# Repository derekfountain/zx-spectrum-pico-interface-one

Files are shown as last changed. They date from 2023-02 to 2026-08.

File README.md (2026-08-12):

# ZX Spectrum Expansion System, Recreated

**Update August'26:
Following recent interest in this project I've been
making a few interfaces up so people can buy them. The [project page](https://www.derekfountain.org/zses.php)
on [my personal website](https://www.derekfountain.org/) has the details
on how to get hold of one.**

**<derek@scratters.com>**

## An Interface One / Microdrive Emulation for the ZX Spectrum

This device plugs into the back of a 48K ZX Spectrum and provides the
functionality of the original 1984 "ZX Spectrum Expansion System". It
emulates a ZX Interface One with 8 ZX Microdrives.

The device is completely compatible with all 1980s software. It uses no
ROM modifications or other hacks. To my knowledge there are no
limitations or caveats to its use.

The first version is complete and supports the ZX Microdrives as
designed; the RS232 and ZX Net features of the Interface One might follow.

The project is open source, open hardware design, distributed under the
GPL licence.

There's lots more information on the [project page](https://www.derekfountain.org/zses.php)
on [my website](https://www.derekfountain.org/).

Click through for a brief demonstration:

IMAGE ALT TEXT (http://www.youtube.com/watch?v=kph2aS7qcVc "ZX Spectrum Expansion System, Recreated")

https://www.youtube.com/watch?v=kph2aS7qcVc

## Status

As of September 2023, version 1.0 is complete:

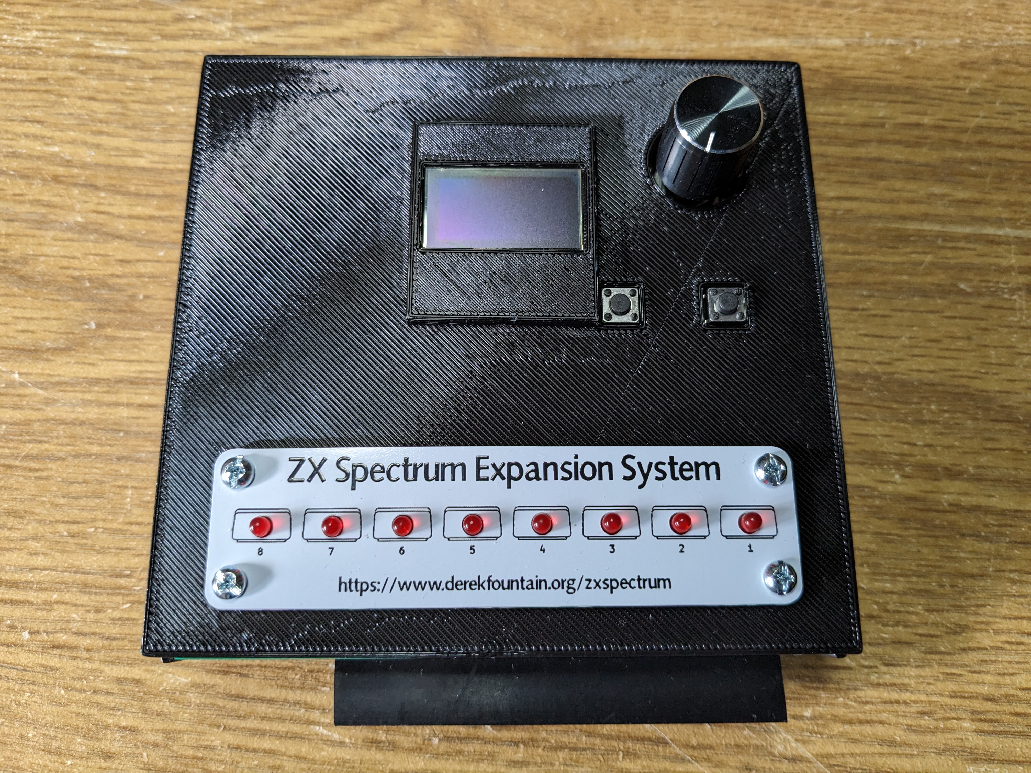
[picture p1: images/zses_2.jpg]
v1.0


It is functionally complete:

* Spectrum can read and write all 8 microdrives
* Uses "MDR" image format for "cartridges", fully compatible with emulators
* Full ZX Interface One ROM support, all native BASIC commands and extensions work as designed
* MDR files loaded from, and saved back to, SD card
* User interface uses file selector to choose and "insert" a cartridge
* Cartridge eject, allowing cartridges to be changed as required
* Configuration file allows auto-insertion of selected cartridges at start up

I'd be interested to receive feedback from anyone who tries to build one.

[Derek Fountain](https://www.derekfountain.org/), September 2023

# Operation

It should be fairly obvious. Select the Microdrive with the rotary encoder, click the right
button to bring up the file selector, use the rotary to select a cartridge file, then click the right button
again. The left button cancels.

The file selector only brings up files named *.mdr, and it doesn't do subdirectories. This
could be improved.

If you create a file in the root of your SD card called zxes_config.txt (that's not a
typo, I have an issue open to rename that file to match the rest of the project) and
enter up to 8 lines, each with a filename giving the name of an MDR file on your SD card,
those cartridge images will be loaded into the Microdrives on startup. (Startup meaning the
Pico startup, not the Spectrum start up.)

# Build Guidance

If you want to have a go at building one, please ensure you check out the open issues first.
There are a few, um, anomalies, which you might want to consider or work around. If I do
another spin of the boards I should be able to clear these up.

That said...

The KiCad files for the main board are in /srom/srom.kicad_pro. (The project started off as a port
of my [Spectrum Pico ROM](https://github.com/derekfountain/zx-spectrum-pico-rom), and the directory
name got ported over.)

The KiCad files for the top board (the daughter board with the screen and buttons) are in
/ui_daughterboard/ui_daughterboard.kicad_pro.

The silver faceplate is a (non functional) PCB. I had JLCPCB make it up in aluminium. The design
for that is in with the case design: /3d_print/top_panel/top_panel.kicad_pro.

All my surface mount component footprints are metric 3216 sized (1206i). Those are easy to hand solder.

The OLED screen needs a SSD1306 chipset if you want to use my code. Be careful, some SSH1106
based screens are labelled SSD1306. Those won't work without modifications to the code.

I've used long legged header sockets (female) to raise the top board well up above the Picos. If you
use the normal ones they probably won't be tall enough, unless you choose not to socket the Picos.

## Bill of Materials

You will need:

2x [74LVC245 Bus transceiver](https://www.mouser.co.uk/ProductDetail/595-SN74LVC245ANSR)
Bus transceiver, used as a level shifter
<br>
1x [3216 SMD Diode](https://www.mouser.co.uk/ProductDetail/581-SD1206S040S2R0)
Schottky Diode for Pico input protection
<br>
1x [4075 OR gate](https://www.mouser.co.uk/ProductDetail/595-SN74HCS4075DR)
3-way 3-input OR gate
<br>
4x [3216 SMD 0.1uF capacitor](https://www.mouser.co.uk/ProductDetail/581-12065C104KAT4A)
Decoupling capacitor
<br>
1x [PMBT2222A SMD Transistor](https://www.mouser.co.uk/ProductDetail/771-PMBT2222A-T-R)
NPN Transistor for /RESET
<br>
2x [3216 SMD 1K Resistor](https://www.mouser.co.uk/ProductDetail/603-RT1206FRE071KL)
1K Resistor for /RESET and /ROMCS2 pulldown
<br>
8x [3216 SMD 150R Resistor](https://www.mouser.co.uk/ProductDetail/603-RT1206FRE07150RL)
150R Resistor for data bus protection
<br>
1x [3216 SMD 330R Resistor](https://www.mouser.co.uk/ProductDetail/YAGEO/RT1206FRE07330RL)
330R Resistor for LED current limitation
<br>
1x [APS6404L-3SQR-PSRAM64Mbit Serial DRAM](https://www.mouser.co.uk/ProductDetail/878-APS6404L-3SQR-SN)
8MB SPI DRAM. A 1MB chip would probably be adequate.
<br>

Also, from your parts bin:

3x Raspberry Pi Pico with pins and sockets if you want them
<br>
1x 3-pin header and socket
<br>
1x 6-pin header and socket
<br>
1x 10-pin header and socket
<br>
1x KY-040 rotary encoder. Mine came with a 90degree header pin which I replaced with a straight header
<br>
1x 90degree ZX Spectrum Edge Connector socket. I went for [this one](https://www.ebay.co.uk/itm/394156247495).
<br>
2x SPST switch. Any single pole, single throw switch should do, they are the reset buttons.
<br>
1x Push-push type SD card reader. I used [this one](https://www.ebay.co.uk/itm/133222265884).
<br>
1x 0.96" OLED display (SSD1306 based)
<br>
8x 3.0mm red LEDs. The faceplate holes are drilled for 3.0mm LEDs.

# Acknowledgements

[Andrew Menadue](http://trochilidae.blogspot.com/)
for his Pico to Pico PIO [communications code](https://github.com/blackjetrock/picoputer),
and his patiently answering so many of my questions.

Geoff Wearmouth and others for their superb [IF1 ROM disassembly](https://www.derekfountain.org/misc/spectrum/if1_2.txt), which I suspect I now understand better than them.

Gergely Szasz, Philip Kendall and Stuart Brady from the
[FUSE Emulator Project](https://sourceforge.net/projects/fuse-emulator/).
[This](https://sourceforge.net/p/fuse-emulator/fuse/ci/master/tree/peripherals/if1.c)
one source file probably saved me weeks of work.

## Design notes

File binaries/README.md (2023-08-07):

# ZX Spectrum Expansion System, Recreated, Binaries

I had a couple of requests for pre-built UF2 files for the Picos.

This rather puzzled me since none of the code is any use without
the hardware, and I figured that anyone capable of building the
hardware would be capable of building the Pico's code.

No matter, I'm happy to provide them if people have a use for them.

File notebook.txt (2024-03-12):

ZX Spectrum Pico Interface One
==============================

Implement an Interface One using a Pico. Currently envisaged as a software only
microdrive emulator, providing a high volume storage facility the traditional
way. I wasn't planning doing an actual Microdrive emulation, or the network.

Pico-1 Emulates the IF1 ROM
===========================

Error Handling
--------------

The Service Manual says the Spectrum transfers to address 0x08 when it hits an
error. Putting a breakpoint on that address in Fuse shows it gets hit a various
points. Enter garbage and it gets hit when you'd expect to see the ? symbol come
up. It gets hit at the "D Break - CONT repeats" message. It seems to be the
standard error handler point.

0x08 is called via a RST 8 instruction. That's got CALL semantics, it PUSHes the
PC ready for a RET.

There's a disassembly of the IF1 ROM here: https://www.derekfountain.org/misc/spectrum/if1_2.txt

The IF1 hardware traps the address and Z80 lines when it goes to read an instruction from
address 0x08. Thus, when the ROM (or user program) calls that address the IF1 ROM is
already in place.

How does the ROM get paged?
---------------------------

Hardware looks for 0x0008.

AAAA AAAA AAAA AAAA
1111 1100 0000 0000
5432 1098 7654 3210

0000 0000 0000 1000
  *  *    ***   ***        Marked address lines are fed into IC3

That's bit A3 being one, all others being zero.

Also, hardware looks for 0x1708.

AAAA AAAA AAAA AAAA
1111 1100 0000 0000
5432 1098 7654 3210

0001 0111 0000 1000
  *  *    ***   ***        Marked address lines are fed into IC3

That's bit A3, A8, A9, A10 and A12 being one, all others being zero.

How does the ROM get unpaged?
-----------------------------

UNPAGE is at 0x0700 in the IF1 disassembly.

AAAA AAAA AAAA AAAA
1111 1100 0000 0000
5432 1098 7654 3210

0000 0111 0000 0000
  *  *    ***   ***        Marked address lines are fed into IC3

That's bits A8, A9 and A10 being one, all others being zero.

It contains a single RET instruction so the stack needs to have the required return
address ready. Assumption is that the IF1 ROM is unpaged when address 0x0700 has been
read. Not sure how.

From Kiwi at Spectrum Computing:

There are three addresses where the paging mechanism kicks in:

0x0008 - error RST - page in
0x1708 - channel handler - page in
0x0700 - page out

The LS260 NOR gates, diode AND gate and ULA decode these addresses
along with M1 and MREQ to determine when a paging event occurs. If you
decode all the other address bits then A3 indicates if the shadow ROM
should be paged in or out.

In hardware terms, the paging mechanism can be thought of as a two
stage process. The first stage flags if a paging event has occurred -
it decodes the address bits, MREQ and M1 and uses the signal as a
clock input to a LS74 flip flop, with A3 being the data input. The
second stage delays the actual paging of the ROM to the next
instruction. It does this with a second flip flop where the clock
input is the falling edge of M1 and data is the stage 1 page flag. The
combined mechanism recognises the page address and delays the ROM page
until the next M1 cycle (when it pages immediately).

This means that the CPU picks up the return instruction in the IF1 ROM
at 0x0700, executes the instruction (changing the PC), and the on CPU
setting up the address bus to get the instruction at the new PC
location, i.e. M1 active, the IF1 ROM pages out immediately meaning
the CPU picks up the value from the 48K ROM/RAM and normal execution
continues.

Pcio-1 Conclusion
-----------------

This is implemented in my ROM emulator. It requires the entire Pico,
all 26 GPIOs. The magic address ROM paging is done in software.

Proven working, final version needs the /M1 signal which I've got in
place on the schematic.

Pico-2 Emulates the IF1 Hardware
================================

Data Bus (8 GPIOs required)
---------------------------

8 lines required, all need level shifting and direction swapping. Input from ZX is needed
for the IF1 to receive the data to be written to the microdrive. Output to the ZX is
needed for the ROM emulation and to pass read data out to the ZX.

The ROM emulation only needs output data lines. The ROM emulator project ties the
direction of the level shifter to Pico->ZX. That needs changing because Pico-2 needs
to handle INs (Pico->ZX) and OUTs (ZX->Pico).

Z80 Control Bus (3 GPIOs required)
----------------------------------

The ROM part uses /MREQ; Pico-2 needs /IORQ.

/RD and /WR  are required so Pico-2 can tell when it needs to field an IN or an OUT.

Pico-1 only needs Pico->ZX, which is B->A, which is low on the pin. Pico-2 needs
both directions. But I can't have Pico-1 driving the data bus when Pico-2 wants
it, so I need to update the ROM emulation software to keep the data bus GPIOs as
inputs until they need to output their value.

The data bus level shifter should be permanently enabled. I'll tie /RD to the
shifter's direction pin then a read from ROM or a read of the IO space will set the
shifter to Pico->ZX, switching straight back when the read finishes. The ROM code
(Pico-1) needs to keep the data bus GPIOs as inputs while it's not supplying a data
byte. A write-to-ROM won't change the level shifter, so that scenario is harmless.
ROM_ACCESS_INV now appears redundant.

One issue: one of the Picos will have it's databus GPIOs set as outputs. When the
Z80's read finishes the /RD will go high and the level shifter will drive its
3V3 side as outputs. I don't want both Pico and level shifter driving each other,
but there's no easy alternative. So I'll put some resistors inline to prevent
too much current flowing from one device to the other. It'll only be brief, I
think it'll be OK.

Pico-3 Handles the user interface
=================================

Currently assuming an SD card reader and an LCD screen. Some buttons or a rotary?
Not sure. This comes later.

I think this is the one AM uses:

https://github.com/carlk3/no-OS-FatFS-SD-SPI-RPi-Pico/tree/sdio

How does Fuse code work?
========================

The Z80 opcode handler for IN uses a function called readport(). That's in periph.c, it loops
over a list of 'port' structures calling a function called read_peripheral(). That looks at
the list entry and the port being read by the Z80 and calls the handler function for either
a port read or a port write if the IN instruction the Z80 is running matches what's been
registered. The IF1's port input and output functions are if1_port_in() and if1_port_out():

static const periph_port_t if1_ports[] = {
  { 0x0018, 0x0010, if1_port_in, if1_port_out },
  { 0x0018, 0x0008, if1_port_in, if1_port_out },
  { 0x0018, 0x0000, if1_port_in, if1_port_out },
  { 0, 0, NULL, NULL }
};

Putting a breakpoint on one and doing a CAT 1 command gives:

(gdb) bt
#0  if1_port_in (port=24559, attached=0x7fffffffdc46 "") at peripherals/if1.c:787
#1  0x0000555555588aad in read_peripheral (data=<optimised out>, user_data=0x7fffffffdc44) at periph.c:304
#2  0x00007ffff7154b20 in g_slist_foreach () at /lib/x86_64-linux-gnu/libglib-2.0.so.0
#3  0x0000555555589057 in readport_internal (port=24559) at periph.c:344
#4  readport_internal (port=<optimised out>) at periph.c:312
#5  0x00005555555891a4 in readport (port=port@entry=24559) at periph.c:277
#6  0x00005555555ed965 in z80_do_opcodes () at ./z80/opcodes_base.c:944
#7  0x000055555558001d in main (argc=<optimised out>, argv=<optimised out>) at fuse.c:203

Decoding the port gives 1 of 3 responses:

static enum if1_port
decode_port( libspectrum_word port )
{
    switch( port & 0x0018 ) {
    case 0x0000: return PORT_MDR;
    case 0x0008: return PORT_CTR;
    case 0x0010: return PORT_NET;
        default: return PORT_UNKNOWN;
    }
}

0xF7 & 0x18 gives 0x10, so port 0xF7 is PORT_NET  (network)
0xEF & 0x18 gives 0x08, so port 0xEF is PORT_CTR  (control)
0xE7 & 0x18 gives 0x00, so port 0xE7 is PORT_MDR  (microdrive)

The one I want is the MDR one, so if1_port_in() for a read calls port_mdr_in(). Which 
is this:

static libspectrum_byte
port_mdr_in( void )
{
  libspectrum_byte ret = 0xff;
  int m;

  for( m = 0; m < 8; m++ ) {

    microdrive_t *mdr = &microdrive[ m ];

    if( mdr->motor_on && mdr->inserted ) {

      if( mdr->transfered < mdr->max_bytes ) {
	mdr->last = libspectrum_microdrive_data( mdr->cartridge,
						   mdr->head_pos );
	increment_head( m );
      }

      mdr->transfered++;
      ret &= mdr->last;  /* I assume negative logic, but how know? */
    }

  }

  return ret;
}

So for each microdrive, if it's on and inserted, read some data, increment the head
position. This seems to work with the idea that more than one microdrive can be
running, which is not possible in hardware as far as I know. Nevertheless, it merges
the bytes read from each device and that's what it returns. It also returns the next
byte in the data sequence (i.e on the tape) for each IN instruction.

I think what's happening is that each IN instruction is assumed to be reading the
next byte from the IF1 ULA. The IF1 does all the timing stuff, then says right,
/now/ is the time to read the next data byte from the stream. And that's what it
gets. In practise it doesn't matter what timing it puts in place, it'll get the next
byte in the stream regardless.

Logic to operate the level shifter
==================================

To switch the level shifter on the data bus to output mode (Pico->ZX) the ROM
read negative logic is

!(MREQ OR A14 OR A15 OR RD)

So if A14/5, or MREQ, or RD are high, keep it at input mode (ZX->Pico).
Otherwise pull it low (Pico->ZX).

So that's

(MREQ AND A14 AND A15 AND RD)

The IO Pico also needs to be able to switch that level shifter to output
mode (Pico->ZX)

(IORQ AND RD)

So if it's an IO, and it's a read, pull the level shifter direction low
(Pico->ZX).

So that's

!(IORQ OR RD)

/MREQ  A14  A15  DIR           /IORQ  /RD      DIR
  0     0    0    0               0    0        0         IO read (IN instruction)
  0     0    1    1               0    1        1         IO write (OUT instruction)
  0     1    0    1               1    0        1         Mem read
  0     1    1    1               1    1        1         Mem write
  1     0    0    1               
  1     0    1    1               
  1     1    0    1               
  1     1    1    1               

DIR = ( (MREQ OR A14 OR A15) AND (IORQ OR RD) )

gpios_state when broken on OUT 223,0     0x1C507A00
0b11100010100000111101000000000

  0 0000 1111 0000 0111 1111 0000 0000 = 0x00F07F00 is the mask
0b1 1100 1101 0000 0111 1010 0000 0000
         AAAA xxxx xAAA AWRI xxxx xxxx
         7654       321 0RDO
                           R

One clock cycle on 3.5MHz Z80 is 285ns. IORQ is down for 2.5 clocks, which is
about 715ns. That lines up perfectly with the scope trace.

Cartridge Loading
=================

Pico2
-----

typedef struct _md_flash_slot
{
  uint8_t                cartridge_present;
  libspectrum_microdrive cartridge;
}
MD_FLASH_SLOT;

On start up force empty slots. A new installation will set the 8 flash
slots with cartridge_present=0 and zeroes in the cartridge structure.
Pico3 can hold persistent MDR data and re-insert the last cartridges
used if necessary.

Like Fuse, start with everything empty, the UI Pico will need to load
MDR images, either through the GUI or via an auto-restore thing.

For test purposes, keep an MDR image in Pico2 flash. Load that into
slot 1 on startup. Need to check the "MD not present" thing works if
this is skipped, so might need a dummy image for loading into RAM.

On motor_on, load from slot 1 into RAM. For test, only use the first
slot (MD 1).

New cartridge takes a slot, 1 to 8, do whatever Fuse "Insert new" does.
I could save a new (unformatted) image in Fuse for this. Probably easier
to build what it wants in memory.

On motor_on, memcpy() from flash slot into RAM slot.
On motor_off, memcpy() from RAM back to flash slot.
 Fuse.

I don't think I can do automatic Pico2 flash back to Pico3 SD card.
It'd need doing on every sector write. So that leaves the Fuse model:
the user will have to choose Save for each cartridge image. Maybe
add a single button to save all cartridges back to SD.

* Insert new
* Insert
* Eject
* Save to SD card
* Save As to SD card
* Write protect enable/disable

The FORMAT Issue
================

Disassembly:

https://www.tablix.org/~avian/spectrum/rom/if1_2.htm#L1B5D

Start the motor, check for write protect.

https://www.tablix.org/~avian/spectrum/rom/if1_2.htm#L1B75

Enable writing - don't know what this does. Apparently nothing.

Creates an unuable record: header, record, EOF, checksum

It then works down from sector number 255 to 0

  Writes out a header
  Small gap
  Writes out record https://www.tablix.org/~avian/spectrum/rom/if1_2.htm#L16AF writes the 0xFC
  Small gap
  Loop back to do all 255

All sectors from 255 down to 1 have been written
THIS APPEARS TO WORK

https://www.tablix.org/~avian/spectrum/rom/if1_2.htm#L1BDF

Turn on appropriate drive motor

Counter to 50
  Read next header from heads
  Check whether sector read is free in the map
  If sector is free, or bad read, or bad checksum
    Move to next sector
  Else
    Mark sector as usable in sector map

https://www.tablix.org/~avian/spectrum/rom/if1_2.htm#L1C35

;   Now prepare to overwrite the unusable sectors (which are mapped as usable)
;   with record descriptors which are usable.

Updates the in-memory sector image with a useable one

https://www.tablix.org/~avian/spectrum/rom/if1_2.htm#L1C40

https://www.tablix.org/~avian/spectrum/rom/if1_2.htm#L15B3

Write usable block to next free sector
Mark map showing sector is now used

OTIR is here:
https://www.tablix.org/~avian/spectrum/rom/if1_2.htm#L15D0

New version based on smaller RP2040 board
=========================================

I tried to find a way to reliably solder the RP2040 package using the tools
I have (iron and hot air). I failed. Next version will therefore have to 
be based on a 3rd party mini RP2040 board. Options:

Pimoroni Tiny 2040, Seeed XIAO and Waveshare RP2040 Tiny all have limited GPIOs.
Those are therefore no use, I need all GPIOs.

Adafruit Feather and Waveshare RP2040 Plus are both Pico sized boards.

Solder Party Stamp looks ideal, but it's £10, plus £10 shipping from Sweden.
It's open source, but I couldn't work out how to get JLCPCB to quote for
manufacturing it based on KiCAD sources.

Waveshare RP2040 Zero looks good, only some of the GPIOs are on solder pads
on the underside of the board. Bit of a pain, but I could manage with that,
I think. £10 on Amazon, cheaper elsewhere, and £3 or less for non-Waveshare
knockoffs on AliExpress.

PGA2040 looks good, all GPIOs are broken out. It has the crystal and flash
in place. £7.50 from Pimoroni, plus about £.50 shipping, so still not
outrageous. This looks like the one to use.
https://shop.pimoroni.com/products/pga2040?variant=39359629656147
Discussion:
https://forums.raspberrypi.com/viewtopic.php?t=334099

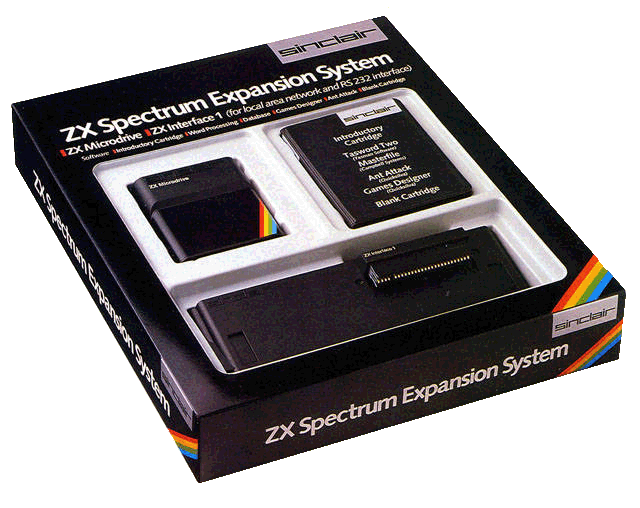
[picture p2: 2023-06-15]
docs/zx-spectrum-expansion-boxed.gif

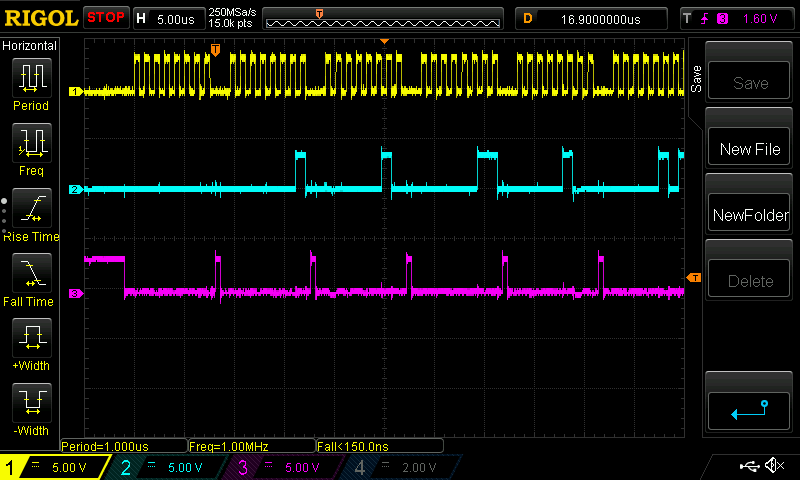
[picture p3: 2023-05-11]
images/ui_to_io_spi.png

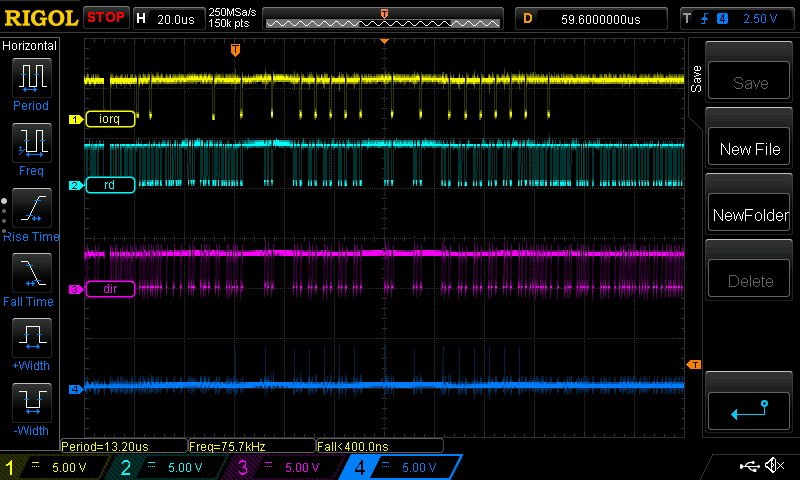
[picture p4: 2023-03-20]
images/cat1_1633_1_15INIRs.png

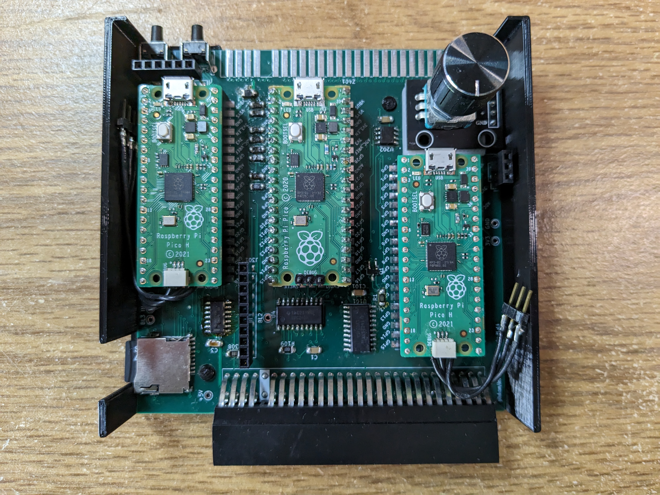
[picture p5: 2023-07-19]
images/picos.jpg

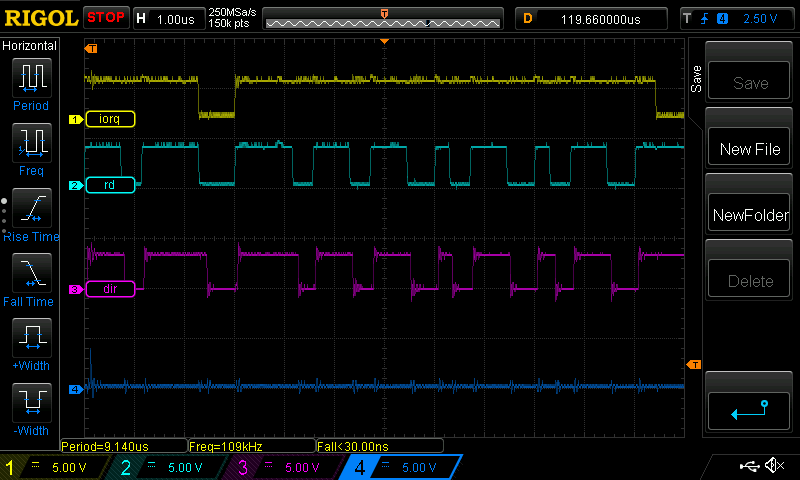
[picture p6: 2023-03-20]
images/cat1_1633_5_gapToFinalOUT.png

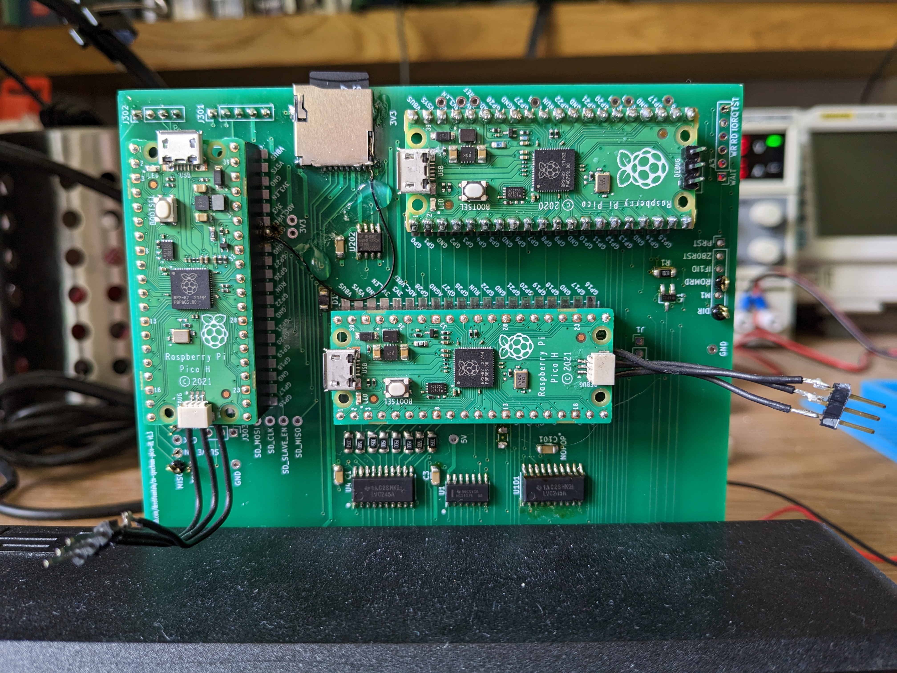
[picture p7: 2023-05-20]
images/prototype2.jpg

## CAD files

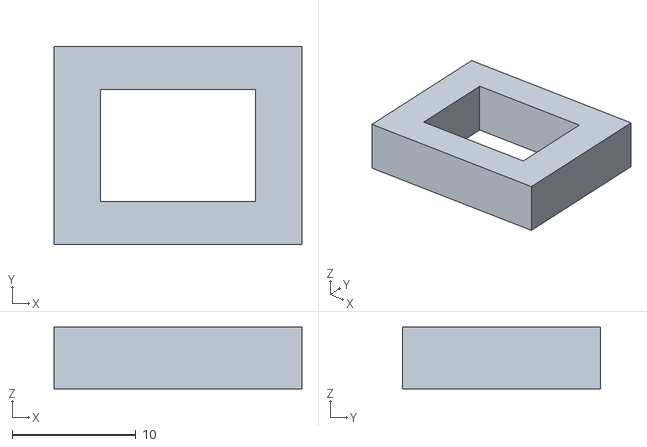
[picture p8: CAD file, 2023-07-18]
3d_print/case/spectrum_riser.stl
20.0 x 16.0 x 5.00

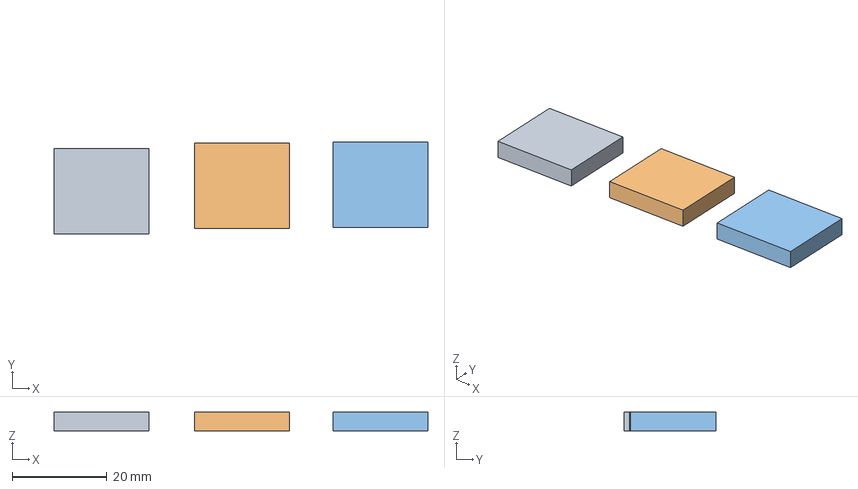
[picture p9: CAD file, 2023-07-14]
3d_print/pcb_sandwich_spacer/pcb_spacer.3mf
78.8 x 19.4 x 4.00 mm

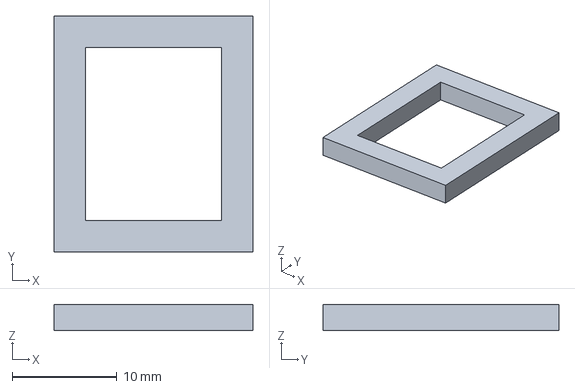
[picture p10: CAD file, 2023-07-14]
3d_print/rotary_spacer/rotary_spacer.3mf
19.0 x 22.5 x 2.50 mm

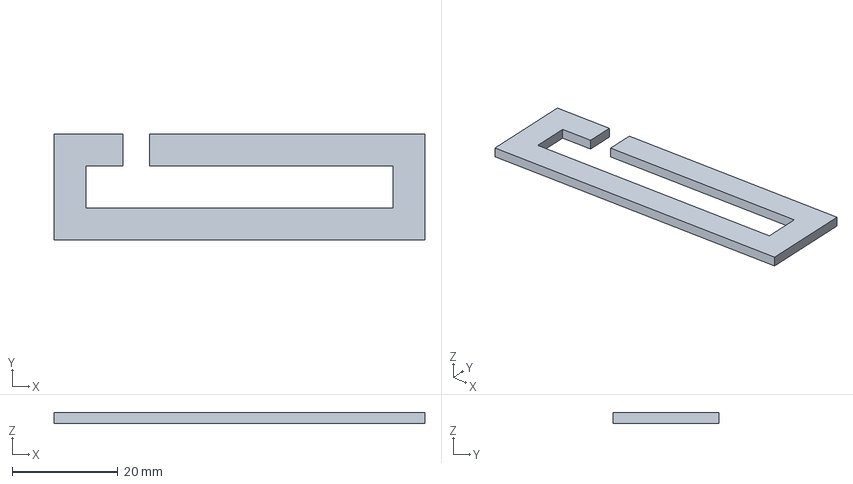
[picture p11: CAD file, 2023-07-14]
3d_print/top_panel_spacer/spacer.3mf
70.0 x 20.0 x 2.00 mm

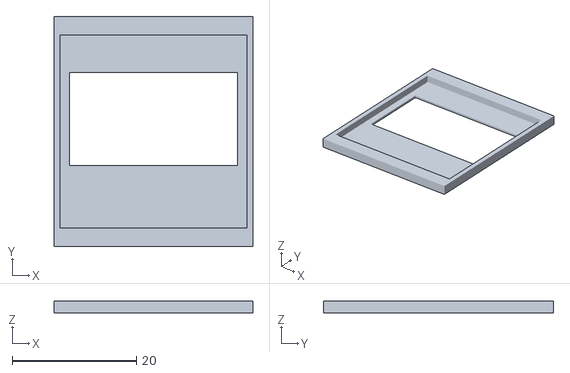
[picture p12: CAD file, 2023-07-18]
3d_print/case/frame.stl
32.0 x 37.0 x 2.00

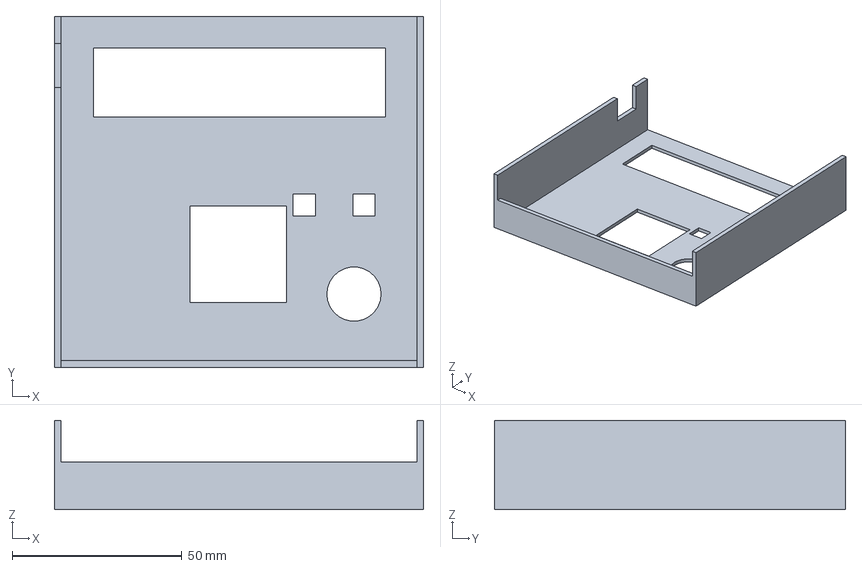
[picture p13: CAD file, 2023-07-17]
3d_print/case/upper_case.3mf
108.9 x 103.5 x 26.2 mm

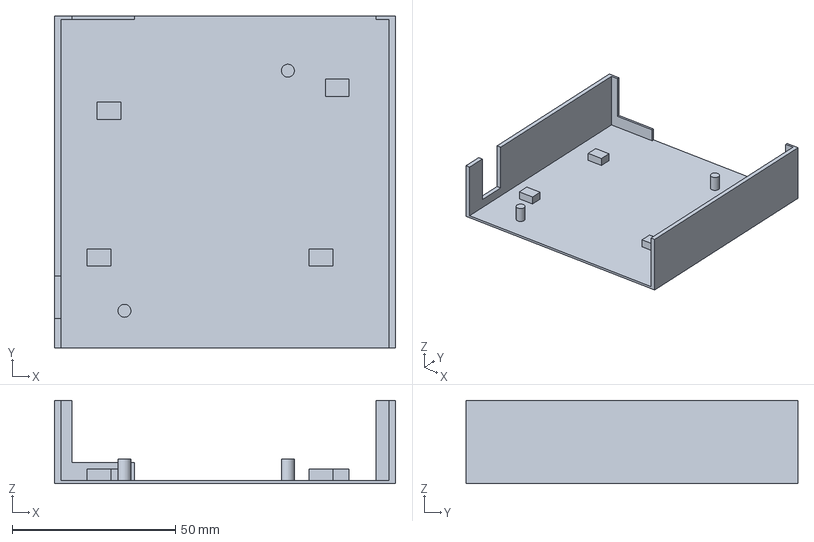
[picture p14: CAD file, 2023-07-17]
3d_print/case/lower_case.3mf
104.5 x 101.6 x 25.5 mm

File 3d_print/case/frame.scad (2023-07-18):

case_aperture_width=30.0;
case_aperture_length=31.0;

side_border_width=1.0;
top_border_width=3.0;
bottom_border_width=3.0;

frame_width=side_border_width + case_aperture_width + side_border_width;
frame_length=top_border_width + case_aperture_length + bottom_border_width;

screen_width=27.0;
screen_length=15.0;

screen_hole_xpos=(frame_width-screen_width)/2;
screen_hole_ypos=bottom_border_width + 10.0;

frame_height=0.5;

difference()
{
  cube([frame_width, frame_length, frame_height]);

  // Knock out the screen hole
  //
  translate([screen_hole_xpos, screen_hole_ypos, 0])
  {
    cube([screen_width, screen_length, frame_height]);
  }
}

translate([0, 0, frame_height])
{
  frame_raise=1.5;
  difference()
  {
    cube([frame_width, frame_length, frame_raise]);
    
    translate([side_border_width, bottom_border_width, 0])
    {
      cube([frame_width-(side_border_width*2),
            frame_length-bottom_border_width-top_border_width,
            frame_raise]);
    }
  }
}

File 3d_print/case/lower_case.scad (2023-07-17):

pcb_width=99.85;                // Across the back of the ZX, as per KiCAD PCB layout
pcb_length=99.96;               // ZX edge connector to rear of PCB, as per KiCAD PCB layout
side_wall_thickness=2.0;        // Left and right side walls
far_wall_thickness=1.0;         // Wall at rear of device, might obstruct plugging in
closest_wall_thickness=0.0;     // Wall closest to ZX, might obstruct plugging in

// Base mustn't be too high, PCB will lift as it is. 0.5mm printed as 0.7mm,
// but it's too flimsy, it needs to be thicker than that. There are no front
// or rear walls anymore
//
base_thickness=1.0;

// The walls need to be high enough such that the lid sits on the tops of
// the walls, not on the components or connector tips of the top board.
//
walls_height=27.5;

// These are from the rear edge, which is slightly wider than the front
//
right_side_edge_offset=3.7;     // Edge connector slot, from right side
left_side_edge_offset=22.2;     // Edge connector slot, from left side

spacing=0.33;                   // Bit of slack to ensure things fit together

base_width=side_wall_thickness + spacing + pcb_width + spacing + side_wall_thickness;
base_length=closest_wall_thickness + spacing + pcb_length + spacing + far_wall_thickness;

pcb_aperture_width = spacing + pcb_width + spacing;
pcb_aperture_length = spacing + pcb_length + spacing;

// The device PCB lies flush with the bottom plastic of the Spectrum's case. 
// Given there are the soldered tips of the through hole devices poking through
// the PCB, and that the PCB must be raised up about 4mm at the rear to give
// clearance for another interface to be plugged in rear, the PCB needs to stand
// clear of the base of its case by about 4mm.
// This means the rear of the Spectrum will need to be raised up and supported
// from underneath, like the IF1 but on a smaller scale. I'll create a new
// support for that.
// Original case was 5mm, but it can sit a bit lower than that.
//
standoff_height=3.5;

locating_post_height=standoff_height + 4;
locating_post_hole_diameter=4.3;
locating_post1_xpos_centre=19.11;
locating_post1_ypos_centre=11.01;
locating_post2_xpos_centre=69.2;
locating_post2_ypos_centre=84.6;

sd_card_offset=8.0;             // From front edge of board to SD card reader
sd_card_width=13.0;             // Width of the SD card reader I'm using, inc solder tabs

switches_offset=3.0;            // From left side to left edge of first switch

// This needs to be about 16mm, but that leaves a thin little post between the
// switches aperture and the rear edge connector aperture. That will be hard to
// print with any strength. So I made the switches aperture a bit wider to open
// it out.
//
switches_width=20.0;            // Width of aperture to allow both switch buttons through

$fn=64;

// Build the shell
//
difference()
{
  // Basic cube
  //
  cube([base_width,base_length,walls_height], false);
  
  // Cut out the middle, PCB drops into here
  //
  translate([side_wall_thickness, closest_wall_thickness, base_thickness])
  {
    cube([pcb_aperture_width,pcb_aperture_length,walls_height], false);
  }
  
  // Cut out front wall for the edge connector
  //
  edge_xpos = side_wall_thickness + spacing + left_side_edge_offset;
  edge_width=pcb_width - left_side_edge_offset - right_side_edge_offset;
  edge_wall=3.0;
  translate([edge_xpos, 0, base_thickness+edge_wall])
  {
    cube([edge_width,closest_wall_thickness,walls_height], false);
  }

  // Cut out rear wall for the passthrough connector
  //
  far_wall_ypos=closest_wall_thickness + spacing + pcb_length + spacing;
  translate([edge_xpos, far_wall_ypos, base_thickness])
  {
    cube([edge_width,far_wall_thickness,walls_height], false);
  }
  
  // Cut out side wall where the SD card reader pokes through
  //
  sd_cutout_wall_height=4;
  translate([0, sd_card_offset, base_thickness+sd_cutout_wall_height])
  {
    cube([side_wall_thickness,sd_card_width,walls_height], false);
  }
  
  // Cut out rear wall where the reset switches poke through. Leave a 
  // small amount of the wall to help locating rear interfaces
  //
  switches_aperture_edge=side_wall_thickness+spacing+switches_offset;
  switches_wall_height=standoff_height+2;
  translate([switches_aperture_edge, far_wall_ypos, base_thickness+switches_wall_height])
  {
    #cube([switches_width,far_wall_thickness,walls_height], false);
  }
  
}

// Make posts slightly smaller than the hole so device fits over it
//
locating_post_diameter=locating_post_hole_diameter-spacing;

translate([side_wall_thickness+spacing+locating_post1_xpos_centre,
           closest_wall_thickness+spacing+locating_post1_ypos_centre,
           0])
{
  cylinder(locating_post_height, locating_post_diameter/2, locating_post_diameter/2, false);
}

translate([side_wall_thickness+spacing+locating_post2_xpos_centre,
           closest_wall_thickness+spacing+locating_post2_ypos_centre,
           0])
{
  cylinder(locating_post_height, locating_post_diameter/2, locating_post_diameter/2, false);
}

// Add some blocks to raise the PCB up a bit. Location of these isn't really
// important, one in each corner will do. But getting one under the rotary
// will a bit of strength there. 
//
block_width=side_wall_thickness + spacing + 5;
block_length=closest_wall_thickness + spacing + 5;
block_height=standoff_height;

// Front left
//
block1_xpos=10;
block1_ypos=25;
translate([block1_xpos, block1_ypos, base_thickness])
{
  cube([block_width, block_length, block_height], false);
}

// Rear left
//
block2_xpos=13;
block2_ypos=70;
translate([block2_xpos, block2_ypos, base_thickness])
{
  cube([block_width, block_length, block_height], false);
}

// Front right
//
block3_xpos=78;
block3_ypos=25;
translate([block3_xpos, block3_ypos, base_thickness])
{
  cube([block_width, block_length, block_height], false);
}

// Rear right
//
block4_xpos=83;
block4_ypos=77;
translate([block4_xpos, block4_ypos, base_thickness])
{
  cube([block_width, block_length, block_height], false);
}

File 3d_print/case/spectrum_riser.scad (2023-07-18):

difference()
{
  cube([20.0, 16.0, 5]);
  
  translate([7.5/2, 7.0/2, 0 ])
  {
    cube([12.5, 9.0, 5]);
  }
}

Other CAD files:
3d_print/case/upper_case.scad
3d_print/case/lower_case.stl
3d_print/case/upper_case.stl
3d_print/pcb_sandwich_spacer/pcb_spacer.scad
3d_print/pcb_sandwich_spacer/pcb_spacer.stl
3d_print/rotary_spacer/rotary_spacer.scad
3d_print/rotary_spacer/rotary_spacer.stl
3d_print/top_panel_spacer/spacer.scad
3d_print/top_panel_spacer/spacer.stl

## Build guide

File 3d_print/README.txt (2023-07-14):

I made the PCB board 100mm x 100mm, since JLC are much cheaper
if you remain inside that size.

The board has 3 female header sockets, a long one for the 8 LED
signals, one at the back for the screen, and one on the right side
which isn't connected to anything. (The rotary is mounted on the
main board.)

LEDs, buttons and screen mount on the daughterboard which fits on
top of the main board.

There's a nice aluminium panel for the top surface, with drilled
LED holes and screen print. These are cheap on JLC, just remember
to turn off the testing. Round the corners, needs 4 screw holes
in the corners.

Any components needed on the daughterboard board can go on the
underside. That will allow the aluninimum panel to lay on top.

ADDITIONAL: I've done the aluminium plate, but I'm not sure how the
red LEDs will look against the silver. Might as well make a black
one as well so I can choose.

Height, assuming Picos in header sockets, would be about 20mm
from tip of pin on underside to top surface of Pico. The Spectrum
is just over 30mm, so I'll make the case flush with the top of
the Spectrum.

From TomD:

"My side walls are 2mm thick and I find this strong enough for most
use cases. The case does have a little flex but that is preferred to
something totally rigid. Also need to be careful on the part closest
to the Spectrum as too thick will mean the connector cannot go in far
enough. I made the top and bottom 1mm thick to give as much room as
possible. Overall the case isn't IF2 sturdy, which is probably 3mm
thickness, but easily good enough."

Good point about the edge connector fouling.

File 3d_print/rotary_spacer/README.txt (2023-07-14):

The rotary encoder is a standard KY-040, but those come with
a connector with a 90deg bend in it. The knob sits horizontally.
I want the knob to sit vertically, so I desolder the connector
and solder on a normal 5-pin header. That then solders onto the
main PCB.

The problem then is that the encoder sits a few mm above the PCB,
separated from it by the plastic bit of the header pins. What it
needs to make it sturdy is a small spacer to fit underneath the
encoder's small PCB. Which is what this is.

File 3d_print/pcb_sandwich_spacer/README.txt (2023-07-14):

A simple spacer to separate the two PCBs at the right distance
apart when soldering the long legged, female sockets.

Solder the header pins protruding from the bottom of the top
layer (the daughterboard). Plug the female sockets onto them.
Line up the boards and thread the legs of the female sockets
into their holes on the main PCB.

Now insert these spacers between the boards at convenient
locations, preferably near the headers/sockets. The gap between
the boards should be 18mm (as of this writing). Clamp the two
boards into position and solder the legs of the female sockets
from the underside of the main PCB. Remove the spacers, the
soldered pins should be strong enough to hold the two boards
in position.

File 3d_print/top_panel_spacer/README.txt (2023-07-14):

The top panel is a metal plate which sits over the top of the
larger connector which joins the main PCB to the daughterboard.
If the metal plate touches down on the top tips of that connector
it'll short them out.

I made this spacer to fit underneath the metal plate to raise it
up 2mm, which is high enough to lift it clear of the connector.

Put it in place, put the LEDs in their holes, put the metal plate
on top with the LEDs poking though. Fiddly, use tweezers to line
the LEDs up. Then nut and bolt each corner of the plate, check 
the spacer is in position, then screw down and threadlock the
nuts.

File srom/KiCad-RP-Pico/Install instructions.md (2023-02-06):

# Install instructions

## 1. Copy the files locally

Copy the `RP-Pico Libraries` folder wherever you like on your computer.

## 2. Install the Raspberry Pi Pico board schema symbol

Use the `KiCad | Preferences | Manage Symbol Libraries...` command to manage the symbol library:

symbol library manager

then select the global tab and click on the folder button:

symbol library manager

navigate to the `RP-Pico Libraries` folder, select the `MCU_RaspberryPi_and_Boards.kicad_sym` file and open it:

symbol library manager

et voilà, the first step is completed:

symbol library manager

You can now close the symbol libraries manager window.

## 3. Install the Raspberry Pi Pico board footprint

You can use a similar approach to add the footprint to the footprint libraries manager, but I've found some issues that I've solved using the footprint editor, so here are the steps I suggest you to follow:

Open the footprint editor

symbol library manager

wait for the footprints to load... then use the `File | Add Library` command:

symbol library manager

confirm the `Global` choice:

symbol library manager

and select the `MCU_RaspberriPi_and_Boards.pretty` folder (yes, the folder represent a footprint library on KiCad):

symbol library manager

Now the library is installed on KiCad with the Raspberry Pi Pico footprint (double click on it to see it on the editor pane):

symbol library manager

Don't close the windows as the next step start from here.

## 4. Install the Raspberry Pi Pico board footprint 3D visual

If not already open, open the the footprint editor

symbol library manager

double click on the `RPi_Pico_SMD_TH` footprint from the `MCU_RaspberriPi_and_Boards` library and then click on the `Footprint properties` icon:

symbol library manager

In the footprint properties window, first select the `3D Settings` tab. Please note that the preview shows only the PCB board with the footprint added on step 3, without any 3D representation of the Raspberry Pi Pico board. Now click on the folder icon to add the 3D model:

symbol library manager

Navigate to the `RP-Pico Libraries` folder, select the `Pico.wrl` file and wait until the model is shown in the right panel, then confirm with OK:

symbol library manager

The model is already scaled and translated to match the footprint:

symbol library manager

now close the `Footprint Properties` window, and the `Footprint Editor`, obviously saving the changes.

## Conclusion

Now that you've installed the schema and footprint and added the 3D model to the footprint, you can use the Raspberry Pi Pico board on your KiCad projects.

I've also added a test KiCad Project on the `Test` folder, that you can use to see an example of it.

Have fun!

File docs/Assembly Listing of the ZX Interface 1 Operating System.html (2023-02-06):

; Disassembly of the file "C:\lab\if1-2.rom"
;
; CPU Type: Z80
;
; Created with dZ80 1.50
;
; on Sunday, 28 of April 2002 at 12:35 PM
;

; ------------------------
; last updated 14-JAN-2004
; ------------------------

#define DEFB .BYTE
#define DEFW .WORD
#define DEFM .TEXT
#define EQU  .EQU
#define ORG  .ORG

        ORG     $0000

; ---------------------------------------
; FLAGS3 System Variable - IY+$7C ($5CB6)
; ---------------------------------------
; Bit 0 - set when executing an extended command.
; Bit 1 - set during CRT-VARS and CLEAR #, CLOSE etc.
; Bit 2 - settable by User to force the ERR_SP routine to handle errors.
; Bit 3 - set when networking.
; Bit 4 - set during LOAD and MOVE
; Bit 5 - set during SAVE
; Bit 6 - set during MERGE
; Bit 7 - set during VERIFY
;
; Note. before initialization of FLAGS_3, this is considered to be the first
; byte of channels and so PEEK 23734 gives 244 decimal (%11110100) the high
; order byte of the Main ROM address PRINT-OUT - $09F4.
;
; -------------------------------------------

; --------------------------------
; THE 'RETURN TO MAIN ROM' ROUTINE
; --------------------------------
;   The system is initialized by the Main ROM so this address is accessed 
;   solely by a RST 00H instruction.  It is used from five locations to return 
;   to the Main ROM.

;; MAIN-ROM
L0000:  POP     HL              ; discard the return address in this ROM.
        LD      (IY+$7C),$00    ; reset all the bits of FLAGS_3.
        JP      L0700           ; jump forward to UNPAGE address.

; -------------------
; THE 'START' ROUTINE
; -------------------
;   An instruction fetch on address $0008 pages in this ROM.
;   The three-byte instruction at this location must exist on both sides of
;   the looking-glass.  The value fetched is immediately discarded.
;   It follows that this restart should never be invoked from this ROM.

;; ST-SHADOW
L0008:  LD      HL,($5C5D)      ; fetch character address from CH_ADD.
        POP     HL              ; pop return address to HL register.
        PUSH    HL              ; and save again on machine stack.

        JP      L009A           ; jump forward to continue at START-2.

; -----------------------------
; THE 'CALL A MAIN ROM' ROUTINE
; -----------------------------
;   Call an address in the main ROM. The address follows the restart so this
;   is as convenient and as brief as a CALL instruction.
;   The SBRT routine within the system variables area reads
;
;   L5CB9         LD      HL,value
;   L5C5C         CALL    addr
;   L5C5F         LD      (L5CB9+1),HL
;   L5CC2         RET
;
;   By immediately placing the current value of HL in the subroutine, then
;   all registers before the call are as they were before the RST
;   instruction.  The value of HL after the call is stored immediately in
;   this now redundant location so that, after this ROM is paged back in,
;   the registers, after the RST instruction has executed, are as they were
;   immediately after the CALL.
;   see START-2.

;; CALBAS
L0010:  LD      ($5CBA),HL      ; insert the current value of HL in the
                                ; Z80 code to be picked up later.

        POP     HL              ; drop the return address - the location
                                ; of address to be called.
        PUSH    DE              ; preserve the DE register contents.

        JR      L0081           ; forward to continue at CALBAS-2.

        DEFB    $FF             ; unused.

; ---------------------------------------------
; THE 'TEST IF SYNTAX IS BEING CHECKED' ROUTINE
; ---------------------------------------------
;   On the ZX80, testing the syntax flag was done with the 4-byte
;   instruction that tests the System Variable FLAGS.  On the ZX81 and
;   ZX Spectrum, a call to SYNTAX-Z reduced the invocation to a three-byte
;   CALL.   Here it is reduced to a one-byte restart.

;; CHKSYNTAX
L0018:  BIT     7,(IY+$01)      ; test most significant bit of FLAGS
        RET                     ; return the result.
                                ; (Z = Syntax, NZ = Run-time)

        DEFB    $FF             ; unused.
        DEFB    $FF             ; unused.
        DEFB    $FF             ; unused.

; --------------------------
; THE 'SHADOW-ERROR' ROUTINE
; --------------------------
;   This is similar to the Main ROM error handler and the following byte 
;   indicates the type of error and in runtime the message that should be
;   printed.  If checking syntax then the error pointer is set before a
;   return is made to the Main ROM.

;; SH-ERR
L0020:  RST     18H             ; checking syntax ?
        JR      Z,L0068         ; forward, if so, to ST-ERROR

        JR      L003A           ; forward, in run-time, to TEST-SP,
                                ; and then REP-MSG

        DEFB    $FF             ; unused.
        DEFB    $FF             ; unused.
        DEFB    $FF             ; unused.

; ------------------------------------
; THE 'MAIN ROM ERROR RESTART' ROUTINE
; ------------------------------------
;   This restart invokes the error handler of the Main 16K ROM.  The required 
;   error number is usually first placed in the System Variable ERR_NR.  In 
;   some cases the error code is already present and this restart is used when 
;   the error situations handled by this ROM have been eliminated.
;   Since the exit from this point is by manipulating the stack, the return 
;   address is of no importance as that route is never taken.  There are also
;   three conditional jumps back to this point.

;; ROMERR
L0028:  RES     3,(IY+$02)      ; update TV_FLAG - signal no change in mode.
        JR      L0040           ; forward to RMERR-2.

        DEFB    $FF             ; unused.
        DEFB    $FF             ; unused.

; -------------------------------------------------
; THE 'CREATE NEW SYSTEM VARIABLES RESTART' ROUTINE
; -------------------------------------------------
;    This restart is used the first time that that the ROM is paged in to
;    create the System Variables.  This will be either by an instruction
;    fetch on $0008 or $1708.

;; NEWVARS
L0030:  JP      L01F7           ; jump to CRT-VARS

        DEFB    $FF             ; unused.
        DEFB    $FF             ; unused.
        DEFB    $FF             ; unused.
        DEFB    $FF             ; unused.
        DEFB    $FF             ; unused.

; --------------------------------
; THE 'MASKABLE INTERRUPT' ROUTINE
; --------------------------------
;   There is no service routine but should the routine be called either
;   directly or by straying into a RST $38 instruction, then interrupts are
;   enabled.

;; INT-SERV
L0038:  EI                      ; Enable Interrupts
        RET                     ; return.

; ------------------------
; THE 'TEST SYSTEM' BRANCH
; ------------------------
;   This branch allows the user to trap errors before this ROM is used to print
;   the error report. 

;; TEST-SP
L003A:  CALL    L0077           ; routine CHECK-SP
                                ; usually returns.
        JP      L0260           ; jump to REP-MSG

; ----------------------------
; THE 'MAIN ROM ERROR' ROUTINE
; ----------------------------
;   a continuation of RST 28H.
;   This ROM has inserted a Main ROM error code into ERR_NR and the routine in 
;   the Main ROM is now invoked.
;   First a check is made to see if the user wishes to trap errors using a 
;   custom routine in ERR_SP.  This will be used in the syntax path anyway.
; 

;; RMERR-2
L0040:  RST     18H             ; checking syntax ?
        JR      Z,L0068         ; forward, if so, to ST-ERROR.

        CALL    L0077           ; routine CHECK-SP allows the user to trap 
                                ; run-time errors at this point but normally 
                                ; returns here.

        CALL    L17B7           ; routine RCL-T-CH reclaims any temporary
                                ; channels and stops all microdrive motors.

        BIT     1,(IY+$7C)      ; test FLAGS_3.
        JR      Z,L0068         ; forward, if executing CLOSE, to ST-ERROR.

        BIT     4,(IY+$7C)      ; test FLAGS_3 - loading filename 'run' ?
        JR      Z,L0068         ; forward, if not, to ST-ERROR.

;   As a security measure, the file 'run' can not be hacked.

        LD      A,(IY+$00)      ; fetch error number from the System Variable
                                ; ERR_NR.
        CP      $14             ; is it "CODE error" ?
        JR      NZ,L0068        ; forward, if not, to ST-ERROR.

;   The user has pressed BREAK while trying to load the program 'run'.

        LD      HL,$0000        ; cause a system reset.
        PUSH    HL              ; place address zero on machine stack.
        RST     00H             ; switch to MAIN-ROM.

;

        DEFB    $FF             ; unused
        DEFB    $FF             ; unused
        DEFB    $FF             ; unused
        DEFB    $FF             ; unused
        DEFB    $FF             ; unused

; ------------------------------------
; THE 'NON-MASKABLE INTERRUPT' ROUTINE
; ------------------------------------
;   There is no NMI functionality.

;; NMINT-SRV
L0066:  RETN                    ; return to previous interrupt state.

; --------------------------
; THE 'SYNTAX ERROR' ROUTINE
; --------------------------
;   An error has occurred during syntax checking so the position must be 
;   highlighted when a return is made to the Editor in the Main ROM.

;; ST-ERROR
L0068:  LD      HL,($5C5D)      ; fetch character address from CH_ADD.
        LD      ($5C5F),HL      ; set X_PTR to same to position error cursor.

        LD      SP,($5C3D)      ; set the Stack Pointer from ERR_SP.

        LD      HL,$16C5        ; prepare address of main SET-STK.
        PUSH    HL              ; push on the machine stack.

        RST     00H             ; switch to MAIN-ROM where SET-STK will clean up 
                                ; the work areas before returning to the Error 
                                ; Routine obtained from ERR_SP.

; ---------------------------------------
; THE 'CHECK ERROR STACK POINTER' ROUTINE
; ---------------------------------------
;   This allows the user's software to trap any errors at this point by setting 
;   the otherwise unused bit 2 of FLAGS_3 after inserting a custom error 
;   handler in the System Variable ERR_SP.
;   Both Shadow ROM situations and Main ROM situations can be trapped and the 
;   routine is called from BOTH RST 20H and RST 28H.

;; CHECK-SP
L0077:  BIT     2,(IY+$7C)      ; test FLAGS_3 has the user set up a custom
                                ; error handler in Main RAM ?
        RET     Z               ; return if not.

;   Otherwise the user, or the third party software, has set up a custom routine
;   in the system variable ERR_SP and set bit 2 of FLAGS_3 so that it is invoked
;   at this point.

        LD      SP,($5C3D)      ; set stack pointer from ERR_SP.
        RST     00H             ; switch to MAIN-ROM.

; ----------------------
; THE 'CALBAS-2' ROUTINE
; ----------------------
;   A continuation of the code at $0010.
;   Continue by picking up the address to be called, located after the RST
;   instruction and placing after the CALL instruction in the SBRT sequence.

;; CALBAS-2
L0081:  LD      E,(HL)          ; fetch low byte of called address
        INC     HL              ; advance pointer.
        LD      D,(HL)          ; fetch high byte.

        LD      ($5CBD),DE      ; place in the Z80 code SBRT
        INC     HL              ; increment pointer.

        EX      (SP),HL         ; transfer continuation address to machine
                                ; stack - and the stack value (was DE) to HL.

        EX      DE,HL           ; original DE value now restored.

        LD      HL,$0000        ; signal CALBAS routine in use.
        PUSH    HL              ; place on stack.

        LD      HL,$0008        ; address of main ERROR restart
        PUSH    HL              ; place on stack

        LD      HL,$5CB9        ; address of calling SBRT subroutine.
        PUSH    HL              ; place on stack.

        JP      L0700           ; jump to UNPAGE

; ---------------------
; THE 'CONTROL' ROUTINE
; ---------------------
;   A continuation of code at L0008. The return address has been dropped off
;   the machine stack into HL.
;
;   First see if this ROM was paged in as a result of the $0008 address
;   stacked during the CALBAS routine. (see above)

;; START-2
L009A:  PUSH    AF              ; preserve accumulator and status flags.

        LD      A,H             ; test HL for zero - the CALBAS
        OR      L               ; indicator value.
        JR      NZ,L00A5        ; forward, if not, to START-3.

        POP     AF              ; restore accumulator and flags.

        POP     HL              ; discard address stacked by RST 08.
        LD      HL,($5CBA)      ; pick up post-CALL HL value from SBRT.
        RET                     ; return.

;------------------------------------------------------------------------------
;   Now consider that the address $0008 may have been an input or output
;   routine that precedes the letter of one of the new channels.  These
;   paging addresses ensure that this ROM is paged in so that the real
;   input/output addresses can be read from the locations after the
;   channel's letter. In this case, the return address is towards the end
;   of the CALL-SUB routine in the Main ROM, i.e.
;   L15FB         CALL    $162C   ; routine CALL-JUMP (a JP (HL) instr.)
;   L15FE         POP     HL      ; return address
;------------------------------------------------------------------------------

;; START-3
L00A5:  PUSH    DE              ; preserve DE.
        LD      DE,$15FE        ; test against possible return address 0x15FE
        SBC     HL,DE           ; subtract (carry is clear)
        POP     DE              ; restore DE.
        JR      NZ,L00BC        ; forward with no match to START-4.

;   This ROM has been paged by an attempt to use a stream.

        POP     AF              ; restore accumulator.

        LD      HL,L0700        ; stack the address UNPAGE to switch to 
        PUSH    HL              ; the Main ROM afterwards.

        LD      HL,$0004        ; the shadow routine is 4 bytes forward
        ADD     HL,DE           ; adjust input/output address pointer.
        LD      E,(HL)          ; pick up low-order byte of I/O routine.
        INC     HL              ; bump pointer.
        LD      D,(HL)          ; pick up high-order byte of routine.
        EX      DE,HL           ; transfer I/O address to HL.

        JP      (HL)            ; jump to routine and then to UNPAGE

; ---

;   By elimination, the address $0008 has been reached as a result of a
;   RST 08 instruction in the Main ROM.  This may be the very first time
;   that this ROM has been paged in after startup or NEW.

;; START-4
L00BC:  RST     30H             ; create new system variables if first time.

        LD      A,$01           ; %00000001
        OUT     ($F7),A         ;

        LD      A,$EE           ; %11101110
        OUT     ($EF),A         ;

        POP     AF              ; temporarily drop the accumulator.
        POP     HL              ; fetch address of error code/hook code to HL.
        PUSH    AF              ; save accumulator again.

;   Note. the address of the code could be anywhere in the 64K address space
;   but it is not in this ROM.  Luckily in the Main ROM at $007B is the
;   sequence ld a,(hl) ; ret which will fetch the unknown error code from
;   the known address.

        RST     10H             ; CALBAS
        DEFW    $007B           ; main TEMP-PTR3

        LD      ($5C3A),A       ; place the error code in sysvar ERR_NR

;   The error code at this stage is one less than actual code.

        CP      $FF             ; is it 'OK'
        JR      NZ,L00E9        ; forward, if not, to TEST-CODE

        BIT     1,(IY+$7C)      ; test FLAGS_3  - first time ?
        JR      Z,L00E7         ; forward, if not, to NREPORT-2
                                ; 'Program finished'

        BIT     7,(IY+$0C)      ; test PPC_hi - a direct command ?
        JR      Z,L00E7         ; forward, if not, to NREPORT-2

        LD      HL,($5C59)      ; use E_LINE to address the first character of 
                                ; the edit buffer.
        LD      A,(HL)          ; searching for RUN without whitespace.

        CP      $F7             ; is character the token 'RUN' ?
        JP      Z,L0A99         ; jump forward, if so, to LOAD-RUN

;; NREPORT-2
L00E7:  RST     20H             ; Shadow Error Restart
        DEFB    $FF             ; 'Program finished'

; ---

;   Continue to consider the error code.  This may have occurred after the
;   Error RESTART in the Main ROM - range $00 (NEXT without FOR) to
;   $1A (Tape Loading Error) or a RESTART in RAM which could also include
;   the Hook Codes.

;; TEST-CODE
L00E9:  SUB     $1B             ; subtract lowest Hook Code (PAUSE)
        JP      NC,L1E71        ; jump, if same or higher, to HOOK-CODE

        CP      $F0             ; was it $0B 'Nonsense in basic'
        JR      Z,L00FB         ; forward to COPYCHADD

        CP      $F3             ; was it $0D 'Invalid file name'
        JR      Z,L00FB         ; forward to COPYCHADD

        CP      $FC             ; was it $17 'Invalid stream'
        JP      NZ,L0028        ; jump, if not, to ROMERR

;   If one of the above three reports, then this is possibly an extended
;   command and further investigation is required. A number of situations
;   may apply. The error could have occurred -
;
;   1) In INPUT - just pass control back to Main ROM. This is just a normal
;      Nonsense in BASIC and will not be due to anything new.
;   2) While already investigating an error. Too much - just use Main ROM.
;   3) While entering a new or modified line and syntax failed.
;   4) While running the program and an error was encountered.
;
;   The character address CH_ADD is not much use as that is the place
;   after the command where the standard ROM encountered an error.
;   It will be required by the Main ROM if control is passed back so, in
;   order that the Main ROM parsing routines can be used, make a copy of the
;   error character position. We will have to work forward from the
;   beginning of the line if checking syntax or from the start of the
;   program in run-time so that the errant command can be found. It may also
;   be necessary to remove hidden characters from the BASIC line.

;; COPYCHADD
L00FB:  LD      HL,($5C5D)      ; fetch character address from CH_ADD and
        LD      ($5CCB),HL      ; store in shadow system variable CHADD_

        POP     AF              ; restore accumulator.

        BIT     5,(IY+$37)      ; test FLAGX - in INPUT mode ?

        JP      NZ,L0028        ; jump back, if so, to ROMERR

;   Continue if in Editing or Run-time Mode.

        BIT     0,(IY+$7C)      ; test FLAGS_3 - already extended command ?
        JP      NZ,L0028        ; jump, if so, to ROMERR

;   else signal - handling an extended command - so that such a double error
;   can be trapped.

        SET     0,(IY+$7C)      ; update FLAGS_3 - signal executing an
                                ; extended command.

        RST     18H             ; checking syntax ?

        JR      NZ,L011B        ; skip forward, if not, to RUNTIME

        LD      (IY+$0C),$FF    ; set bit 7 of PPC_hi to indicate a line
                                ; entry situation.

;    In both cases, load B with the statement number where the error was
;    encountered.  Previous validated statements are not to be disturbed.

;; RUNTIME
L011B:  LD      B,(IY+$0D)      ; load B with statement number from SUBPPC
        LD      C,$00           ; and set C to zero for a quotes flag.

        BIT     7,(IY+$0C)      ; test PPC_hi - line entry ?
        JR      Z,L0130         ; forward, if not, to PROG-LINE

;   An edit line may have a line number at start and whitespace. We need to
;   set CH_ADD at the first command.

        PUSH    BC              ; save BC

        RST     10H             ; CALBAS
        DEFW    $19FB           ; main E-LINE-NO fetches any line number to
                                ; BC, setting CH_ADD at the command token.

        POP     BC              ; restore BC - discarding line number.

        RST     10H             ; CALBAS
        DEFW    $0018           ; main GET-CHAR gets first command of the
                                ; first statement of the errant line.

        JR      L016F           ; forward to statement loop - S-STAT to find
                                ; the errant statement.

; ---

;; PROG-LINE
L0130:  LD      HL,($5C53)      ; set pointer to start of program from PROG.

;; SC-L-LOOP
L0133:  LD      A,($5C46)       ; fetch high byte of errant line from PPC_hi
        CP      (HL)            ; compare with tested high byte.
        JR      NC,L013B        ; forward, if errant line higher or same,
                                ; to TEST-LOW

; else, unusually, the current line is not there so let Main ROM handle.

;; NREPORT-1
L0139:  RST     20H             ; Shadow Error Restart
        DEFB    $00             ; Nonsense in BASIC

; ---

;; TEST-LOW
L013B:  INC     HL              ; increment program pointer to address low byte.
        JR      NZ,L0144        ; forward, if high bytes not same, to LINE-LEN

        LD      A,($5C45)       ; fetch low byte of current line from PPC_lo
        CP      (HL)            ; compare to addressed byte.
        JR      C,L0139         ; back, if not in program area, to NREPORT-1

;; LINE-LEN
L0144:  INC     HL              ; increment program
        LD      E,(HL)          ; pointer and
        INC     HL              ; pick up the
        LD      D,(HL)          ; length of the BASIC line
        INC     HL              ; resting at the first character.

        JR      Z,L016F         ; forward, if line numbers matched, to S-STAT
                                ; the mid-entry point of the statement loop.

        ADD     HL,DE           ; else add length to current address.
        JR      L0133           ; loop back to SC-L-LOOP

; --------------------
; THE 'STATEMENT LOOP'
; --------------------
;    Entered at mid-point S-STAT with statement counter in B and a quotes
;    counter, C, set at an even zero.

;; SKIP-NUM
L014E:  LD      DE,$0006        ; a hidden floating point number has six bytes.
        ADD     HL,DE           ; add to skip to next character.

; -> The Looping Point.

;; EACH-ST
L0152:  LD      A,(HL)          ; fetch addressed BASIC character.
        CP      $0E             ; is it the hidden number indicator ?
        JR      Z,L014E         ; back to SKIP-NUM to ignore.

        INC     HL              ; else increase pointer.

        CP      $22             ; is it quotes character '"' ?
        JR      NZ,L015D        ; skip forward, if not, to CHKEND

        DEC     C               ; decrement quotes counter.

;; CHKEND
L015D:  CP      $3A             ; is character ':' ?
        JR      Z,L0165         ; skip forward to CHKEVEN

        CP      $CB             ; is character 'THEN' ?
        JR      NZ,L0169        ; skip forward to CHKEND-L

;; CHKEVEN
L0165:  BIT     0,C             ; are quotes balanced ?
        JR      Z,L016F         ; forward, if so, to S-STAT
                                ; for next statement.

;   A carriage return must not appear within quotes.

;; CHKEND-L
L0169:  CP      $0D             ; carriage return ?
        JR      NZ,L0152        ; back, if not, to EACH-ST

        JR      L0139           ; back to NREPORT-1
                                ; 'Nonsense in BASIC'

;    The Statement Loop Entry Point -->

;; S-STAT
L016F:  DJNZ    L0152           ; decrement statement counter and loop back
                                ; to EACH-ST.

;    The errant statement has been located and CH_ADD is set to start.

        DEC     HL              ; point to start or ':'

        LD      ($5C5D),HL      ; set the Main ROM system variable CH_ADD

        RST     18H             ; checking syntax ?

        JR      NZ,L01AA        ; forward, if not, to CL-WORK

        BIT     7,(IY+$0C)      ; test PPC_hi - is it an Edit Line ?
        JP      Z,L01F0         ; jump forward, if not, to ERR-6.

        DEC     HL              ; prepare to enter loop below.

        LD      C,$00           ; ??

;   It is well to reflect on what has been achieved up to this point.  At
;   each statement, the first attempt at validation is made by the Main ROM.
;   Then if that should encounter something not to its liking, this ROM has
;   a bash.  There could be ten or more statements before this one and each
;   will have been validated by the Main ROM or by this routine.  As part of
;   that validation process, when a number is parsed, then the integer or
;   floating point form of the number is inserted after the digits, rendered
;   invisible by a CHR$(14).
;
;   Once a statement has passed validation by either ROM, then it is not
;   undone.  If, say, the Main ROM has failed on the third statement of
;
;   10 PRINT "Hi :" : LET vat = 15 : OPEN# 7, "T" : LET tax = cost * (vat/100)
;
;   then it will have already inserted six bytes after the '7' before raising
;   the error 'Invalid stream'.  This ROM has located the separator before
;   the command but needs to remove the hidden numbers before parsing the
;   statement as the latter process will put them back in and we can't
;   double up.  The easiest way to do this is to search for hidden numbers
;   right to the end of the line.  There won't be any after this statement
;   but stopping at a CHR$(13) is easier than considering end of statement
;   markers in quotes.  It seems that this neat solution was not arrived at
;   immediately and the instruction, above, sets C to the quotes flag again
;   and it is needlessly preserved on the stack.
;
;   The end-user is oblivious to this elegant toing and froing between ROMS
;   and the unseen error code generation and cancellation. All that is
;   apparent is that when the RETURN key is pressed, the line simply enters
;   the program.

;; RCLM-NUM
L0182:  INC     HL              ; increment character pointer
        LD      A,(HL)          ; fetch the character.

        CP      $0E             ; is it the number marker ?
        JR      NZ,L01A5        ; forward, if not, to NEXTNUM

        PUSH    BC              ; preserve BC (zero)

        LD      BC,$0006        ; six bytes to reclaim.

        RST     10H             ; CALBAS
        DEFW    $19E8           ; main RECLAIM-2

        PUSH    HL              ; preserve character pointer.

        LD      DE,($5CCB)      ; fetch error pointer from CHADD_
        AND     A               ; prepare for true subtraction.
        SBC     HL,DE           ; test if character position less than error.
        JR      NC,L01A3        ; forward, if not, to NXT-1

        EX      DE,HL           ; transfer CHADD_ value to HL.
        LD      BC,$0006        ; 
        AND     A               ;
        SBC     HL,BC           ; reduce by six.
        LD      ($5CCB),HL      ; store back in system variable CHADD_

;; NXT-1
L01A3:  POP     HL              ; restore character pointer.
        POP     BC              ; and restore BC (zero)

;; NEXTNUM
L01A5:  LD      A,(HL)          ; fetch character.
        CP      $0D             ; carriage return ?
        JR      NZ,L0182        ; loop back, if not, to RCLM-NUM

;  The run-time path rejoins here

;; CL-WORK
L01AA:  RST     10H             ; CALBAS
        DEFW    $16BF           ; main SET-WORK

        CALL    L0255           ; routine RES-VARS sets new system variables
                                ; from that following CHADD_ to that preceding
                                ; COPIES to the value $FF.

        RST     10H             ; CALBAS
        DEFW    $0020           ; main NEXT-CHAR advances CH_ADD and fetches
                                ; the command character.

        SUB     $CE             ; reduce tokens - why?

        CP      $01             ; 'CAT' ?
        JP      Z,L0486         ; jump to CAT-SYN

        CP      $02             ; 'FORMAT' ?
        JP      Z,L04B4         ; jump to FRMT-SYN

        CP      $03             ; 'MOVE' ?
        JP      Z,L053D         ; jump to MOVE-SYN

        CP      $04             ; 'ERASE' ?
        JP      Z,L0531         ; jump to ERASE-SYN

        CP      $05             ; 'OPEN #' ?
        JP      Z,L04ED         ; jump to OPEN-SYN

        CP      $2A             ; 'SAVE' ?
        JP      Z,L082F         ; jump to SAVE-SYN

        CP      $21             ; 'LOAD' ?
        JP      Z,L0898         ; jump to LOAD-SYN

        CP      $08             ; 'VERIFY' ?
        JP      Z,L08A2         ; jump to VERIF-SYN

        CP      $07             ; 'MERGE' ?
        JP      Z,L08AC         ; jump to MRG-SYN

        CP      $2D             ; 'CLS' ?
        JP      Z,L0559         ; jump to CLS#-SYN

        CP      $2F             ; 'CLEAR' ?
        JP      Z,L057F         ; jump to CLR#-SYN

;   If none of the new extended commands then load HL from the VECTOR
;   system variable which normally points to the error routine below.
;   However the user, or a third party software publisher, may have
;   altered the vector to point to their own extended BASIC routines.

;; ERR-V
L01EC:  LD      HL,($5CB7)      ; fetch address from system variable VECTOR
        JP      (HL)            ; jump to address.

; ---

;; ERR-6
L01F0:  LD      HL,($5CCB)      ; fetch original character address from
                                ; CHADD_
        LD      ($5C5D),HL      ; and place in standard CH_ADD
        RST     28H             ; Error Main ROM.

; -----------------------------------------
; THE 'CREATE NEW SYSTEM VARIABLES' ROUTINE
; -----------------------------------------
;   A continuation of the restart code at $0030. A check is made to see if
;   the 58 variables already exist and the stack is set up to create the
;   room using the main ROM routine. If there isn't 58 free bytes available
;   then an 'Out of memory' report is generated by the Main ROM.

;; CRT-VARS
L01F7:  LD      HL,($5C4F)      ; system variable CHANS normally   $5CB6.
        LD      DE,$A349        ; add test value                   $A349.
                                ;                                   ----
        ADD     HL,DE           ; add - if uninitialized will give $FFFF.
        JR      C,L023D         ; forward, if higher, to VAR-EXIST

        LD      HL,L0224        ; prepare address of DEFAULT routine
        PUSH    HL              ; push on machine stack

        LD      HL,($5C63)      ; use system variable STKBOT
        LD      ($5C65),HL      ; to set system variable STKEND

        LD      HL,$5C92        ; use system variable MEMBOT
        LD      ($5C68),HL      ; to set system variable MEM

        LD      HL,$5CB5        ; the last standard system variable.
                                ; P-RAMT_hi - the location before new area.
        LD      BC,L003A        ; 58 bytes to allocate.

;   Now call MAKE-ROOM in the Main ROM by placing a sequence of addresses
;   on the machine stack as it is not possible to use the CALBAS routine yet.

        LD      DE,$0000        ; indicator - signals Main ROM has been used.
        PUSH    DE              ; stack word.

        LD      E,$08           ; form address $0008 in Main ROM.
        PUSH    DE              ; stack word.

        LD      DE,$1655        ; the Main ROM address MAKE-ROOM.
        PUSH    DE              ; stack word.

;   The machine stack now has the hierarchy DEFAULT; $0000; ERROR-1;
;   MAKE-ROOM which will be handled in reverse order.

        JP      L0700           ; jump to UNPAGE.

;   After creating room and paging this ROM back in, 'return' to the next
;   address which was the first in the sequence pushed on machine stack
;   earlier.

;; DEFAULT
L0224:  LD      HL,L0242        ; default system variable values.
        LD      BC,$0013        ; nineteen bytes to move.
        LD      DE,$5CB6        ; old CHANS area, new sysvar FLAGS_3.
        LDIR                    ; copy the bytes.

;   Note. So far the value in the accumulator, which may be the number of a
;   stream to close, has not been altered.  This next instruction is worded 
;   wrongly and 
;
;   OPEN #7,"s" : CLOSE #7 
;
;   may not work.
;   The fix would be to use 'ld hl $5cef ; ld (hl), $01' (5 bytes)
;   or even 'dec h ; ld ($5cee),hl' (4 bytes)
;   The next pair of instructions would have been better if executed using
;   the HL register pair also.

        LD      A,$01           ; set accumulator to 1.
        LD      ($5CEF),A       ; set system variable COPIES.

        LD      (IY+$77),$50    ; set NMI_ADD_hi to eighty.
        LD      (IY+$76),$00    ; set NMI_ADD_lo to zero.

        RET                     ; return.

; ---

;   The extended System Variables already exist.

;; VAR-EXIST
L023D:  RES     1,(IY+$7C)      ; reset indicator in FLAGS_3.
        RET                     ; return.

; -------------------------------------------
; THE 'SYSTEM VARIABLES DEFAULT VALUES' TABLE
; -------------------------------------------
;   These are the initial values of the first section of the extended System
;   Variables that are copied, once only, to a newly opened area following
;   the standard 48K Spectrum System Variables.  The memory area that was at
;   this location (CHANS) is moved upwards to make room.
;   The first new location (which was the first byte of CHANS) is now
;   FLAGS_3, accessible by the IY register, and normally zero when the Main
;   ROM becomes active again.  Bit 1 is set when a CLEAR# is active and also
;   by the copy itself.

;; SV-DEFS
L0242:  DEFB    $02             ; FLAGS3 (with bit 1 already set).
        DEFW    $01F0           ; VECTOR

        LD      HL,$0000        ; SBRT located at $5CB9
        CALL    $0000           ;
        LD      ($5CBA),HL      ;
        RET                     ;

        DEFW    $000C           ; BAUD
        DEFB    $01             ; NTSTAT
        DEFB    $00             ; IOBORD - black.
        DEFW    $0000           ; SER_FL

; ----------------------------------------
; THE 'RESET NEW SYSTEM VARIABLES' ROUTINE
; ----------------------------------------
;   The central area is filled with $FF bytes.
;   This occurs whenever a new extended command is invoked.

;; RES-VARS
L0255:  LD      HL,$5CCD        ; set pointer to NTRESP - start of area.
        LD      B,$22           ; thirty four bytes to fill.

;; EACH-VAR
L025A:  LD      (HL),$FF        ; insert a default $FF value.
        INC     HL              ; bump the pointer.
        DJNZ    L025A           ; loop back to EACH-VAR.

        RET                     ; return.

; ------------------------------------
; THE 'SHADOW REPORT PRINTING' ROUTINE
; ------------------------------------
;   This routine prints the error reports of the Shadow ROM.
;   These relate to the code that follows a RST 20H restart.  The error code
;   is not printed as it would conflict with Main ROM reports.  The text of
;   the message is printed and then the Main ROM routine is used to print a
;   comma and then the line number and statement.  For example,
;   Program finished, 0:1
;   The code is similar to that at MAIN-4 in the Main ROM.  Some improvements
;   have been made but at least one slight error has been replicated.

;; REP-MSG
L0260:  LD      (IY+$7C),$00    ; clear FLAGS_3 in preparation for leaving 
                                ; this ROM.

        EI                      ; Enable Interrupts.

        HALT                    ; wait for the first interrupt.

        CALL    L17B7           ; routine RCL-T-CH reclaims any temporary
                                ; channels and stops any running drive motor.

        RES     5,(IY+$01)      ; update FLAGS - 'Ready for new key'.
        BIT     1,(IY+$30)      ; test FLAGS2 - is printer buffer empty ?
        JR      Z,L0276         ; forward, if so, to FETCH-ERR

        RST     10H             ; CALBAS - call a Base ROM routine.
        DEFW    $0ECD           ; main routine - COPY-BUFF
                                ; Note. the programmer has neglected to
                                ; set bit 1 of FLAGS first.

;; FETCH-ERR
L0276:  POP     HL              ; drop the return address - after RST.
        LD      A,(HL)          ; fetch the error code.
        LD      (IY+$00),A      ; place in system variable ERR_NR.
        INC     A               ; increment setting zero if was $FF.
        PUSH    AF              ; save actual code and status flags.

        LD      HL,$0000        ; prepare to blank some system variables.
        LD      (IY+$37),H      ; clear all the bits of FLAGX.
        LD      (IY+$26),H      ; blank X_PTR_hi to suppress error marker.
        LD      ($5C0B),HL      ; blank DEFADD to signal that no defined
                                ; function is being evaluated.

        INC     L               ; select offset of 1 (explicit in main ROM ).
        LD      ($5C16),HL      ; update STRMS_00 - inputs from keyboard.

        RST     10H             ; CALBAS
        DEFW    $16B0           ; main SET-MIN clears workspace etc.

        RES     5,(IY+$37)      ; update FLAGX - signal in EDIT mode
                                ; not INPUT mode.
                                ; Note. all the bits were reset earlier.

        RST     10H             ; CALBAS
        DEFW    $0D6E           ; main CLS-LOWER

        SET     5,(IY+$02)      ; update TV_FLAG - signal lower screen
                                ; requires clearing.
        RES     3,(IY+$02)      ; update TV_FLAG - no change in mode.

        POP     AF              ; restore the incremented error code.
        LD      HL,L02BF        ; start search at REP-MSGS table below.
        LD      B,$04           ; roughly ensure that BC does not limit
                                ; search area as code must be found.
        CPIR                    ; search for code $00 - $17 skipping
                                ; all ASCII text.

;   At this point HL addresses first character of message.

;; PR-REP-LP
L02A7:  LD      A,(HL)          ; fetch each character in turn.
        CP      $20             ; compare to space.
        JR      C,L02B4         ; forward if less to END-PR-MS

        PUSH    HL              ; save the character pointer
        RST     10H             ; CALBAS
        DEFW    $0010           ; main PRINT-A

        POP     HL              ; restore pointer
        INC     HL              ; and increment.
        JR      L02A7           ; loop back to PR-REP-LP

; ---

;; END-PR-MS
L02B4:  LD      SP,($5C3D)      ; set machine stack pointer from ERR_SP
        INC     SP              ; prepare to overwrite the MAIN-4
        INC     SP              ; address $1303.
        LD      HL,$1349        ; substitute with the part that prints
                                ; the comma and line statement.
        PUSH    HL              ; push address to base of stack.
        RST     00H             ; return to MAIN-ROM.

;   Note. at this stage we have, say, "Program finished" on the screen and
;   the Main ROM routine at $1349 will complete the ", 0:1" part looping
;   back to MAIN-2 to put $1303 on the stack again.

; ------------------------------------
; THE 'SHADOW REPORT MESSAGES' ROUTINE
; ------------------------------------
;   These are the Shadow Error Reports.  Note. that the never used
;   "Header mismatch error" has been largely reclaimed.  Each error code,
;   which must be less than a space, serves to delimit the preceding text.
;   The final delimiter might just as well be $18.

;; REP-MSGS
L02BF   DEFB    $00
        DEFM    "Program finished"
        DEFB    $01
        DEFM    "Nonsense in BASIC"     ; Duplicate of a Main ROM error
        DEFB    $02
        DEFM    "Invalid stream number"
        DEFB    $03
        DEFM    "Invalid device expression"
        DEFB    $04
        DEFM    "Invalid name"
        DEFB    $05
        DEFM    "Invalid drive number"
        DEFB    $06
        DEFM    "Invalid station number"
        DEFB    $07
        DEFM    "Missing name"
        DEFB    $08
        DEFM    "Missing station number"
        DEFB    $09
        DEFM    "Missing drive number"
        DEFB    $0A
        DEFM    "Missing baud rate"
        DEFB    $0B
        DEFM    "er mismatch e"         ; Note. remnants of unused text.
        DEFB    $0C
        DEFM    "Stream already open"
        DEFB    $0D
        DEFM    "Writing to a 'read' file"
        DEFB    $0E
        DEFM    "Reading a 'write' file"
        DEFB    $0F
        DEFM    "Drive 'write' protected"
        DEFB    $10
        DEFM    "Microdrive full"
        DEFB    $11
        DEFM    "Microdrive not present"
        DEFB    $12
        DEFM    "File not found"
        DEFB    $13
        DEFM    "Hook code error"       ; not listed in manual.
        DEFB    $14
        DEFM    "CODE error"
        DEFB    $15
        DEFM    "MERGE error"
        DEFB    $16
        DEFM    "Verification has failed"
        DEFB    $17
        DEFM    "Wrong file type"
        DEFB    $18                     ; end-marker

; *********************************************
; **  T H E   S Y N T A X   R O U T I N E S  **
; *********************************************

; --------------------------------
; THE 'CAT COMMAND SYNTAX' ROUTINE
; --------------------------------
;   e.g. CAT 3
;   Without the syntax tables of the Main ROM, checking syntax is quite
;   laborious.  Although the Main ROM allowed CAT without a parameter, a
;   single expression in the range 1 - 8 is now required.  By default, CAT
;   outputs to the upper screen but output may be directed to any stream in
;   the range 0 to 15 decimal.  The subroutines used to evaluate the numeric
;   expressions use the SCANNING routine, in Main ROM, which inserts the
;   hidden five-byte numbers after any numeric arguments.

;; CAT-SYN
L0486:  LD      HL,$5CD8        ; address system variable S_STR1.
        LD      (HL),$02        ; default to stream 2 the screen.

        RST     10H             ; CALBAS
        DEFW    $0020           ; main NEXT-CHAR

        CP      $0D             ; carriage return ?
        JR      Z,L0494         ; forward, if so, to MISSING-D

        CP      $3A             ; is character ':' ?

;; MISSING-D
L0494:  JP      Z,L0683         ; jump if no parameter to NREPORT-9

        CP      $23             ; is character '#' ?
        JR      NZ,L04A6        ; forward to CAT-SCRN

;   Output is directed at a specific stream.

        CALL    L064E           ; routine EXPT-STRM checks for number in range.
        CALL    L05B1           ; routine SEPARATOR checks for ',' or ';'.
        JR      NZ,L04B2        ; forward, if not present, to OREPORT-1
                                ; 'Nonsense in BASIC'

        RST     10H             ; CALBAS
        DEFW    $0020           ; main NEXT-CHAR

;; CAT-SCRN
L04A6:  CALL    L061E           ; routine EXPT-NUM
        CALL    L05B7           ; routine ST-END
        CALL    L066D           ; routine CHECK-M-2 checks that drive is in 
                                ; range 1 - 8.

        JP      L1AB5           ; jump forward to CAT-RUN

; ---

;; OREPORT-1
L04B2:  RST     20H             ; Shadow Error Restart
        DEFB    $00             ; Nonsense in BASIC

; -----------------------------------
; THE 'FORMAT COMMAND SYNTAX' ROUTINE
; -----------------------------------
;   e.g.

;; FRMT-SYN
L04B4:  CALL    L05F2           ; routine EXPT-SPEC
        CALL    L05B1           ; routine SEPARATOR
        JR      NZ,L04BF        ; forward to NO-FOR-M

        CALL    L062F           ; routine EXPT-NAME

;; NO-FOR-M
L04BF:  CALL    L05B7           ; routine ST-END
        LD      A,($5CD9)       ; sv L_STR1 device letter.
        CP      $54             ; is character  "T" ?
        JR      Z,L04CD         ; forward to FOR-B-T

        CP      $42             ; is character  "B" ?
        JR      NZ,L04D3        ; forward to NOT-FOR-B

;; FOR-B-T
L04CD:  CALL    L06B0           ; routine TEST-BAUD
        JP      L0ACD           ; jump to SET-BAUD

;; NOT-FOR-B
L04D3:  CP      $4E             ; is character "N" ?
        JR      NZ,L04E7        ; forward to FOR-M

        CALL    L068F           ; routine TEST-STAT
        LD      A,($5CD6)       ; sv D_STR1 drive number
        AND     A
        JP      Z,L069F         ; jump to NREPORT-6
        LD      ($5CC5),A       ; sv NTSTAT
        JP      L05C1           ; jump to END1

;; FOR-M
L04E7:  CALL    L0685           ; routine TEST-MNAM
        JP      L1ABA           ; jump to FOR-RUN

; ---------------------------------
; THE 'OPEN COMMAND SYNTAX' ROUTINE
; ---------------------------------
;

;; OPEN-SYN
L04ED:  CALL    L064E           ; routine EXPT-STRM
        CALL    L05B1           ; routine SEPARATOR
        JR      NZ,L04B2        ; back to OREPORT-1
                                ; 'Nonsense in BASIC'

        CALL    L05F2           ; routine EXPT-SPEC
        CALL    L05B1           ; routine SEPARATOR
        JR      NZ,L0500        ; forward to NOT-OP-M

        CALL    L062F           ; routine EXPT-NAME

;; NOT-OP-M
L0500:  CALL    L05B7           ; routine ST-END
        LD      A,($5CD8)       ; sv D_STR1

        RST     10H             ; CALBAS
        DEFW    $1727           ; main STR-DATA1

        LD      HL,$0011        ;
        AND     A               ;
        SBC     HL,BC           ;
        JR      C,L052F         ; forward to NREPORT-C

        LD      A,($5CD9)       ; sv L_STR1 device letter.
        CP      $54             ; "T" ?
        JR      Z,L051C         ; forward to OPEN-RS

        CP      $42             ; "B" ?
        JR      NZ,L051F        ; forward to NOT-OP-B

;; OPEN-RS
L051C:  JP      L0B4E           ; jump to OP-RSCHAN

; ---

;; NOT-OP-B
L051F:  CP      $4E             ; is character "N" ?
        JR      NZ,L0529        ; forward to OP-M-C

        CALL    L068F           ; routine TEST-STAT
        JP      L0F40           ; jump to OPEN-N-ST

; ---

;; OP-M-C
L0529:  CALL    L0685           ; routine TEST-MNAM
        JP      L1ABF           ; jump to OP-RUN

; ---

;; NREPORT-C
L052F:  RST     20H             ; Shadow Error Restart
        DEFB    $0B             ; Stream already open

; ----------------------------------
; THE 'ERASE COMMAND SYNTAX' ROUTINE
; ----------------------------------
;

;; ERASE-SYN
L0531:  CALL    L06A3           ; routine EXPT-EXPR
        CALL    L05B7           ; routine ST-END
        CALL    L0685           ; routine TEST-MNAM
        JP      L1AAB           ; jump to ERASE-RUN

; ---------------------------------
; THE 'MOVE COMMAND SYNTAX' ROUTINE
; ---------------------------------
;

;; MOVE-SYN
L053D:  CALL    L06B9           ; routine EXPT-EXP1
        CALL    L059F           ; routine EX-D-STR
        RST     10H             ; CALBAS
        DEFW    $0018           ; main GET-CHAR

        CP      $CC             ; 'TO' ?
        JR      NZ,L0584        ; forward to NONSENSE

        CALL    L06B9           ; routine EXPT-EXP1
        CALL    L059F           ; routine EX-D-STR
        RST     10H             ; CALBAS
        DEFW    $0018           ; main GET-CHAR

        CALL    L05B7           ; routine ST-END
        JP      L1AB0           ; jump to MOVE-RUN

; --------------------------
; THE 'CLS# COMMAND' ROUTINE
; --------------------------
;

;; CLS#-SYN
L0559:  RST     10H             ; CALBAS
        DEFW    $0020           ; main NEXT-CHAR

        CP      $23             ; is the character '#' ?
        JR      NZ,L0584        ; forward, if not, to NONSENSE

        RST     10H             ; CALBAS
        DEFW    $0020           ; main NEXT-CHAR

        CALL    L05B7           ; routine ST-END

        LD      HL,L0038        ; prepare a zero and black ink on white paper.
        LD      ($5C8D),HL      ; set system variables ATTR_P and MASK_P.
        LD      ($5C8F),HL      ; set system variables ATTR_T and MASK_T.
                                ; Note. not really necessary as done by CLS.
        LD      (IY+$0E),L      ; set system variable BORDCR to colour scheme.
        LD      (IY+$57),H      ; set system variable P_FLAG to zero.

        LD      A,$07           ; load A with white.
        OUT     ($FE),A         ; directly change border colour.

        RST     10H             ; CALBAS
        DEFW    $0D6B           ; main CLS clears screen and sets colours.

        JP      L05C1           ; jump forward to END1.

; ----------------------------
; THE 'CLEAR# COMMAND' ROUTINE
; ----------------------------
;

;; CLR#-SYN
L057F:  RST     10H             ; CALBAS
        DEFW    $0020           ; main NEXT-CHAR

        CP      $23             ; '#' ?

;; NONSENSE
L0584:  JP      NZ,L04B2        ; jump to OREPORT-1
                                ; 'Nonsense in BASIC'

        RST     10H             ; CALBAS
        DEFW    $0020           ; main NEXT-CHAR

        CALL    L05B7           ; routine ST-END

        XOR     A               ;

;; ALL-STRMS
L058E:  PUSH    AF              ;
        SET     1,(IY+$7C)      ; sv FLAGS_3
        CALL    L1718           ; routine CLOSE
        POP     AF              ;
        INC     A               ;
        CP      $10             ;
        JR      C,L058E         ; back to ALL-STRMS

        JP      L05C1           ; jump to END1

; -----------------------------------------------------
; THE 'EXCHANGE FILE SPECIFIERS DSTRI AND STR2' ROUTINE
; -----------------------------------------------------
;   This routine is used by the MOVE routines to bring one of the two 8-byte
;   file specifiers into context.  There were two similar routines in the
;   first Interface 1 ROM and this, the most efficient, has survived.

;; EX-D-STR
L059F:  LD      HL,$5CD6        ; sv D_STR1. drive number
        LD      DE,$5CDE        ; sv D_STR2.
        LD      B,$08           ; eight bytes to swap.

;; ALL-BYTES
L05A7:  LD      A,(DE)          ; fetch byte 1.
        LD      C,(HL)          ; fetch byte 2.
        LD      (HL),A          ; place byte 1.
        LD      A,C             ; byte 2 to accumulator.
        LD      (DE),A          ; place byte 2.

        INC     HL              ; increment the
        INC     DE              ; two pointers.
        DJNZ    L05A7           ; loop back, for all eight, to ALL-BYTES.

        RET                     ; return.

; -----------------------
; THE 'SEPARATOR' ROUTINE
; -----------------------
;   This routine returns with zero flag set if the current character is
;   either a comma or semi-colon.

;; SEPARATOR
L05B1:  CP      $2C             ; is character ',' ?
        RET     Z               ; return with zero set if so.

        CP      $3B             ; is character ';' ?
        RET                     ; return.

; ------------------------------
; THE 'END OF STATEMENT' ROUTINE
; ------------------------------
;

;; ST-END
L05B7:  CP      $0D             ; is character carriage return ?
        JR      Z,L05BF         ; forward, if so, to TEST-RET

        CP      $3A             ; is character a ':' ?
        JR      NZ,L0584        ; back, if not, to NONSENSE

;; TEST-RET
L05BF:  RST     18H             ; checking syntax ?
        RET     NZ              ; return if not.

; --------------------------------------------
; THE 'RETURN TO THE MAIN INTERPRETER' ROUTINE
; --------------------------------------------
;

;; END1
L05C1:  LD      SP,($5C3D)      ; sv ERR_SP
        LD      (IY+$00),$FF    ; sv ERR_NR

        LD      HL,$1BF4        ; Main ROM address STMT-NEXT

        RST     18H             ; checking syntax ?
        JR      Z,L05E0         ; forward, if so, to RETAD-SYN

        LD      A,$7F           ;
        IN      A,($FE)         ;
        RRA                     ;
        JR      C,L05DD         ; forward to RETAD-RUN

        LD      A,$FE           ;
        IN      A,($FE)         ;
        RRA                     ;
        JR      NC,L05E2        ; forward to BREAK-PGM

;; RETAD-RUN
L05DD:  LD      HL,$1B7D        ; Main ROM address STMT-R-1

;; RETAD-SYN
L05E0:  PUSH    HL              ;
        RST     00H             ; to MAIN-ROM

; ---

;; BREAK-PGM
L05E2:  LD      (IY+$00),$14    ; insert error code in system variable ERR_NR.
        RST     28H             ; Error Main ROM 
                                ; 'BREAK into program'

; ----------------------------------------
; THE 'EVALUATE STRING EXPRESSION' ROUTINE
; ----------------------------------------
;

;; EXPT-STR
L05E7:  RST     10H             ; CALBAS
        DEFW    $1C8C           ; main EXPT-EXP
        RST     18H             ; checking syntax ?
        RET     Z

        PUSH    AF
        RST     10H             ; CALBAS
        DEFW    $2BF1           ; main STK-FETCH
        POP     AF
        RET

; -----------------------------------------
; THE 'EVALUATE CHANNEL EXPRESSION' ROUTINE
; -----------------------------------------
;

;; EXPT-SPEC
L05F2:  RST     10H             ; CALBAS
        DEFW    $0020           ; main NEXT-CHAR

;; EXP-SPEC2
L05F5   CALL    L05E7           ; routine EXPT-STR evaluates a string e.g. "m"
                                ; start in DE, length in BC.

; one of the main tenets of Sinclair BASIC is that a value can be replaced 
; by an expression of the same type at any time, so this routine must allow
; something like "tomato"(3) as well as the more conventional "m" specifier.
; Only in runtime when the expression is evaluated can a single character be
; insisted upon.

        JR      Z,L060C         ; forward, if checking syntax, to TEST-NEXT.

        PUSH    AF              ; save following character.

        LD      A,C             ; in runtime check 
        DEC     A               ; immediately for 
        OR      B               ; a single character.

        JR      NZ,L062D        ; forward, if not, to NREPORT-3
                                ; 'Invalid device expression'

        LD      A,(DE)          ; fetch the addressed character.

        RST     10H             ; CALBAS
        DEFW    $2C8D           ; main ALPHA

        JR      NC,L062D        ; forward, if not alphabetic, to NREPORT-3

        AND     $DF             ; convert to uppercase with 'AND %11011111'

        LD      ($5CD9),A       ; place in system variable L_STR1 device letter.

        POP     AF              ; restore the following character.

;; TEST-NEXT
L060C:  CP      $0D             ; test for carriage return.
        RET     Z               ; return if so.

        CP      $3A             ; is character ':' ?
        RET     Z               ; return if so.

        CP      $A5             ; RND
        RET     NC              ; return with a token??

        CALL    L05B1           ; routine SEPARATOR tests for both ';' and ','.

        JP      NZ,L04B2        ; jump back, if not, to OREPORT-1
                                ; 'Nonsense in BASIC'

        RST     10H             ; CALBAS
        DEFW    $0020           ; main NEXT-CHAR

; -----------------------------------------------
; THE 'EVALUATE NUMERIC DRIVE EXPRESSION' ROUTINE
; -----------------------------------------------
;   This routine is called once only to evaluate the numeric expression
;   following a 'CAT' command token or is used from above to check a numeric 
;   expression following for example "M"; .

;; EXPT-NUM
L061E:  RST     10H             ; CALBAS
        DEFW    $1C82           ; main EXPT-1NUM
        RST     18H             ; checking syntax ?
        RET     Z               ; return if checking syntax.

        PUSH    AF              ; save NZ not syntax flag

        RST     10H             ; CALBAS
        DEFW    $1E99           ; main FIND-INT2

        LD      ($5CD6),BC      ; set system variable D_STR1 drive number

        POP     AF              ; restore NZ not syntax flag

        RET                     ; return.

; ---

;; NREPORT-3
L062D:  RST     20H             ; Shadow Error Restart
        DEFB    $02             ; 'Invalid device expression'

; -------------------------------
; THE 'EVALUATE FILENAME' ROUTINE
; -------------------------------
;

;; EXPT-NAME
L062F:  RST     10H             ; CALBAS
        DEFW    $0020           ; main NEXT-CHAR

        CALL    L05E7           ; routine EXPT-STR
        RET     Z

        PUSH    AF
        LD      A,C
        OR      B
        JR      Z,L064C         ; forward to NREPORT-4

        LD      HL,$000A
        SBC     HL,BC
        JR      C,L064C         ; forward to NREPORT-4

        LD      ($5CDA),BC      ; sv N_STR1
        LD      ($5CDC),DE      ; sv D_STR1
        POP     AF
        RET

; ---

;; NREPORT-4
L064C:  RST     20H             ; Shadow Error Restart
        DEFB    $03             ; Invalid name

; ------------------------------------
; THE 'EVALUATE STREAM NUMBER' ROUTINE
; ------------------------------------
;

;; EXPT-STRM
L064E:  RST     10H             ; CALBAS
        DEFW    $0020           ; main NEXT-CHAR

        RST     10H             ; CALBAS
        DEFW    $1C82           ; main EXPT-1NUM
        RST     18H             ; checking syntax ?
        RET     Z               ;

        PUSH    AF              ;
        RST     10H             ; CALBAS
        DEFW    $1E94           ; main FIND-INT1
        CP      $10             ;
        JR      NC,L0663        ; forward to NREPORT-2

        LD      ($5CD8),A       ; sv D_STR1
        POP     AF              ;
        RET                     ;

; ---

;; NREPORT-2
L0663:  RST     20H             ; Shadow Error Restart
        DEFB    $01             ; Invalid stream number

; ----------------------------------
; THE 'CHECK "M" PARAMETERS' ROUTINE
; ----------------------------------
; called once from TEST-MNAM

;; CHECK-M
L0665:  LD      A,($5CD9)       ; fetch system variable L_STR1 device letter.
        CP      $4D             ; is character "M" ?
        JP      NZ,L062D        ; jump back, if not, to NREPORT-3
                                ; Error: 'Invalid device expression'.

;; CHECK-M-2
L066D:  LD      DE,($5CD6)      ; fetch system variable D_STR1 drive number.
        LD      A,E             ; test for
        OR      D               ; zero.
        JR      Z,L0681         ; forward, if so, to NREPORT-5
                                ; 'Invalid drive number'

        INC     DE              ; also test that
        LD      A,E             ; location does not hold
        OR      D               ; the default $FFFF value.
        JR      Z,L0683         ; forward, if so, to NREPORT-9
                                ; 'Missing drive number'.

        DEC     DE              ; restore to initial value.
        LD      HL,L0008        ; and test that
        SBC     HL,DE           ; drive is in range 1 - 8.
        RET     NC              ; return if so.

;; NREPORT-5
L0681:  RST     20H             ; Shadow Error Restart
        DEFB    $04             ; Invalid drive number
; ---

;; NREPORT-9
L0683:  RST     20H             ; Shadow Error Restart
        DEFB    $08             ; Missing drive number

; -----------------------------------------------
; THE 'CHECK "M" PARAMETERS AND FILENAME' ROUTINE
; -----------------------------------------------
; This routine checks that the device expression is "M", that the drive is in
; the range 1 - 8 and that the filename is not null.

;; TEST-MNAM
L0685:  CALL    L0665           ; routine CHECK-M checks for "M" and valid 
                                ; drive number.

        LD      A,($5CDB)       ; load A with D_STR1 the high byte of length
                                ; of filename.
        AND     A               ; test for zero.
        RET     Z               ; return if so.

; else system default $FF.

        RST     20H             ; Shadow Error Restart
        DEFB    $06             ; Missing name

; ----------------------------------
; THE 'CHECK STATION NUMBER' ROUTINE
; ----------------------------------
;

;; TEST-STAT
L068F:  LD      DE,($5CD6)      ; sv D_STR1 drive number
        INC     DE
        LD      A,E
        OR      D
        JR      Z,L06A1         ; forward to NREPORT-8

        DEC     DE
        LD      HL,L0040
        SBC     HL,DE
        RET     NC

;; NREPORT-6
L069F:  RST     20H             ; Shadow Error Restart
        DEFB    $05             ; Invalid station number

;; NREPORT-8
L06A1:  RST     20H             ; Shadow Error Restart
        DEFB    $07             ; Missing station number

; -----------------------------------
; THE 'EVALUATE "X";N;"NAME"' ROUTINE
; -----------------------------------
;

;; EXPT-EXPR
L06A3:  CALL    L05F2           ; routine EXPT-SPEC
        CALL    L05B1           ; routine SEPARATOR
        JP      NZ,L04B2        ; jump to OREPORT-1
                                ; 'Nonsense in BASIC'

        CALL    L062F           ; routine EXPT-NAME
        RET                     ; return...

; -----------------------------
; THE 'CHECK BAUD RATE' ROUTINE
; -----------------------------
;

;; TEST-BAUD
L06B0:  LD      HL,($5CD6)      ; sv D_STR1 drive number
        INC     HL
        LD      A,L
        OR      H
        RET     NZ

        RST     20H             ; Shadow Error Restart
        DEFB    $09             ; Missing baud rate

; -------------------------------------------
; THE 'EVALUATE STREAM OR EXPRESSION' ROUTINE
; -------------------------------------------
;

;; EXPT-EXP1
L06B9:  RST     10H             ; CALBAS
        DEFW    $0020           ; main NEXT-CHAR

        CP      $23             ; is character '#' ?
        JP      Z,L064E         ; jump to EXPT-STRM

        CALL    L05F5           ; routine EXP-SPEC2
        CALL    L05B1           ; routine SEPARATOR
        JR      NZ,L06CC        ; forward to ENDHERE

        CALL    L062F           ; routine EXPT-NAME

;; ENDHERE
L06CC:  RST     18H             ; checking syntax ?
        RET     Z

        LD      A,($5CD9)       ; sv L_STR1 device letter.
        CP      $54             ; is character "T" ?
        RET     Z               ;

        CP      $42             ; is character "B" ?
        RET     Z               ;

        CP      $4E             ; is character "N" ?
        JP      Z,L068F         ; jump, if so, to TEST-STAT

        JP      L0685           ; jump to TEST-MNAM

; ---

        DEFB    $FF
        DEFB    $FF
        DEFB    $FF
        DEFB    $FF
        DEFB    $FF
        DEFB    $FF
        DEFB    $FF
        DEFB    $FF
        DEFB    $FF
        DEFB    $FF
        DEFB    $FF
        DEFB    $FF
        DEFB    $FF
        DEFB    $FF
        DEFB    $FF
        DEFB    $FF
        DEFB    $FF
        DEFB    $FF
        DEFB    $FF
        DEFB    $FF
        DEFB    $FF
        DEFB    $FF
        DEFB    $FF
        DEFB    $FF
        DEFB    $FF
        DEFB    $FF
        DEFB    $FF
        DEFB    $FF
        DEFB    $FF
        DEFB    $FF
        DEFB    $FF
        DEFB    $FF
        DEFB    $FF

; --------------------
; THE 'UNPAGE' ROUTINE
; --------------------
;

;; UNPAGE
L0700:  RET

; ---------------------------------
; THE 'EVALUATE PARAMETERS' ROUTINE
; ---------------------------------
;

;; EXPT-PRMS
L0701:  RST     10H             ; CALBAS
        DEFW    $0020           ; main NEXT-CHAR

        CP      $2A             ; is character '*'
        JR      NZ,L073C        ; forward, if not, to OREP-1-2

        RST     10H             ; CALBAS
        DEFW    $0020           ; main NEXT-CHAR

        CALL    L05F5           ; routine EXP-SPEC2
        CALL    L05B1           ; routine SEPARATOR
        JR      NZ,L0716        ; forward to NO-NAME

        CALL    L062F           ; routine EXPT-NAME

;; NO-NAME
L0716:  PUSH    AF
        LD      A,($5CD9)       ; sv L_STR1 device letter.

        CP      $4E             ; is character "N" ?
        JR      NZ,L0722        ; forward, if not, to NOT-NET

        SET     3,(IY+$7C)      ; update FLAGS_3 signal networking.

;; NOT-NET
L0722:  POP     AF
        CP      $0D             ; is character carriage return ?
        JR      Z,L0750         ; forward to END-EXPT

        CP      $3A             ; is character ':' ?
        JR      Z,L0750         ; forward to END-EXPT

        CP      $AA             ; is character the token 'SCREEN$' ?
        JR      Z,L0771         ; forward to SCREEN$

        CP      $AF             ; is character the token 'CODE' ?
        JR      Z,L0789         ; forward to CODE

        CP      $CA             ; is character the token 'LINE' ?
        JR      Z,L073E         ; forward to LINE

        CP      $E4             ; is character the token 'DATA' ?
        JP      Z,L07D2         ; jump to DATA

;; OREP-1-2
L073C:  RST     20H             ; Shadow Error Restart
        DEFB    $00             ; Nonsense in BASIC

; ---

;; LINE
L073E:  RST     10H             ; CALBAS
        DEFW    $0020           ; main NEXT-CHAR

        RST     10H             ; CALBAS
        DEFW    $1C82           ; main EXPT-1NUM

        CALL    L05B7           ; routine ST-END

        RST     10H             ; CALBAS
        DEFW    $1E99           ; main FIND-INT2

        LD      ($5CED),BC      ; sv HD_11
        JR      L0753           ; forward to PROG

; ---

;; END-EXPT
L0750:  CALL    L05B7           ; routine ST-END

; the 'PROGRAM' SUBROUTINE is used when loading 'run'.

;; PROG
L0753:  XOR     A               ;
        LD      ($5CE6),A       ; sv HD_00
        LD      HL,($5C59)      ; sv E_LINE
        LD      DE,($5C53)      ; sv PROG
        LD      ($5CE9),DE      ; sv HD_0D
        SCF                     ;
        SBC     HL,DE           ;
        LD      ($5CE7),HL      ; sv HD_0B
        LD      HL,($5C4B)      ; sv VARS
        SBC     HL,DE           ;
        LD      ($5CEB),HL      ; sv HD_0F
        RET

; ---

;; SCREEN$
L0771:  RST     10H             ; CALBAS
        DEFW    $0020           ; main NEXT-CHAR

        CALL    L05B7           ; routine ST-END
        LD      HL,$1B00
        LD      ($5CE7),HL      ; sv HD_0B
        LD      HL,$4000
        LD      ($5CE9),HL      ; sv HD_0D
        LD      A,$03
        LD      ($5CE6),A       ; sv HD_00
        RET

; ---

;; CODE
L0789:  RST     10H             ; CALBAS
        DEFW    $0020           ; main NEXT-CHAR

        CP      $0D             ; is character a carriage return ?
        JR      Z,L079A         ; forward to DEFLT-0

        CP      $3A             ; is character a ':' ?
        JR      NZ,L079F        ; forward to PAR-1

        BIT     5,(IY+$7C)      ; sv FLAGS_3
        JR      NZ,L073C        ; back to OREP-1-2

;; DEFLT-0
L079A:  RST     10H             ; CALBAS
        DEFW    $1CE6           ; main USE-ZERO
        JR      L07A7           ; forward to TEST-SAVE

; ---

;; PAR-1
L079F:  RST     10H             ; CALBAS
        DEFW    $1C82           ; main EXPT-1NUM
        CALL    L05B1           ; routine SEPARATOR
        JR      Z,L07B2         ; forward to PAR-2

;; TEST-SAVE
L07A7:  BIT     5,(IY+$7C)      ; sv FLAGS_3
        JR      NZ,L073C        ; back to OREP-1-2

        RST     10H             ; CALBAS
        DEFW    $1CE6           ; main USE-ZERO
        JR      L07B8           ; forward to END-CODE

; ---

;; PAR-2
L07B2:  RST     10H             ; CALBAS
        DEFW    $0020           ; main NEXT-CHAR

        RST     10H             ; CALBAS
        DEFW    $1C82           ; main EXPT-1NUM

;; END-CODE
L07B8:  RST     10H             ; CALBAS
        DEFW    $0018           ; main GET-CHAR

        CALL    L05B7           ; routine ST-END

        RST     10H             ; CALBAS
        DEFW    $1E99           ; main FIND-INT2
        LD      ($5CE7),BC      ; sv HD_0B

        RST     10H             ; CALBAS
        DEFW    $1E99           ; main FIND-INT2
        LD      ($5CE9),BC      ; sv HD_0D

        LD      A,$03
        LD      ($5CE6),A       ; sv HD_00
        RET                     ; return.

; ---
;
; ---

;; DATA
L07D2:  BIT     6,(IY+$7C)      ; sv FLAGS_3
        JR      Z,L07DA         ; forward to NO-M-ARR

        RST     20H             ; Shadow Error Restart
        DEFB    $14             ; MERGE error

;; NO-M-ARR
L07DA:  RST     10H             ; CALBAS
        DEFW    $0020           ; main NEXT-CHAR

        RST     10H             ; CALBAS
        DEFW    $28B2           ; main LOOK-VARS

        SET     7,C
        JR      NC,L07F2        ; forward to EXISTING

        LD      HL,$0000
        BIT     4,(IY+$7C)      ; sv FLAGS_3
        JR      NZ,L080E        ; forward to LD-DATA

        LD      (IY+$00),$01    ; sv ERR_NR to '2 Variable not found'
        RST     28H             ; Error Main ROM

; ---

;; EXISTING
L07F2:  JR      Z,L07F6         ; forward to G-TYPE

;; NONS-BSC
L07F4:  RST     20H             ; Shadow Error Restart
        DEFB    $00             ; Nonsense in BASIC

; ---

;; G-TYPE
L07F6:  RST     18H             ; checking syntax ?
        JR      Z,L081C         ; forward to END-DATA

        BIT     5,(IY+$7C)      ; sv FLAGS_3
        JR      Z,L0803         ; forward to VR-DATA

        BIT     7,(HL)
        JR      Z,L07F4         ; back to NONS-BSC

;; VR-DATA
L0803:  INC     HL
        LD      A,(HL)
        LD      ($5CE7),A       ; sv HD_0B
        INC     HL
        LD      A,(HL)
        LD      ($5CE8),A       ; sv HD_0B_hi
        INC     HL

;; LD-DATA
L080E:  LD      A,C
        LD      ($5CEB),A       ; sv HD_0F
        LD      A,$01
        BIT     6,C
        JR      Z,L0819         ; forward to NUM-ARR

        INC     A

;; NUM-ARR
L0819:  LD      ($5CE6),A       ; sv HD_00

;; END-DATA
L081C:  EX      DE,HL
        RST     10H             ; CALBAS
        DEFW    $0020           ; main NEXT-CHAR

        CP      $29             ; is character ')' ?
        JR      NZ,L07F4        ; back to NONS-BSC

        RST     10H             ; CALBAS
        DEFW    $0020           ; main NEXT-CHAR

        CALL    L05B7           ; routine ST-END
        LD      ($5CE9),DE      ; sv HD_0D
        RET                     ; return.

; ---------------------------------
; THE 'SAVE COMMAND SYNTAX' ROUTINE
; ---------------------------------
;

;; SAVE-SYN
L082F:  SET     5,(IY+$7C)      ; sv FLAGS_3
        CALL    L0701           ; routine EXPT-PRMS

        LD      A,($5CD9)       ; sv L_STR1 device letter.

        CP      $42             ; is character 'B' ?
        JR      Z,L084F         ; forward to SA-HEADER

        CP      $4E             ; is character 'N' ?
        JR      NZ,L0849        ; forward to SAVE-M

        CALL    L068F           ; routine TEST-STAT
        CALL    L0F46           ; routine OP-TEMP-N
        JR      L084F           ; forward to SA-HEADER

; ---

;; SAVE-M
L0849:  CALL    L0685           ; routine TEST-MNAM
        JP      L1AC4           ; jump to SAVE-RUN

; ---

;; SA-HEADER
L084F:  LD      B,$09
        LD      HL,$5CE6        ; sv HD_00

;; HD-LOOP
L0854:  CALL    L0884           ; routine SA-BYTE
        INC     HL
        DJNZ    L0854           ; back to HD-LOOP

        LD      HL,($5CE9)      ; sv HD_0D
        BIT     3,(IY+$7C)      ; sv FLAGS_3
        JR      Z,L086E         ; forward to SA-BLOCK

        LD      A,($5CE6)       ; sv HD_00
        CP      $03             ; compare with three - type CODE
        JR      NC,L086E        ; forward to SA-BLOCK

        LD      DE,$0114        ;
        ADD     HL,DE           ;

;; SA-BLOCK
L086E:  LD      BC,($5CE7)      ; sv HD_0B

;; SA-BLK-LP
L0872:  LD      A,C             ;
        OR      B               ;
        JR      Z,L0881         ; forward to S-BLK-END

        PUSH    IX              ;;;

        CALL    L0884           ; routine SA-BYTE

        POP     IX              ;;;

        DEC     BC              ;
        INC     HL              ;
        JR      L0872           ; back to SA-BLK-LP

; ---

;; S-BLK-END
L0881:  JP      L098C           ; jump to TST-MR-M

; --------------------------------------------------
; THE 'SAVE A BYTE TO NETWORK OR RS232 LINK' ROUTINE
; --------------------------------------------------
;

;; SA-BYTE
L0884:  PUSH    HL              ;
        PUSH    BC              ;
        BIT     3,(IY+$7C)      ; sv FLAGS_3
        LD      A,(HL)          ;
        JR      NZ,L0892        ; forward to SA-NET

        CALL    L0D07           ; routine BCHAN-OUT
        JR      L0895           ; forward to SA-B-END

; ---

;; SA-NET
L0892:  CALL    L0E09           ; routine NCHAN-OUT

;; SA-B-END
L0895:  POP     BC              ;
        POP     HL              ;
        RET                     ;

; ---------------------------------
; THE 'LOAD COMMAND SYNTAX' ROUTINE
; ---------------------------------
;

;; LOAD-SYN
L0898:  SET     4,(IY+$7C)      ; sv FLAGS_3
        CALL    L0701           ; routine EXPT-PRMS
        JP      L08B3           ; jump to LD-VF-MR

; -----------------------------------
; THE 'VERIFY COMMAND SYNTAX' ROUTINE
; -----------------------------------
;

;; VERIF-SYN
L08A2:  SET     7,(IY+$7C)      ; sv FLAGS_3
        CALL    L0701           ; routine EXPT-PRMS
        JP      L08B3           ; jump to LD-VF-MR

; ----------------------------------
; THE 'MERGE COMMAND SYNTAX' ROUTINE
; ----------------------------------
;

;; MRG-SYN
L08AC:  SET     6,(IY+$7C)      ; sv FLAGS_3
        CALL    L0701           ; routine EXPT-PRMS

; ----------------------------------------
; THE 'LOAD-VERIFY-MERGE COMMANDS' ROUTINE
; ----------------------------------------
;

;; LD-VF-MR
L08B3:  LD      HL,$5CE6        ; set source to HD_00
        LD      DE,$5CDE        ; set destination to D_STR2
        LD      BC,$0007        ; seven bytes to copy.
        LDIR                    ; copy type, start, length, length of program.

        LD      A,($5CD9)       ; sv L_STR1 device letter.

        CP      $4E             ; "N" ?

        JR      Z,L08D1         ; forward to TS-L-NET

        CP      $42             ; "B" ?

        JR      Z,L08D7         ; forward to TS-L-RS

; proceed with Microdrive device.

        CALL    L0685           ; routine TEST-MNAM return without error if
                                ; device is "M" and drive and filename are OK.

        CALL    L1971           ; routine F-M-HEAD loads the header type
                                ; record for the above filename and populates
                                ; the locations HD_00 to HD_11.

        JR      L08F6           ; forward to TEST-TYPE which tests that file
                                ; types agree and then loads rest of records.

; ---

;; TS-L-NET
L08D1:  CALL    L068F           ; routine TEST-STAT
        CALL    L0F46           ; routine OP-TEMP-N

;; TS-L-RS
L08D7:  LD      HL,$5CE6        ; sv HD_00
        LD      B,$09           ;

;; LD-HEADER
L08DC:  PUSH    HL
        PUSH    BC
        BIT     3,(IY+$7C)      ; sv FLAGS_3
        JR      Z,L08EB         ; forward to LD-HD-RS

;; LD-HD-NET
L08E4:  CALL    L0DAF           ; routine NCHAN-IN
        JR      NC,L08E4        ; back to LD-HD-NET

        JR      L08F0           ; forward to LD-HDR-2

; ---

;; LD-HD-RS
L08EB:  CALL    L0B88           ; routine BCHAN-IN
        JR      NC,L08EB        ; back to LD-HD-RS

;; LD-HDR-2
L08F0:  POP     BC
        POP     HL
        LD      (HL),A
        INC     HL
        DJNZ    L08DC           ; back to LD-HEADER

; -->

;; TEST-TYPE
L08F6:  LD      A,($5CDE)       ; sv D_STR2
        LD      B,A
        LD      A,($5CE6)       ; sv HD_00
        CP      B
        JR      NZ,L0906        ; forward to NREPORT-N

        CP      $03             ; compare with three - type CODE
        JR      Z,L0915         ; forward to T-M-CODE

        JR      C,L0908         ; forward to TST-MERGE

;; NREPORT-N
L0906:  RST     20H             ; Shadow Error Restart
        DEFB    $16             ; Wrong file type

; ---

;; TST-MERGE
L0908:  BIT     6,(IY+$7C)      ; sv FLAGS_3
        JR      NZ,L096B        ; forward to MERGE-BLK

        BIT     7,(IY+$7C)      ; sv FLAGS_3
        JP      Z,L09A7         ; jump to LD-PR-AR

;; T-M-CODE
L0915:  BIT     6,(IY+$7C)      ; sv FLAGS_3
        JR      Z,L091D         ; forward to LD-BLOCK

        RST     20H             ; Shadow Error Restart
        DEFB    $14             ; MERGE error

; ---

;; LD-BLOCK
L091D:  LD      HL,($5CDF)      ; sv D_STR2 (+1) length of data
        LD      DE,($5CE7)      ; sv HD_0B
        LD      A,H             ;
        OR      L               ;
        JR      Z,L0936         ; forward to LD-BLK-2

        SBC     HL,DE           ;
        JR      NC,L0936        ; forward to LD-BLK-2

        BIT     4,(IY+$7C)      ; sv FLAGS_3
        JR      Z,L0934         ; forward to NREPORT-L

        RST     20H             ; Shadow Error Restart
        DEFB    $13             ; Code Error

; ---

;; NREPORT-L
L0934:  RST     20H             ; Shadow Error Restart
        DEFB    $15             ; Verification has failed

; ---

;; LD-BLK-2
L0936:  LD      HL,($5CE1)      ; sv L_STR2
        LD      A,(IX+$04)      ; channel letter
        CP      $CD             ; 'M' +$80 ?
        JR      NZ,L0945        ; forward to LD-BLK-3

        LD      HL,($5CE4)      ; sv D_STR2             ********
        JR      L0956           ; forward to LD-BLK-4

; ---

;; LD-BLK-3
L0945:  BIT     3,(IY+$7C)      ; sv FLAGS_3
        JR      Z,L0956         ; forward to LD-BLK-4

        LD      A,($5CE6)       ; sv HD_00
        CP      $03             ; compare with three - type CODE
        JR      Z,L0956         ; forward to LD-BLK-4

        LD      BC,$0114        ;
        ADD     HL,BC           ;

;; LD-BLK-4
L0956:  LD      A,H             ;
        OR      L               ;
        JR      NZ,L095D        ; forward to LD-BLK-5

        LD      HL,($5CE9)      ; sv HD_0D

;; LD-BLK-5
L095D:  LD      A,($5CE6)       ; sv HD_00
        AND     A               ;
        JR      NZ,L0966        ; forward to LD-NO-PGM

        LD      HL,($5C53)      ; sv PROG

;; LD-NO-PGM
L0966:  CALL    L0A60           ; routine LV-ANY
        JR      L098C           ; forward to TST-MR-M

; ---

;; MERGE-BLK
L096B:  LD      A,($5CEE)       ; sv HD_11_hi
        AND     $C0             ;
        JR      NZ,L0977        ; forward to NO-AUTOST

        CALL    L17B7           ; routine RCL-T-CH

        RST     20H             ; Shadow Error Restart
        DEFB    $14             ; MERGE error

; ---

;; NO-AUTOST
L0977:  LD      BC,($5CE7)      ; sv HD_0B
        PUSH    BC              ;
        INC     BC              ;

        RST     10H             ; CALBAS
        DEFW    $0030           ; main BC-SPACES

        LD      (HL),$80        ;
        EX      DE,HL           ;
        POP     DE              ;
        PUSH    HL              ;
        CALL    L0A60           ; routine LV-ANY
        POP     HL              ;

        RST     10H             ; CALBAS
        DEFW    $08CE           ; main ME-CTRLX

; ---

;; TST-MR-M
L098C:  LD      A,(IX+$04)      ; channel letter
        CP      $CD             ; 'M' + $80 ?
        JR      NZ,L0998        ; forward to TST-MR-N

        CALL    L138E           ; routine CLOSE-M2
        JR      L09A4           ; forward to MERGE-END

; ---

;; TST-MR-N
L0998:  BIT     3,(IY+$7C)      ; sv FLAGS_3
        JR      Z,L09A4         ; forward to MERGE-END

        CALL    L0FAE           ; routine SEND-NEOF
        CALL    L17B7           ; routine RCL-T-CH

;; MERGE-END
L09A4:  JP      L05C1           ; jump to END1

; ---

;; LD-PR-AR
L09A7:  LD      DE,($5CE7)      ; sv HD_0B
        LD      HL,($5CE1)      ; sv L_STR2
        PUSH    HL              ;
        LD      A,H             ;
        OR      L               ;
        JR      NZ,L09B9        ; forward to LD-PROG

        INC     DE              ;
        INC     DE              ;
        INC     DE              ;
        EX      DE,HL           ;
        JR      L09C2           ; forward to TST-SPACE

; ---

;; LD-PROG
L09B9:  LD      HL,($5CDF)      ; sv D_STR2 (+1) length of data
        EX      DE,HL           ;
        SCF                     ;
        SBC     HL,DE           ;
        JR      C,L09CB         ; forward to TST-TYPE

;; TST-SPACE
L09C2:  LD      DE,$0005        ;
        ADD     HL,DE           ;
        LD      B,H             ;
        LD      C,L             ;

        RST     10H             ; CALBAS
        DEFW    $1F05           ; main TEST-ROOM

;   Note. that before the above call, interrupts are disabled and the motor
;   of the microdrive is running.  If there should be insufficient room,
;   then the processor stops at the HALT instruction at address $1303
;   (MAIN-4), in the main ROM, while trying to output the "Out of Memory"
;   report.  This could be corrected by replacing the above 3 bytes to a
;   call to a 6-byte subroutine which carries out the same instructions
;   between an EI/DI pair.  In the production of the "Out of Memory" report
;   this ROM will be paged again by the instruction fetch at 0008. The
;   motors are stopped at START-4 and then Control will then pass to the
;   other ROM to execute the "LD A,(HL)", then back to this ROM to eliminate
;   the "OK" message before a final switch to the Main ROM for the actual
;   message text.

;; TST-TYPE
L09CB:  POP     HL
        LD      A,($5CE6)       ; sv HD_00
        AND     A
        JR      Z,L0A19         ; forward to SET-PROG

        LD      A,H
        OR      L
        JR      Z,L09F7         ; forward to CRT-NEW

        LD      A,(IX+$04)      ; channel letter
        CP      $CD             ; is character an inverted "M" ?
        JR      NZ,L09E2        ; forward to T-LD-NET

        LD      HL,($5CE4)      ; sv D_STR2
        JR      L09EC           ; forward to RCLM-OLD

; ---

;; T-LD-NET
L09E2:  BIT     3,(IY+$7C)      ; sv FLAGS_3
        JR      Z,L09EC         ; forward to RCLM-OLD

        LD      DE,$0114
        ADD     HL,DE

;; RCLM-OLD
L09EC:  DEC     HL
        LD      B,(HL)
        DEC     HL
        LD      C,(HL)
        DEC     HL
        INC     BC
        INC     BC
        INC     BC
        RST     10H             ; CALBAS
        DEFW    $19E8           ; main RECLAIM-2

;; CRT-NEW
L09F7:  LD      HL,($5C59)      ; sv E_LINE
        DEC     HL
        LD      BC,($5CE7)      ; sv HD_0B
        PUSH    BC
        INC     BC
        INC     BC
        INC     BC
        LD      A,($5CE3)       ; sv D_STR2
        PUSH    AF
        RST     10H             ; CALBAS
        DEFW    $1655           ; main MAKE-ROOM
        INC     HL
        POP     AF
        LD      (HL),A
        POP     DE
        INC     HL
        LD      (HL),E
        INC     HL
        LD      (HL),D
        INC     HL

;; END-LD-PR
L0A13:  CALL    L0A60           ; routine LV-ANY

        JP      L098C           ; jump to TST-MR-M

; ---

;; SET-PROG
L0A19:  RES     1,(IY+$7C)      ; sv FLAGS_3
        LD      DE,($5C53)      ; sv PROG
        LD      HL,($5C59)      ; sv E_LINE
        DEC     HL
        RST     10H             ; CALBAS
        DEFW    $19E5           ; main RECLAIM-1
        LD      BC,($5CE7)      ; sv HD_0B
        LD      HL,($5C53)      ; sv PROG
        RST     10H             ; CALBAS
        DEFW    $1655           ; main MAKE-ROOM
        INC     HL
        LD      BC,($5CEB)      ; sv HD_0F
        ADD     HL,BC
        LD      ($5C4B),HL      ; sv VARS
        LD      A,($5CEE)       ; sv HD_11_hi
        LD      H,A
        AND     $C0
        JR      NZ,L0A52        ; forward to NO-AUTO

        SET     1,(IY+$7C)      ; sv FLAGS_3
        LD      A,($5CED)       ; sv HD_11
        LD      L,A
        LD      ($5C42),HL      ; sv NEWPPC
        LD      (IY+$0A),$00    ; sv NSPPC

;; NO-AUTO
L0A52:  LD      HL,($5C53)      ; sv PROG
        LD      DE,($5CE7)      ; sv HD_0B
        DEC     HL
        LD      ($5C57),HL      ; sv DATADD
        INC     HL
        JR      L0A13           ; back to END-LD-PR

; ----------------------------
; THE 'LOAD OR VERIFY' ROUTINE
; ----------------------------
;   This routine is able to either LOAD or VERIFY a block of bytes, from any 
;   of the three possible binary sources, A Microdrive cartridge, the Binary
;   "B" RS232 channel or the Network "N" channel.
;   The block could be a program, code bytes or an array and the first 
;   receiving location is in HL and the length in DE.

;; LV-ANY
L0A60:  LD      A,D             ; test the length
        OR      E               ; for zero.
        RET     Z               ; return if so.

        LD      A,(IX+$04)      ; fetch channel letter
        CP      $CD             ; is letter "M" + $80 ?

        JR      NZ,L0A6E        ; forward, if not, to LV-BN to load from 
                                ; the B channel or network.

; else is a temporary "M" channel so load or verify and then return.

        CALL    L199A           ; routine LV-MCH loads or verifies a block
                                ; of code from microdrive.

        RET                     ; return after called routine.

; ---

; Load or Verify from B channel or Network.

;; LV-BN
L0A6E:  PUSH    HL              ; save address.
        PUSH    DE              ; save byte count.
        BIT     3,(IY+$7C)      ; test FLAGS_3 - using network ?
        JR      Z,L0A7D         ; forward, if not, to LV-B

; Load or Verify from "N" channel.

;; LV-N
L0A76:  CALL    L0DAF           ; routine NCHAN-IN
        JR      NC,L0A76        ; back to LV-N

        JR      L0A82           ; forward to LV-BN-E

; ---

; Load or Verify from "B" channel.

;; LV-B
L0A7D:  CALL    L0B88           ; routine BCHAN-IN
        JR      NC,L0A7D        ; back to LV-B

; Load or Verify "B","N" end test.

;; LV-BN-E
L0A82:  POP     DE              ; restore code length.
        DEC     DE              ; and decrement.
        POP     HL              ; restore load address.

        BIT     7,(IY+$7C)      ; test FLAGS_3 - verify operation.
        JR      NZ,L0A8E        ; forward, if so missing load, to VR-BN

        LD      (HL),A          ; load the byte into memory.
        JR      L0A93           ; forward to LVBN-END

; ---

; Verify "B" or "N" bytes.

;; VR-BN
L0A8E:  CP      (HL)            ; compare the received byte with the byte in
                                ; memory.
        JR      Z,L0A93         ; forward, with match, to LVBN-END.

        RST     20H             ; Shadow Error Restart
        DEFB    $15             ; 'Verification has failed'

; ---

; Load or Verify "B","N" end.

;; LVBN-END
L0A93:  INC     HL              ; increment the address.
        LD      A,E             ; test the byte 
        OR      D               ; counter for zero.
        JR      NZ,L0A6E        ; back, if not, to LV-BN

        RET                     ; return.

; --------------------------------
; THE 'LOAD "RUN" PROGRAM' ROUTINE
; --------------------------------
;

;; LOAD-RUN
L0A99:  LD      BC,$0001        ; set drive to one.
        LD      ($5CD6),BC      ; update D_STR1 drive number.

        LD      BC,$0003        ; length of "run" is three.
        LD      ($5CDA),BC      ; update N_STR1 length of filename.

        LD      BC,L0ACA        ; addr: NAME-RUN (below)
        LD      ($5CDC),BC      ; update A_STR1 - address of filename.

        SET     4,(IY+$7C)      ; update FLAGS_3 signal a LOAD operation.

        CALL    L0753           ; routine PROG sets up the first seven header 
                                ; bytes for a program.

        LD      HL,$5CE6        ; set start to HD_00
        LD      DE,$5CDE        ; set destination to D_STR2
        LD      BC,$0009        ; nine bytes are copied.
                                ; Note. should be seven but is mostly harmless.

        LDIR                    ; block copy.

        SET     7,(IY+$0A)      ; update Main NSPPC - signal no jump to be made.

        CALL    L1971           ; routine F-M-HEAD loads the header type 
                                ; record for the 'run' file and populates
                                ; the nine locations HD_00 to HD_11.

        JP      L08F6           ; jump back to TEST-TYPE to test that type is
                                ; 'program' and load the rest.

; ---

;; NAME-RUN
L0ACA:  DEFM    "run"           ; the filename "run"

; *******************************************
; **  T H E   R S 2 3 2   R O U T I N E S  **
; *******************************************

; ----------------------------------------
; THE 'SET "BAUD" SYSTEM VARIABLE' ROUTINE
; ----------------------------------------
;

;; SET-BAUD
L0ACD:  LD      BC,($5CD6)      ; sv D_STR1 drive number
        LD      HL,L0AF3        ; RS-CONSTS

;; NXT-ENTRY
L0AD4:  LD      E,(HL)
        INC     HL
        LD      D,(HL)
        INC     HL
        EX      DE,HL
        LD      A,H
        CP      $4B             ;
        JR      NC,L0AE8        ; forward to END-SET

        AND     A
        SBC     HL,BC
        JR      NC,L0AE8        ; forward to END-SET

        EX      DE,HL
        INC     HL
        INC     HL
        JR      L0AD4           ; loop back to NXT-ENTRY

; ---

;; END-SET
L0AE8:  EX      DE,HL
        LD      E,(HL)
        INC     HL
        LD      D,(HL)
        LD      ($5CC3),DE      ; sv BAUD
        JP      L05C1           ; jump to END1

; ------------------------------------
; THE 'RS232 TIMING CONSTANTS' ROUTINE
; ------------------------------------
;

;; RS-CONSTS
L0AF3:  DEFW    $0032           ;
        DEFW    $0A82           ;
        DEFW    $006E           ;
        DEFW    $04C5           ;
        DEFW    $012C           ;
        DEFW    $01BE           ;
        DEFW    $0258           ;
        DEFW    $00DE           ;
        DEFW    $04B0           ;
        DEFW    $006E           ;
        DEFW    $0960           ;
        DEFW    $0036           ;
        DEFW    $12C0           ;
        DEFW    $001A           ;
        DEFW    $2580           ;
        DEFW    $000C           ;
        DEFW    $4B00           ;
        DEFW    $0005           ;

; ----------------------------------------------
; THE 'OPEN RS232 CHANNEL IN CHANS AREA' ROUTINE
; ----------------------------------------------
;

;; OP-RS-CH
L0B17:  LD      HL,($5C53)      ; use system variable PROG to address the
                                ; location following the Channels area.
        DEC     HL              ; step back to the end-marker.
        LD      BC,$000B        ; eleven bytes of room required.
        PUSH    BC              ; save bytes

        RST     10H             ; CALBAS
        DEFW    $1655           ; main routine MAKE-ROOM opens up the space.
                                ; register HL points to location before room.

        POP     BC              ; bring back the eleven bytes.

        PUSH    DE              ; save DE briefly
        CALL    L1A82           ; routine REST-N-AD adjusts the dynamic memory
                                ; pointers to filenames in D_STR1 and D_STR2.
        POP     DE              ; restore DE.

        LD      HL,L0B76 - 1    ; last byte of T-Channel info.
        LD      BC,$000B        ; eleven bytes to copy.
        LDDR                    ; block copy downwards.

        INC     DE              ;
        LD      A,($5CD9)       ; sv L_STR1 device letter.
        CP      $42             ; is it "B" ?
        RET     NZ              ; return as must be "T".

; but if this is to be a binary channel then overwrite the letter and the output
; and input routines.

        PUSH    DE              ;

        LD      HL,$0004        ;
        ADD     HL,DE           ;

        LD      (HL),$42        ; 'B'
        INC     HL              ;

        LD      DE,L0D07        ; address B-CHAN-OUT
        LD      (HL),E          ;
        INC     HL              ;
        LD      (HL),D          ;
        INC     HL              ;

        LD      DE,L0B7C        ; address B-INPUT
        LD      (HL),E          ;
        INC     HL              ;
        LD      (HL),D          ;

        POP     DE              ;
        RET                     ; return.

; ----------------------------------------
; THE 'ATTACH CHANNEL TO A STREAM' ROUTINE
; ----------------------------------------
;

;; OP-RSCHAN
L0B4E:  CALL    L0B17           ; routine OP-RS-CH

;; OP-STREAM
L0B51:  LD      HL,($5C4F)      ; sv CHANS
        DEC     HL
        EX      DE,HL
        AND     A
        SBC     HL,DE
        EX      DE,HL
        LD      HL,$5C16        ; sv STRMS_00
        LD      A,($5CD8)       ; sv D_STR1
        RLCA
        LD      C,A
        LD      B,$00
        ADD     HL,BC
        LD      (HL),E
        INC     HL
        LD      (HL),D
        JP      L05C1           ; jump to END1

; ----------------------
; THE '"T" CHANNEL DATA'
; ----------------------
; the eleven-byte "T" CHANNEL descriptor.

;; TCHAN-DAT
L0B6B:  DEFW    $0008           ; main ERROR-1
        DEFW    $0008           ; main ERROR-1
        DEFB    $54             ; character "T"
        DEFW    L0C3A           ; TCHAN-OUT
        DEFW    L0B76           ; T-INPUT
        DEFW    $000B           ; channel length - 11 bytes.

; -------------------------------
; THE '"T" CHANNEL INPUT' ROUTINE
; -------------------------------
;

;; T-INPUT
L0B76:  LD      HL,L0B82        ; address of routine TCHAN-IN
        JP      L0D5A           ; jump to CALL-INP

; -------------------------------
; THE '"B" CHANNEL INPUT' ROUTINE
; -------------------------------
;

;; B-INPUT
L0B7C:  LD      HL,L0B88        ; address of routine BCHAN-IN
        JP      L0D5A           ; jump to CALL-INP

; ---------------------------------------
; THE '"T" CHANNEL INPUT SERVICE' ROUTINE
; ---------------------------------------
;

;; TCHAN-IN
L0B82:  CALL    L0B88           ; routine BCHAN-IN
        RES     7,A
        RET

; ---------------------------------------
; THE '"B" CHANNEL INPUT SERVICE' ROUTINE
; ---------------------------------------
; (Hook Code: $1D)

;; BCHAN-IN
L0B88:  LD      HL,$5CC7        ; sv SER_FL
        LD      A,(HL)          ;
        AND     A               ;
        JR      Z,L0B95         ; forward to REC-BYTE

        LD      (HL),$00        ;
        INC     HL              ;
        LD      A,(HL)          ;
        SCF                     ;

        RET                     ; Return.

; ---

;; REC-BYTE
L0B95:  CALL    L163E           ; routine TEST-BRK

        DI                      ; Disable Interrupts

        LD      A,($5CC6)       ; sv IOBORD
        OUT     ($FE),A

        LD      DE,($5CC3)      ; sv BAUD
        LD      HL,$0320        ; 800d.
        LD      B,D             ;
        LD      C,E             ;
        SRL     B               ;
        RR      C               ;
        LD      A,$FE           ;
        OUT     ($EF),A         ;

;; READ-RS
L0BAF:  IN      A,($F7)         ; bit 7 is input serial data (txdata)
        RLCA                    ;
        JR      NC,L0BC3        ; forward to TST-AGAIN

        IN      A,($F7)         ;
        RLCA                    ;
        JR      NC,L0BC3        ; forward to TST-AGAIN

        IN      A,($F7)         ;
        RLCA                    ;
        JR      NC,L0BC3        ; forward to TST-AGAIN

        IN      A,($F7)         ;
        RLCA                    ;
        JR      C,L0BCF         ; forward to START-BIT

;; TST-AGAIN
L0BC3:  DEC     HL              ;
        LD      A,H             ;
        OR      L               ;
        JR      NZ,L0BAF        ; back to READ-RS

        PUSH    AF              ;
        LD      A,$EE           ;
        OUT     ($EF),A         ;
        JR      L0BEE           ; forward to WAIT-1

; ---

;; START-BIT
L0BCF:  LD      H,B             ; Load HL with halved BAUD value.
        LD      L,C             ;

        LD      B,$80           ; Load B with the start bit.

        DEC     HL              ; Reduce the counter by the time for the four
        DEC     HL              ; tests.
        DEC     HL              ;

;; SERIAL-IN
L0BD6:  ADD     HL,DE           ; Add the BAUD value.
        NOP                     ; (4) a timing value.

;; BD-DELAY
L0BD8:  DEC     HL              ; (6) Delay for 26 * BAUD
        LD      A,H             ; (4)
        OR      L               ; (4)
        JR      NZ,L0BD8        ; (12) back to BD-DELAY

        ADD     A,$00           ; (7) wait
        IN      A,($F7)         ; Read a bit.
        RLCA                    ; Rotate bit 7 to carry.
        RR      B               ; pick up carry in B
        JR      NC,L0BD6        ; back , if no start bit, to SERIAL-IN

        LD      A,$EE           ; Send CTS line low  (comms data 0 also)
        OUT     ($EF),A         ; send to serial port

        LD      A,B             ; Transfer the received byte to A.
        CPL                     ; Complement.
        SCF                     ; Set Carry to signal success.
        PUSH    AF              ; (*) push the success flag.

;   The success and failure (time out) paths converge here with the HL register
;   holding zero.

;; WAIT-1
L0BEE:  ADD     HL,DE           ; (11) transfer DE (BAUD) to HL.

;; WAIT-2
L0BEF:  DEC     HL              ; ( 6) delay for stop bit.
        LD      A,L             ; ( 4)
        OR      H               ; ( 4)
        JR      NZ,L0BEF        ; (12/7) back to WAIT-2

;   Register HL is now zero again.

        ADD     HL,DE           ; HL = 0 + BAUD
        ADD     HL,DE           ; HL = 2 * BAUD
        ADD     HL,DE           ; HL = 3 * BAUD

;   The device at the other end of the cable (not a Spectrum) may send a 
;   second byte even though CTS (Clear To Send) is low.

;; T-FURTHER
L0BF7:  DEC     HL              ; Decrement counter.
        LD      A,L             ; Test for
        OR      H               ; zero.
        JR      Z,L0C34         ; forward, if no second byte, to END-RS-IN

        IN      A,($F7)         ; Read TXdata.
        RLCA                    ; test the bit read.
        JR      NC,L0BF7        ; back, if none,  to T-FURTHER

;   As with first byte, TXdata must be high four four tests.

        IN      A,($F7)         ;
        RLCA                    ;
        JR      NC,L0BF7        ; back to T-FURTHER

        IN      A,($F7)         ;
        RLCA                    ;
        JR      NC,L0BF7        ; back to T-FURTHER

        IN      A,($F7)         ;
        RLCA                    ;
        JR      NC,L0BF7        ; back to T-FURTHER

;   A second byte is on its way and is received exactly as before.

        LD      H,D             ;
        LD      L,E             ;
        SRL     H               ;
        RR      L               ;
        LD      B,$80           ;
        DEC     HL              ;
        DEC     HL              ;
        DEC     HL              ;

;; SER-IN-2
L0C1B:  ADD     HL,DE           ;
        NOP                     ; timing.

;; BD-DELAY2
L0C1D:  DEC     HL              ;
        LD      A,H             ;
        OR      L               ;
        JR      NZ,L0C1D        ; back to BD-DELAY2

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

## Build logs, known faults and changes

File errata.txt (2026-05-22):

v1.0
====

Transistor Q1 is rotated. Needs turning 90deg anticlockwise.
- Done on board #2

"ROM Acc 3V3" is on the silkscreen, test point was removed.
Same for "GND" just above U4.
- Done on board #2

The direction for the data bus level shifter needs to be
ROM_READ_INV, not /RD.
 - Cut ZXRD track on back of board #2
 - Picked up ROM_READ_INV from OR output (pin 9) and
   connected to DIR (pin 1) on level shifter U4
- Done on board #2
 
Move the GND via from pin 19 on U4, it's under the chip and
I can't get to it. This is /OE.
- Done on board #2

Remove level shifter U2
 - Bridged across gap on board #2
 - Removed on board #2

Remove level shifter U3
 - Bridged across gap on board #2
 - Removed on board #2

All the above were fixed (by hand) in v1.1

v1.1
====

Disconnect the 3V3s for all the Picos. I've got the outputs
of 3 regulators tied together. Separate into 3 supplies.
- Done on v1.2 of the board
- Cut 3V3 track to Pico2 on current board
: Need to cut 3v3 track to pico3 on current board

Change the dbus level shifter direction control from hardware to
software. Wire GPIO27 of Pico2 as an input for the ROM_READ_INV
signal, and GPIO28 as an output to the data bus level shifter's DIR
pin. This will allow the data bus to reverse direction on
memory reads, and also on IO request reads.
- Done on board #2,
- Done on v1.2 of the board

Remove the level shifter U202 which does IORQ, RD and WR.
These signals are permanently ZX->Pico so don't need shifting.
- Bridged on board #1
- Done on v1.2 of the board

I need to connect the /WAIT signal on the edge connector to GPIO18
on the IO Pico.
- Done on board #2
- Done on v1.2 of the board

v1.2
====

Make sure the GPIOs which share the ADC are not used for 5V. IO Pico
has ROM_READ_INV going into GPIO27. I need another level shifter.
I'm out of GPIOs.
- Level shifter has been added on v1.2 schematic
: I won't do it on board #1, adding the level shifter will be too
   difficult.
Make IO PIco GPIO27 an output (it's an ADC GPIO)
- Moved ROM_READ_INV to GPIO15 and ZXWAIT to GPIO27. That makes
  the signal on GPIO27 an output
- Done on board #1 and schematic
Set up the PSRAM connection on SPI0. That's GPIOs 16 to 19.
- Done on board #1 and schematic

Untangle the bus pins on all the Picos. Make databus D0 to D7
in sequence, then address lines. I thought simplifying the layout
process would make things easier, but actually, keeping the
software simple and fast has more benefit.
- Done on schematic, both Pico1 and Pico2
: Won't be doing this on board #1, too distruptive

Have Pico1 tell Pico2 that one of its ports (0xE7 or 0xEF) is on the
address bus. Then Pico2 can do away with 7 address lines.
- Done on board #1
- Signal from Pico1 GPIO27 to Pico2 GPIO13 done on board #1
- Keep A3 in place on Pico2

I need a signal from Pico2 to Pico1. Pico1 can't release the Z80
until Pico2 is ready to go. Pico2 changes the level shifter
direction, so Pico1 can't be the ROM until Pico2 is ready to go.
: Not required. If Pico1 boots slower than Pico2, then
   Pico2 will be running by the time Pico1 releases the Z80.
   I can just put a delay in the Pico1 code. Bit yuk, but I don't
   have the GPIO spare on Pico1.
:: Skip this for now

Add another couple of LEDs to the IO pico so I can see at a glance
if it's responding to IOs. Low priority, but if I have a couple
of GPIOs left this will be handy. Make sure the tracks are easy
to cut so i can reuse the GPIOs if I need to.
: Needs doing
:: No GPIO available, but I could connect an LED to the SPI
   slave enable signal? Check with AM whether that would 
   cause a problem

No pop the level shifter, I can probably just put a series resistor
on that signal line.

Test points required, bring them out to plated holes:
Test pin on Pico1, use pin 27, needed to trigger scope on particular
                   instruction, like INIR
Test pin on Pico2, use pin 27 here too, although there are more options
Test pin on Pico3, might as well use pin27 here too
ROM_READ_INV so I can see when Pico1 is telling Pico2 to change DIR
IORQ, RD and WR, make sure they're still available, they're useful
DIR_CHANGE from Pico2. I need to be able to see when Pico2 is changing the dbus direction.
: All need doing

v1.3 Final is for fabrication as board #2

v1.3 This version was made into board#2
====

Stagger the rows of data bus resistors. Offset each from the ones either side of
it so I can get the larger tweezers in. Or space them out a bit more.
: Done

First attempt NOPOPed the extra level shifter and added a series 100R resistor
into the ROM_READ signal. Need to confirm this worked. Its function is to protect
the Pico's ADC GPIO which I'm putting 5V into. I can't really tell if it works
unless and until the Pico fails, but I can at least confirm 100R is correct for
timing.
: It didn't work, the signal from the 3V3 side of the resistor was OK, but the
  level was wrong. It went from 2.5V to about 1.5V. I didn't investigate, I
  just took the R100 off and added the level shifter.
:: Remove the resistor footprint and NOPOP silkscreen
: Footprints removed

PSRAM footprint is missing the pin-1 dot on the silkscreen.
: Done on all components

ROMCS needs to support devices like Multiface which might be behind the device.
ROMCS into the ZX is permanently at 5V so as to disable the Spectrum's internal
ROM. Leave that alone. Link the rear edge connector ROMCS to the data bus level
shifter's /CE line via a weak pull down resistor. If a MF device pulls the line
up because it wants to supply the ROM, this will disable my level shifter and
the data bus will go HIZ.
: Done on schematic
: Tested on board, best I can

OLED CLK and SDA signals are transposed. I've labelled Pico3 GPIO4 as CLK and
GPIO5 and SDA. Check the A4 pin out diagram: GPIO4 is SDA and GPIO5 is CLK.
This is a hardware I2C bus so I can't switch them in software.
: Fixed on schematic and board

OLED screen is currently mounted upside and out the back. Work out where the
screen is going to be mounted and set the header correctly.
: Checked, mounting is correct

Rotary encoder connection is reversed on the board, it needs to stick out the
back for the pins to be connected up correctly. I think it needs flipping over
to have the encoder out the front.
: Checked, it's now correct

Rotary encoder pins are in sequence SW, DT, CLK, the example code I had ready
is CLK, DT, SW.
: Fixed in code

SPI is not suitable for the Pico to Pico comms. Switched to TP link, pins
GPIO0 and GPI1 on the UI Pico, crossed over to pins GPIO12 and GPIO13
on the IO Pico.
: Fixed on board (soldered wires)
: Fixed in code
: Fixed on schematic
: Fixed on new board

SD Card reader card detect pin needs connecting up.
: Done on board, I used GPIO28 as input
: Fixed on schematic
: Fixed on new board

LED output. I'm going to do it the easy way: 8 red LEDs connected to
8 GPIOs on the UI Pico. 330R with the 3mm reds I have looks perfect.
: Schematic updated, 2 LEDs tested on prototype
: New board has 8 signals and their return on a header

3-way RUN switch. I'm now having to power cycle the whole machine in order to
reset the UI Pico. A push to make switch which grounds all the RUN pins is
required.
: Tested, working on hardware
: Added to schematic
: Fixed on new board

ZX Reset switch, since mine is currently a dangling microswitch.
: Added to schematic
: Fixed on new board

Input switches. The GUI is too messy with just the rotary encoder. I need a couple
of switches as extra inputs, "Action" and "Cancel".
: Schematic updated
: Tested and working on breadboard. I used UI GPIOs 26 and 22.
: Fixed on new board

Test blipper points were on header connectors. Those header connectors have
been removed as they're no longer needed. The test blipper points are, so
ensure they're exposed to a footprint.
: Done

Case. 3D printed case required. I'm thinking of a tray to sit the lie-flat PCB in,
edge connectors front and back. Add a couple of holes for posts or screws.
: Holes in PCB added

Daughterboard, fits on top like a shield. The screen, 2 input switches and 8 LED
signals need to be on a separate daughterboard. This will be mounted over the top
of the PCB, above the Picos. Connected via 3 rows of header pins, sockets on PCB
which should be spaced out so they provide mechanical support for the top board.
The aluminium faceplate sits over the top of this. I need

3V3
GND
OLED CLK
OLED DAT
Action switch signal
Cancel switch signal
LEDs 0 to 7 inclusive
Common LEDs return

which is 15 signals, all carried via header pins.

This board should be 2.0mm if possible so it can handle the pressing of the buttons.
I've got the header right under the button so it should be OK at 1.6mm.
: Headers added to the PCB
: Daughterboard design needs doing

v1.4 This was the first lie-flat prototype
====

The rear edge connector footprint doesn't have the slot cut out.
I need to add that to the library footprint.

The LEDs on the daughterboard aren't connected properly. M0_LED
goes to the right most LED, which is correct. M1_LED goes to the
left most LED, it should go to the second rightmost. Not sure
how I managed that.
: Fixed in software

The rotary encoder's direction has somehow got reversed. I turn the
knob one way and the microdrive selector icon moves the other way.
...
On reflection, maybe it's right after all? I'm not sure which way
things should move in the MD selector or the files list.
: I tweaked the state machine, I think I'm happy with it now.

Sometimes a LED before the one which should light, lights. I think
this is due to the shift register approach of the LED motor-on design.
a CAT 8 sends the motor-on logic 1 to all 7 preceding microdrives. If
the status is picked up during that shift, whichever one has the current
shifted 1 will report as motor-on and the LED lights.
: Need to investigate and fix in software

The 3-way connector near the rotary encoder which is used to separate
the two boards is a bit flimsy. It bends over. Make it a 6 way.
: Needs doing

Any expansion which is plugged into the back will foul on the reset
switches if it's wider than the connector (many, probably most, are).
Move the switches. There's room for one near the SD card slot. The
other can stay in that corner but be turned out sideways, facing left.

The front of the case can't have a wall, it obstructs the connection
to the Spectrum. Knock out 2mm strips in the corners of the PCBs so
the case can go around at least a bit.
: Needs doing on main PCB
: Needs doing on daughterboard PCB

The Cancel and Action buttons are too far to the left. Spacing is correct,
but they need moving to the right so they centre on the rotary knob. The
distance moved will need to be reflected in the case holes.

Update time, May'26
===================

All the v1.4 stuff above, plus:

The 90deg edge connector is causing a problem. The main PCB lies too low
such that when it's plugged into the ZX the interface sits too low and the
ZX needs jacking up with foot stands.
: The solution is to use the regular straight through edge connector.
  Soldering will be tricker, but the PCB will sit quite a bit higher.
  The case base will need to be strengthed to support where it gets pressed.
  Even with this adjustment, there's no room underneath to put the Picos
  on the underside so the double layer design needs to stay.

The Picos can be soldered directly onto the board, but that means no access
to their USB ports. Programming will be via SWD only. With non-H Picos I'll
need to add a 3 pin header to each SWD port unless I can bring out the SWD
header somewhere on the board.
: When relaying out the board, create 3 3-pin headers for the Picos' SWD
  ports. If that's not possible, solder pins to the Picos directly.

With the Picos flat on the board the high headers aren't required. I can use
standard ones instead.
: Check standard header sockets are taller than a Pico.

I think all the above leaves the rotary switch module as the highest
component on the board. It can be soldered directly. Its securing nut
might be usable for anchoring down the top PCB or the case.
: Investigate the options

Ideally the two boards will be joined electronically via a ribbon cable, and
separated via spacers. The header pins and sockets are a pain.
: Investigate the options

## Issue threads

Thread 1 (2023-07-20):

No slot in the rear edge connector

derekfountain, 2023-07-20:
The KiCAD footprint I used for the rear edge connector is sub-millimetre perfect, except for the bizarre omission of the locating slot. The gap is there for it, but it's not in the drill file.

I need to change either footprint for that connector, or the edge cuts for the lower board. In the meantime a Dremel is required.

derekfountain, 2023-08-27:
A little more detail for anyone trying to work around this.

There's nothing hidden in the inner layers:

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

Just the ground and power planes. So I think it's safe to make the cut with a Dremel as long as you double check there's no bridge between formed between GND and +5V before you plug it it.

On the top side of the board there's that diagonal link for ZXD0 (the ZX (+5V) side of the 0th data bus line) to pad A6. If the Dremel cuts that, it'll need to be repaired. A wire across the board from the Spectrum-side edge connector pin to the tip of the pad would be easiest.

On the underside of the board:

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

there's the via linking pad B6 to the ground plane. If that gets damaged, pads B6 and B7 will need to be reconnected to ground from some other GND source. It might not be necessary, depending on the device(s) being plugged in.

derekfountain, 2023-08-27:
Just to confirm (for someone not familiar with KiCad), this is the ground plane layer:

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

And these are the lines in the second internal layer:

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

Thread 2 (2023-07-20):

Reset switches foul the rear of the case

derekfountain, 2023-07-20:
The two reset switches protrude out of the back of the case, which turns out to be a bad decision because they foul the pass through edge connector. It's now not possible to plug an expansion interface into the back of the device if the expansion interface is wider than the edge connector itself.

I can move one of the switches "round the corner" so it protrudes out to the side. There's not enough room for both, so the second will need to find a new location.

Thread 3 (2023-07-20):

Lie flat design is a mistake

derekfountain, 2023-07-20:
I think on reflection the lie-flat design is a mistake. The tips of the 90deg edge connector, and all the TTH components, poke out the base of the device by a couple of mm, then the 3D printed case adds another 1mm. The lower PCB itself lies flush with the base of the ZX Spectrum, so this extra thickness below the lower PCB prevents the Spectrum and the interface sitting on the desk at the same level. See this image:

https://github.com/derekfountain/zx-spectrum-pico-interface-one/blob/main/images/case_offset.jpg

My bodge fix was to add 5mm spacers around the Spectrums rubber feet.

The ideal fix would be to create a design like the original Interface One, which sits partially under the rear of the Spectrum, tilting it at an angle. That's quite hard, the fittings and angles would need to be spot on to make it work.

I think the best fix is to work to reduce the size of the device and return to the upright design.

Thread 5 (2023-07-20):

Case needs a redesign

derekfountain, 2023-07-20:
The case is not ideal. It adds unnecessary bulk. The friction-fit idea of one piece sliding over the top of the other seems to work well with cardboard boxes, but with PLA it doesn't seem to work.

I'm honestly not sure what the correct design would be. Two pieces with screw fittings or magnets to hold them together, maybe?

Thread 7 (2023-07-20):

SD card hot swap isn't supported

derekfountain, 2023-07-20:
I attempted to support SD card hot swap, but it's rather difficult. Every which way I turned, I found another corner case where data might get lost if the Spectrum writes to the MDR image after the SD card has been removed.

For now, hot swap of SD card is not supported.

derekfountain, 2023-07-20:
I won't attempt to fix this. After all, pulling cartridges out of the microdrives while the Spectrum is using them was asking for trouble in 1985.

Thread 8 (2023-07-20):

Spurious LED lighting up

derekfountain, 2023-07-20:
Just occasionally, when an LED should light up, one of the other LEDs also lights up. Just a quick flicker.

I'm pretty sure this is being caused by the Interface One's shift-register implementation of the motor control. It puts a 1 or 0 into the motor control for Microdrive 1, then shifts all those control values along the line 8 times.

I think the UI Pico is reading the status of the system as the shift is happening. On real microdrives the shift of a 1 along the line happens so quickly the LEDs don't get chance to light up before they're turned off again. On this system the status can be read just as the logic one is shifting along. An LED lights up and won't be turned off again until the next status read happens 100ms later, so the LED is turned on for 100ms before being turned off again.

I'm not quite sure what the solution is. Don't update status when motor control is happening is the obvious one. There's probably other ways to fix it.

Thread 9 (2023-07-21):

Increase size of edge connector footprint holes

derekfountain, 2023-07-21:
The main reason the board doesn't lie lower than it does is the way the 90degree edge connector connects to it. The pins of the connector go through the holes, but only by a couple of mm because the holes are quite small and the pins are tapered.

If I replace the holes on that connector footprint with some slightly larger ones the connector pins will press through further and the board will sit higher.

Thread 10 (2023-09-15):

Bottom Board.

chuckcaley, 2023-09-15:
There's no files for the bottom board?
Are you going to release them or are you still working on them?
TIA

derekfountain, 2023-09-15:
Everything is complete and released. What "files" are you referring to?

chuckcaley, 2023-09-15:
The UI daugther board is there but the board with the pico's on. We also have the parts listed on the main page but there is no info on the main board with the pico's and sd card etc. eg. board/schematic files or gerbers

chuckcaley, 2023-09-15:
My bad. I have found them Wasn't expexting the files to be in the srom folder. Sorry for the trouble.

derekfountain, 2023-09-16:
No problem, I'm keen to hear from people who are interested.

I've updated the README with a bit of guidance for anyone else who is lost. :)

Closed 2023-09-16.

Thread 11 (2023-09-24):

Incompatible with devices which provide a non-standard ROM

derekfountain, 2023-09-24:
If the user adds a device onto the rear of the ZSES which provides its own ROM in place of the Spectrum's original 16K ROM, that device won't work. The ZSES ties the /ROMCS line to +5V meaning that the Spectrum's internal ROM is disabled. This is normally fine because the ROM Pico provides a copy of the original 16K ROM image and returns data from it for non-IF1 ROM reads. But if another device wants to provide a different ROM image, it won't work. The ZSES controls the ROM memory space.

The original IF1 doesn't carry an original 16K ROM image. It only asserts /ROMCS when it wants to page in the IF1 ROM, leaving the normal ROM either alone, or to any other device which wants to control it. This makes for an incompatibility, one which someone who owns such a device has reported to me.

The solution is not obvious. Switching the /ROMCS line only when the IF1 ROM is paged in is simple enough, but there isn't a spare GPIO on the ROM Pico to do it with. Looking at the circuit, there's no easy way to free one up.

My intention is to address this, since it makes my device incompatible with the original IF1, albeit it in a very tight corner case. But as of this writing I don't know how to fix it.

derekfountain, 2023-10-03:
Someone pointed out here that using a Pico-alike board with more of the RP2040's GPIOs exposed might be helpful. Unfortunately I deleted the post by accident thinking it was something else! (Gibhub doesn't seem to have an undo for that.) But it's a good point, I only need one more GPIO, so that might help.

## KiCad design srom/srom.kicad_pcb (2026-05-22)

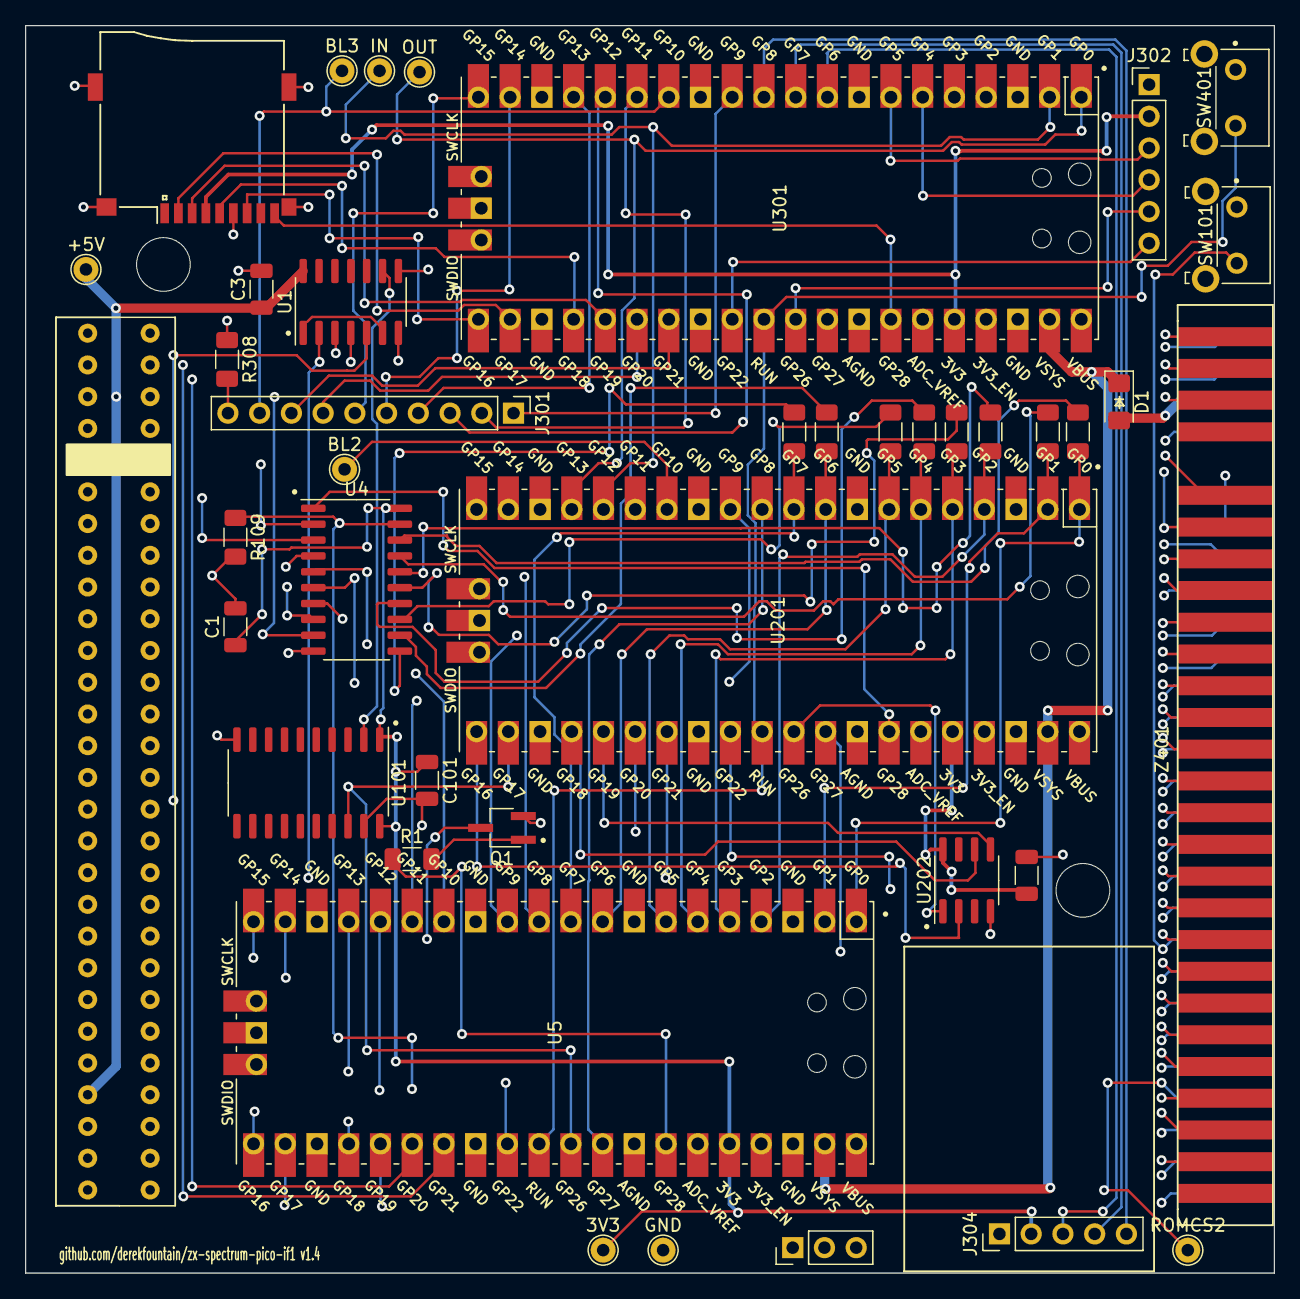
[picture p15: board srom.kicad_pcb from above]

Board: 4 copper layers, 100.0 x 99.8 mm, 40 parts (0 on the bottom side), 107 nets.

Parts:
3V3: TestPoint_THTPad_D2.0mm_Drill1.0mm
+5V: TestPoint_THTPad_D2.0mm_Drill1.0mm
BL2, BL3: TestPoint_THTPad_D2.0mm_Drill1.0mm
C1, C3, C101, C201: C_Small; C_1206_3216Metric
D1: D_Schottky; D_1206_3216Metric_Pad1.42x1.75mm_HandSolder
GND: TestPoint_THTPad_D2.0mm_Drill1.0mm
IN: TestPoint_THTPad_D2.0mm_Drill1.0mm
J301: Conn_01x10_Female; PinHeader_1x10_P2.54mm_Vertical
J302: Conn_01x06_Female; PinHeader_1x06_P2.54mm_Vertical
J304: Conn_01x05_Female; PinHeader_1x05_P2.54mm_Vertical
OUT: TestPoint_THTPad_D2.0mm_Drill1.0mm
Q1: PMBT2222A; TSOT-23_HandSoldering
R1: 1K; R_1206_3216Metric_Pad1.30x1.75mm_HandSolder
R101, R102, R103, R104, R105, R106, R107, R108: R150; R_1206_3216Metric_Pad1.30x1.75mm_HandSolder
R109: 1KR; R_1206_3216Metric_Pad1.30x1.75mm_HandSolder
R308: R330; R_1206_3216Metric_Pad1.30x1.75mm_HandSolder
ROMCS2: TestPoint_THTPad_D2.0mm_Drill1.0mm
SW101, SW401: SW_SPST; SW_Tactile_SKHH_Angled
U1: 4075; SOIC-14_3.9x8.7mm_P1.27mm
U4, U101: 74LS245; SO-20_5.3x12.6mm_P1.27mm
U5: Pico-1 ROM; RPi_Pico_SMD_TH
U201: Pico-2 IO; RPi_Pico_SMD_TH
U202: APS6404L-3SQR_PSRAM64Mbit; SOIC-8_3.9x4.9mm_P1.27mm
U301: Pico-3 UI; RPi_Pico_SMD_TH
XS301: 502p_SD_ebay-uSD-push_push_SMD-pak_breakout; Conn_uSDcard
Z1: ZX48Bus; ZX_Bus_Pin_Header
Z401: ZX48Bus; ZX_Bus_Edge_Connector

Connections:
3V3_PICO1: 3V3.1, C1.1, C101.1, J304.2, U4.20 (VCC), U5.36 (3V3), U101.1 (A->B), U101.20 (VCC)
3V3_PICO2: C201.1, U201.36 (3V3), U202.8 (VCC)
3V3_PICO3: J302.2, U301.36 (3V3), XS301.4 (Vdd)
+5V: +5V.1, C3.1, D1.2 (A), U1.14 (VDD), Z1.B3 (+5v), Z1.B25 (~ROMCS), Z401.B3 (+5v)
ACTION_SW: J302.5, U301.31 (GPIO26_ADC0)
CANCEL_SW: J302.6, U301.29 (GPIO22)
D0: R101.2, U5.1 (GPIO0), U201.1 (GPIO0)
D1: R102.2, U5.2 (GPIO1), U201.2 (GPIO1)
D2: R103.2, U5.4 (GPIO2), U201.4 (GPIO2)
D3: R104.2, U5.5 (GPIO3), U201.5 (GPIO3)
D4: R105.2, U5.6 (GPIO4), U201.6 (GPIO4)
D5: R106.2, U5.7 (GPIO5), U201.7 (GPIO5)
D6: R107.2, U5.9 (GPIO6), U201.9 (GPIO6)
D7: R108.2, U5.10 (GPIO7), U201.10 (GPIO7)
DBUS_DIRECTION: U4.1 (A->B), U201.34 (GPIO28_ADC2)
GND: C1.2, C3.2, C101.2, C201.2, GND.1, J302.1, J304.1, Q1.2 (E), R109.2, R308.1, SW101.1 (A), SW401.1 (A), U1.7 (VSS), U1.8, U4.10 (GND), U5.3 (GND), U5.8 (GND), U5.13 (GND), U5.18 (GND), U5.23 (GND), U5.28 (GND), U5.33 (AGND), U5.38 (GND), U5.42 (GND), U101.10 (GND), U101.19 (CE), U201.3 (GND), U201.8 (GND), U201.13 (GND), U201.18 (GND), U201.23 (GND), U201.28 (GND), U201.33 (AGND), U201.38 (GND), U201.42 (GND), U202.4 (VSS), U301.3 (GND), U301.8 (GND), U301.13 (GND), U301.18 (GND), U301.23 (GND), U301.28 (GND), U301.33 (AGND), U301.38 (GND), U301.42 (GND), XS301.6 (GND), Z1.B6 (GND), Z1.B7 (GND), Z1.B14 (GND), Z401.B6 (GND), Z401.B7 (GND), Z401.B14 (GND)
IF1_PORT_ACTIVE: U5.32 (GPIO27_ADC1), U201.11 (GPIO8)
MD0_LED: J301.1, U301.12 (GPIO9)
MD1_LED: J301.2, U301.15 (GPIO11)
MD2_LED: J301.3, U301.16 (GPIO12)
MD3_LED: J301.4, U301.17 (GPIO13)
MD4_LED: J301.5, U301.19 (GPIO14)
MD5_LED: J301.6, U301.20 (GPIO15)
MD6_LED: J301.7, U301.26 (GPIO20)
MD7_LED: J301.8, U301.27 (GPIO21)
unnamed: J301.10, R308.2
unnamed: Q1.1 (B), R1.2
unnamed: R101.1, U4.18 (B0)
unnamed: R102.1, U4.17 (B1)
unnamed: R103.1, U4.16 (B2)
unnamed: R104.1, U4.15 (B3)
unnamed: R105.1, U4.14 (B4)
unnamed: R106.1, U4.13 (B5)
unnamed: R107.1, U4.12 (B6)
unnamed: R108.1, U4.11 (B7)
OLED_SCK: J302.3, U301.7 (GPIO5)
OLED_SDA: J302.4, U301.6 (GPIO4)
PICOS_RUN: SW401.2 (B), U5.30 (RUN), U201.30 (RUN), U301.30 (RUN)
PICO_PWR: D1.1 (K), U5.39 (VSYS), U201.39 (VSYS), U301.39 (VSYS)
PICO_RESET_Z80: R1.1, U5.34 (GPIO28_ADC2)
ROMCS2: R109.1, ROMCS2.1, U4.19 (CE), Z401.B25 (~ROMCS)
ROM_ACCESS_INV: U1.1, U1.6
ROM_READ_INV: U1.9, U101.2 (A0)
ROM_READ_INV_3V3: U5.31 (GPIO26_ADC0), U101.18 (B0), U201.22 (GPIO17)
ROT_CLK_A: J304.5, U301.11 (GPIO8)
ROT_DT_B: J304.4, U301.10 (GPIO7)
ROT_SW: J304.3, U301.9 (GPIO6)
SD_CARD_DETECT: U301.34 (GPIO28_ADC2), XS301.9 (CD)
SPI0_PSRAM_CLK: U201.24 (GPIO18), U202.6 (SCLK)
SPI0_PSRAM_MISO: U201.21 (GPIO16), U202.2 (SO/SIO)
SPI0_PSRAM_MOSI: U201.25 (GPIO19), U202.5 (SI/SIO)
SPI0_PSRAM_SLAVE_ENABLE: U201.31 (GPIO26_ADC0), U202.1 (~CE)
SPI0_SD_CLK: U301.24 (GPIO18), XS301.5 (CLK)
SPI0_SD_MISO: U301.21 (GPIO16), XS301.7 (DO/DAT0)
SPI0_SD_MOSI: U301.25 (GPIO19), XS301.3 (DI/CMD)
SPI0_SD_SLAVE_ENABLE: U301.22 (GPIO17), XS301.2 (CS/DAT3)
TEST_BLIPPER_P2: BL2.1, U201.14 (GPIO10)
TEST_BLIPPER_P3: BL3.1, J301.9, U301.14 (GPIO10)
UI_LINKIN: IN.1, U201.16 (GPIO12), U301.2 (GPIO1)
UI_LINKOUT: OUT.1, U201.17 (GPIO13), U301.1 (GPIO0)
ZX9V: Z1.B4 (+9V), Z401.B4 (+9V)
ZX12V: Z1.A22 (+12V), Z401.A22 (+12V)
ZX12VAC: Z1.A23 (+12VAC), Z401.A23 (+12VAC)
ZXA0: U5.11 (GPIO8), Z1.B9 (A0), Z401.B9 (A0)
ZXA1: U5.12 (GPIO9), Z1.B10 (A1), Z401.B10 (A1)
ZXA2: U5.14 (GPIO10), Z1.B11 (A2), Z401.B11 (A2)
ZXA3: U5.15 (GPIO11), U201.12 (GPIO9), Z1.B12 (A3), Z401.B12 (A3)
ZXA4: U5.16 (GPIO12), Z1.B24 (A4), Z401.B24 (A4)
ZXA5: U5.17 (GPIO13), Z1.B23 (A5), Z401.B23 (A5)
ZXA6: U5.19 (GPIO14), Z1.B22 (A6), Z401.B22 (A6)
ZXA7: U5.20 (GPIO15), Z1.B21 (A7), Z401.B21 (A7)
ZXA8: U5.21 (GPIO16), Z1.A26 (A8), Z401.A26 (A8)
ZXA9: U5.22 (GPIO17), Z1.B27 (A9), Z401.B27 (A9)
ZXA10: U5.24 (GPIO18), Z1.A27 (A10), Z401.A27 (A10)
ZXA11: U5.25 (GPIO19), Z1.B28 (A11), Z401.B28 (A11)
ZXA12: U5.26 (GPIO20), Z1.B2 (A12), Z401.B2 (A12)
ZXA13: U5.27 (GPIO21), Z1.A2 (A13), Z401.A2 (A13)
ZXA14: U1.4, Z1.B1 (A14), Z401.B1 (A14)
ZXA15: U1.3, Z1.A1 (A15), Z401.A1 (A15)
ZXBUSACK: Z1.B26 (~BUSACK), Z401.B26 (~BUSACK)
ZXBUSRQ: Z1.B19 (~BUSRQ), Z401.B19 (~BUSRQ)
ZXCLK: Z1.B8 (CLK), Z401.B8 (CLK)
ZXD0: U4.2 (A0), Z1.A6 (D0), Z401.A6 (D0)
ZXD1: U4.3 (A1), Z1.A7 (D1), Z401.A7 (D1)
ZXD2: U4.4 (A2), Z1.A8 (D2), Z401.A8 (D2)
ZXD3: U4.5 (A3), Z1.A11 (D3), Z401.A11 (D3)
ZXD4: U4.6 (A4), Z1.A12 (D4), Z401.A12 (D4)
ZXD5: U4.7 (A5), Z1.A10 (D5), Z401.A10 (D5)
ZXD6: U4.8 (A6), Z1.A9 (D6), Z401.A9 (D6)
ZXD7: U4.9 (A7), Z1.A3 (D7), Z401.A3 (D7)
ZXHALT: Z1.A15 (~HALT), Z401.A15 (~HALT)
ZXINT: Z1.A13 (~INT), Z401.A13 (~INT)
ZXIORQ: U201.26 (GPIO20), Z1.A17 (~IORQ), Z401.A17 (~IORQ)
ZXIORQGE: Z1.B13 (~IORQGE), Z401.B13 (~IORQGE)
ZXM1: U5.29 (GPIO22), Z1.A24 (~M1), Z401.A24 (~M1)
ZXMIN5V: Z1.A20 (-5V), Z401.A20 (-5V)
ZXMREQ: U1.5, Z1.A16 (~MREQ), Z401.A16 (~MREQ)
ZXNMI: Z1.A14 (~NMI), Z401.A14 (~NMI)
ZXRD: U1.2, U201.27 (GPIO21), Z1.A18 (~RD), Z401.A18 (~RD)
ZXRESET: Q1.3 (C), SW101.2 (B), Z1.B20 (~RESET), Z401.B20 (~RESET)
ZXRFSH: Z1.A25 (~RFSH), Z401.A25 (~RFSH)
ZXU: Z1.B18 (U), Z401.B18 (U)
ZXV: Z1.B17 (V), Z401.B17 (V)
ZXVIDEO: Z1.B15 (VIDEO), Z401.B15 (VIDEO)
ZXWAIT: U201.32 (GPIO27_ADC1), Z1.A21 (~WAIT), Z401.A21 (~WAIT)
ZXWR: U201.29 (GPIO22), Z1.A19 (~WR), Z401.A19 (~WR)
ZXY: Z1.B16 (Y), Z401.B16 (Y)

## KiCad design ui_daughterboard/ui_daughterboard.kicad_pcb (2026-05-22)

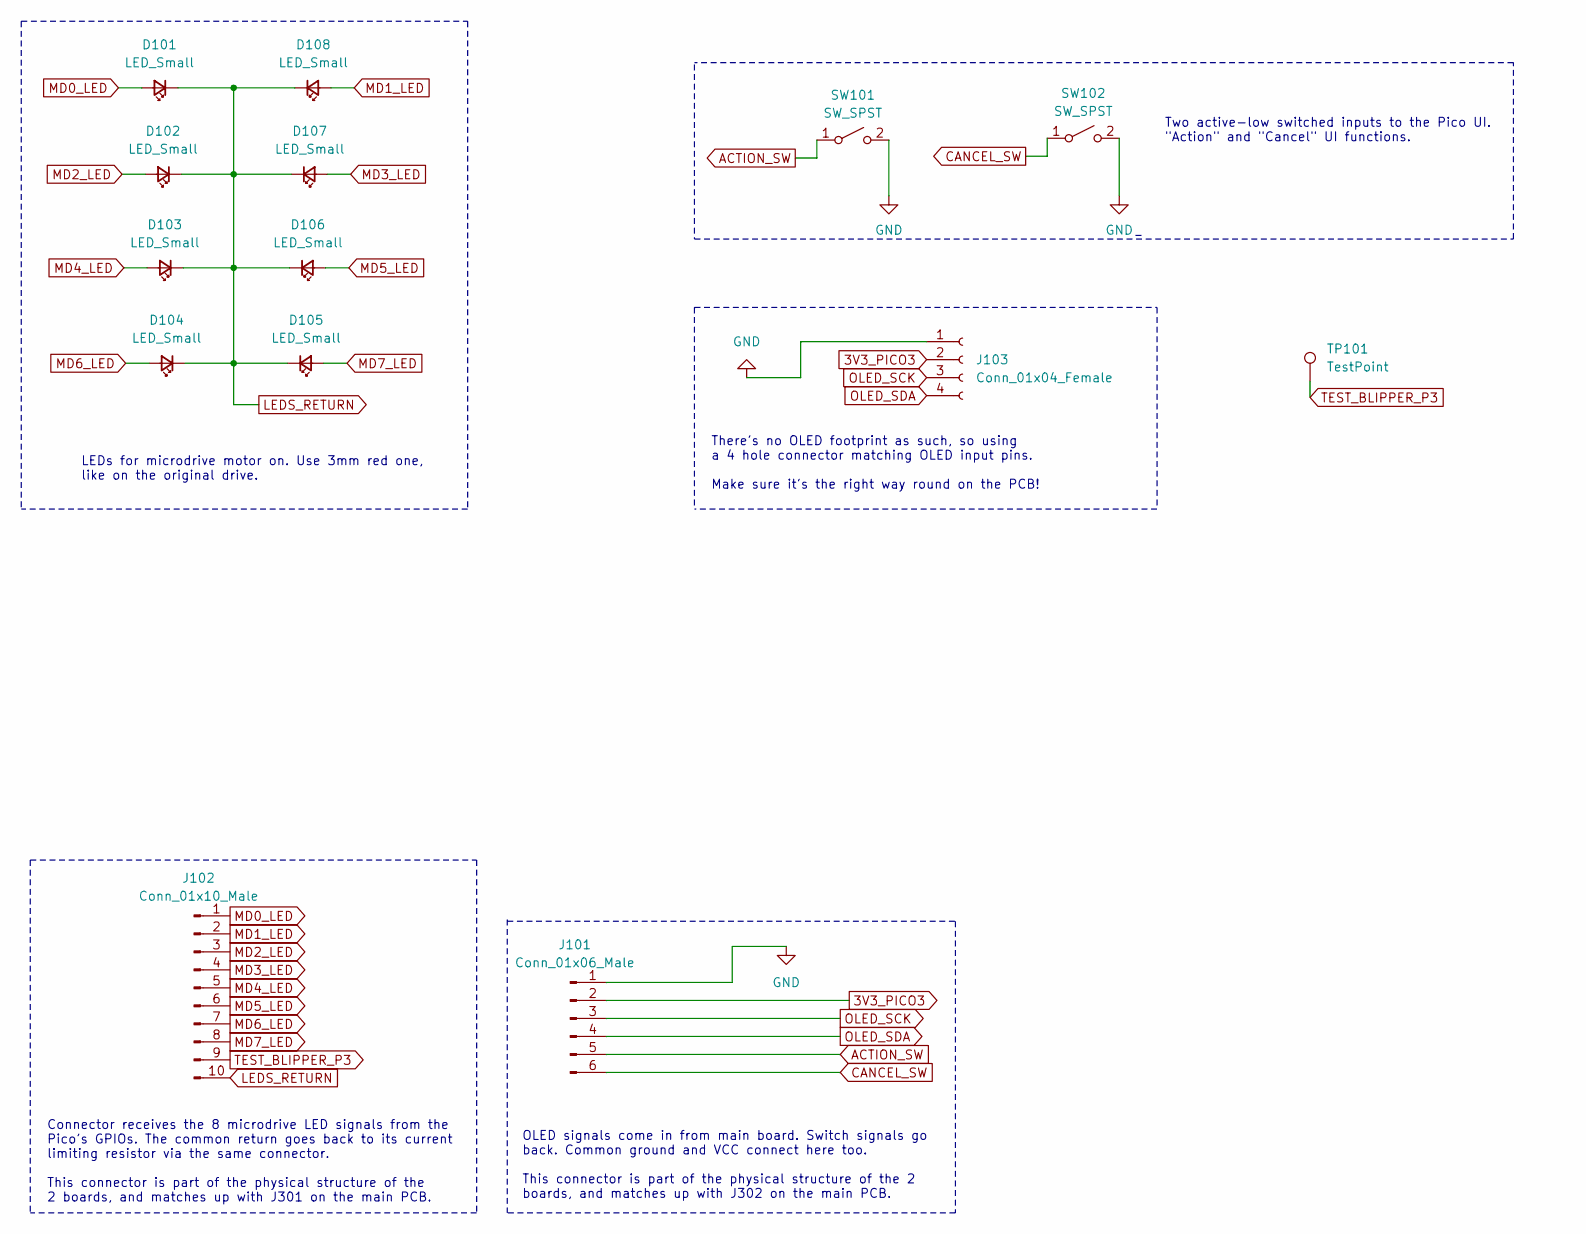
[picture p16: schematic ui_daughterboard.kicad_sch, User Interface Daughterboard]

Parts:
D101, D102, D103, D104, D105, D106, D107, D108: LED_Small; LED_D3.0mm
J101: Conn_01x06_Male; PinHeader_1x06_P2.54mm_Vertical
J102: Conn_01x10_Male; PinHeader_1x10_P2.54mm_Vertical
J103: Conn_01x04_Female; PinHeader_1x04_P2.54mm_Vertical
SW101, SW102: SW_SPST; SW_PUSH_6mm_H4.3mm
TP101: TestPoint; TestPoint_THTPad_D2.0mm_Drill1.0mm

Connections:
3V3_PICO3: J101.2, J103.2; also elsewhere on the board
ACTION_SW: J101.5, SW101.1 (A)
CANCEL_SW: J101.6, SW102.1 (A)
GND: J101.1, J103.1, SW101.2 (B), SW102.2 (B); also elsewhere on the board
LEDS_RETURN: D101.1 (K), D102.1 (K), D103.1 (K), D104.1 (K), D105.1 (K), D106.1 (K), D107.1 (K), D108.1 (K), J102.10
MD0_LED: D101.2 (A), J102.1
MD1_LED: D108.2 (A), J102.2
MD2_LED: D102.2 (A), J102.3
MD3_LED: D107.2 (A), J102.4
MD4_LED: D103.2 (A), J102.5
MD5_LED: D106.2 (A), J102.6
MD6_LED: D104.2 (A), J102.7
MD7_LED: D105.2 (A), J102.8
OLED_SCK: J101.3, J103.3
OLED_SDA: J101.4, J103.4
TEST_BLIPPER_P3: J102.9, TP101.1

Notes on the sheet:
Connector receives the 8 microdrive LED signals from the Pico's GPIOs. The common return goes back to its current limiting resistor via the same connector. This connector is part of the physical structure of the 2 boards, and matches up with J301 on the main PCB.
LEDs for microdrive motor on. Use 3mm red one, like on the original drive.
OLED signals come in from main board. Switch signals go back. Common ground and VCC connect here too. This connector is part of the physical structure of the 2 boards, and matches up with J302 on the main PCB.
There's no OLED footprint as such, so using a 4 hole connector matching OLED input pins. Make sure it's the right way round on the PCB!
Two active-low switched inputs to the Pico UI. "Action" and "Cancel" UI functions.

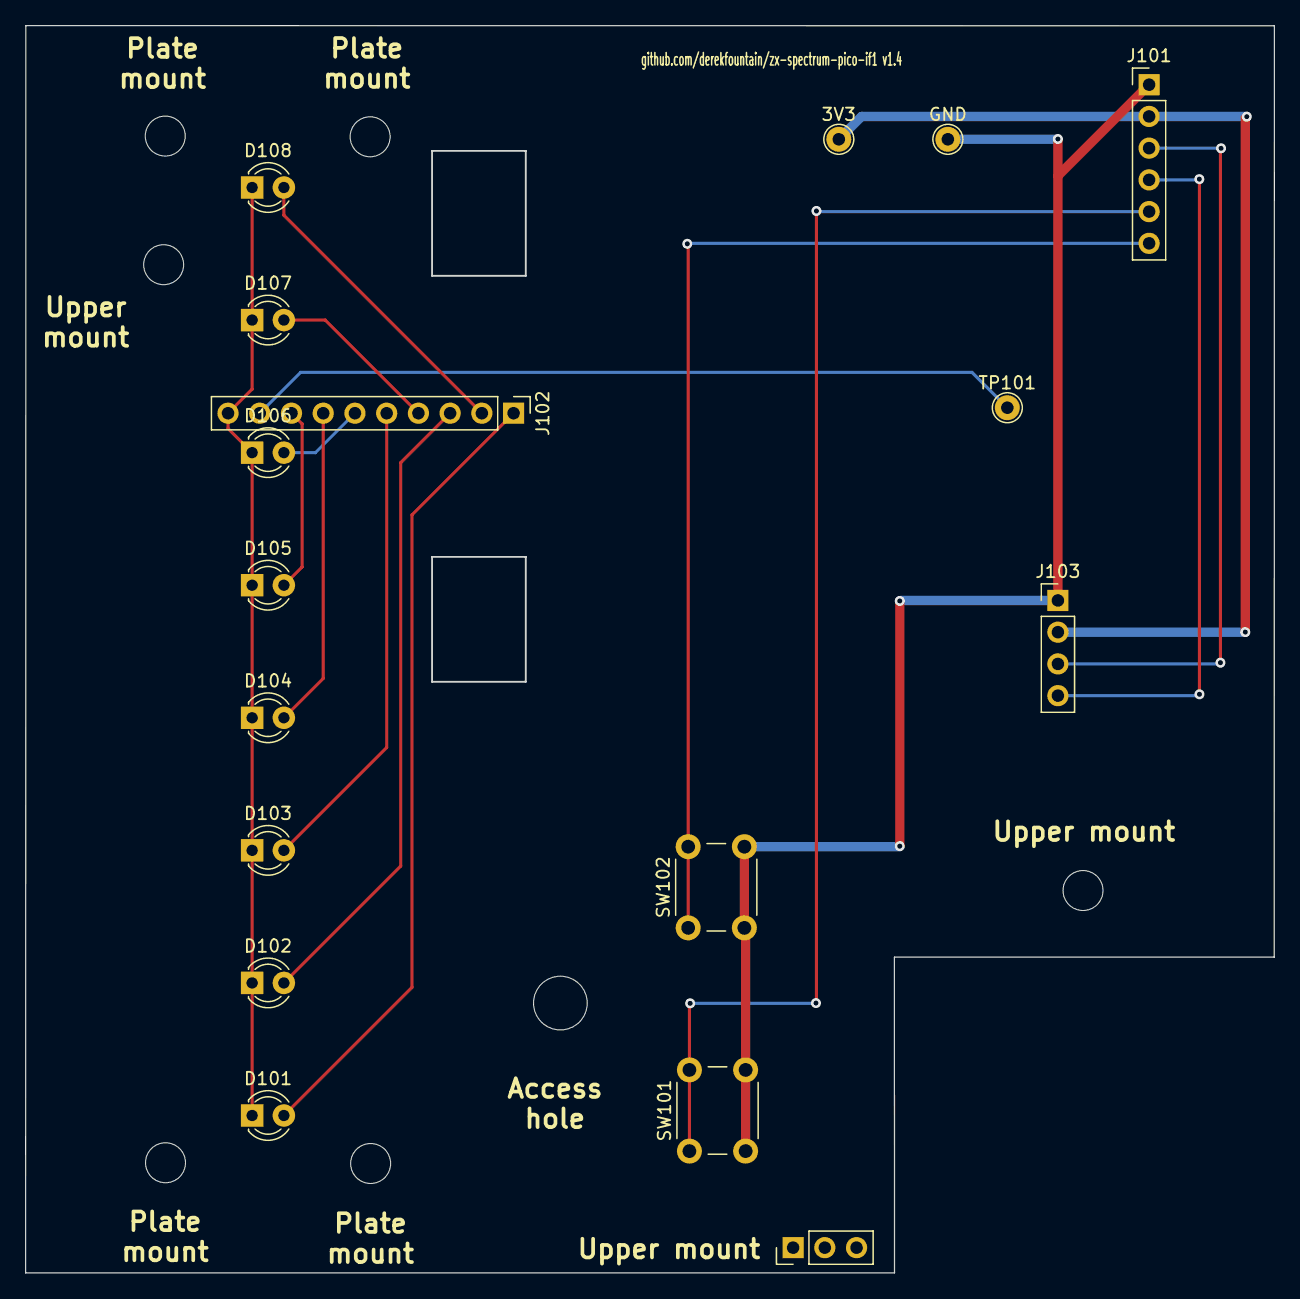
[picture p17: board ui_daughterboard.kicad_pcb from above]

Board: 2 copper layers, 100.0 x 99.9 mm, 16 parts (0 on the bottom side), 16 nets.

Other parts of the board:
3V3: TestPoint; TestPoint_THTPad_D2.0mm_Drill1.0mm
GND: TestPoint; TestPoint_THTPad_D2.0mm_Drill1.0mm

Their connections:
3V3_PICO3: 3V3.1; also elsewhere on the board
GND: GND.1; also elsewhere on the board

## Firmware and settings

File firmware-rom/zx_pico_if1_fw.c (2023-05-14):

/*
 * ZX Pico IF1 Firmware, a Raspberry Pi Pico based ZX Interface One emulator
 * Copyright (C) 2023 Derek Fountain
 * 
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
 * You should have received a copy of the GNU General Public License
 * along with this program; if not, write to the Free Software
 * Foundation, Inc., 51 Franklin Street, Fifth Floor, Boston, MA  02110-1301, USA.
 */

/*
 * cmake -DCMAKE_BUILD_TYPE=Debug ..
 * make -j10
 * sudo openocd -f interface/picoprobe.cfg -f target/rp2040.cfg -c "program ./zx_pico_if1_fw.elf verify reset exit"
 * sudo openocd -f interface/picoprobe.cfg -f target/rp2040.cfg
 * gdb-multiarch ./zx_pico_if1_fw.elf
 *  target remote localhost:3333
 *  load
 *  monitor reset init
 *  continue
 */

#include <stdio.h>
#include <stdint.h>
#include <string.h>
#include <stdlib.h>
#include "pico/stdlib.h"
#include "hardware/gpio.h"
#include "pico/binary_info.h"
#include "hardware/timer.h"
#include "pico/multicore.h"


/* 1 instruction on the 133MHz microprocessor is 7.5ns */
/* 1 instruction on the 140MHz microprocessor is 7.1ns */
/* 1 instruction on the 150MHz microprocessor is 6.6ns */
/* 1 instruction on the 200MHz microprocessor is 5.0ns */

//#define OVERCLOCK 150000
//#define OVERCLOCK 270000

#include "roms.h"

const uint8_t LED_PIN = PICO_DEFAULT_LED_PIN;

/*
 * These pin values are the GPxx ones in green background on the pinout diagram.
 * See schematic for how the signals are fed into the Pico's GPIOs
 */
const uint8_t A0_GP          = 8;
const uint8_t A1_GP          = 9;
const uint8_t A2_GP          = 10;
const uint8_t A3_GP          = 11;
const uint8_t A4_GP          = 12;
const uint8_t A5_GP          = 13;
const uint8_t A6_GP          = 14;
const uint8_t A7_GP          = 15;
const uint8_t A8_GP          = 16;
const uint8_t A9_GP          = 17;
const uint8_t A10_GP         = 18;
const uint8_t A11_GP         = 19;
const uint8_t A12_GP         = 20;
const uint8_t A13_GP         = 21;

const uint8_t  D0_GP         = 0;
const uint8_t  D1_GP         = 1;
const uint8_t  D2_GP         = 2;
const uint8_t  D3_GP         = 3; 
const uint8_t  D4_GP         = 4;
const uint8_t  D5_GP         = 5;
const uint8_t  D6_GP         = 6;
const uint8_t  D7_GP         = 7;

const uint32_t  D0_BIT_MASK  = ((uint32_t)1 <<  D0_GP);
const uint32_t  D1_BIT_MASK  = ((uint32_t)1 <<  D1_GP);
const uint32_t  D2_BIT_MASK  = ((uint32_t)1 <<  D2_GP);
const uint32_t  D3_BIT_MASK  = ((uint32_t)1 <<  D3_GP);
const uint32_t  D4_BIT_MASK  = ((uint32_t)1 <<  D4_GP);
const uint32_t  D5_BIT_MASK  = ((uint32_t)1 <<  D5_GP);
const uint32_t  D6_BIT_MASK  = ((uint32_t)1 <<  D6_GP);
const uint32_t  D7_BIT_MASK  = ((uint32_t)1 <<  D7_GP);

/* Input from the logic which merges A14, A15 and MREQ, goes active on a ROM read */
const uint8_t  ROM_READ_GP              = 26;
const uint32_t ROM_READ_BIT_MASK        = ((uint32_t)1 << ROM_READ_GP);

/* Z80's M1 signal, needs to be merged into the IF1 paging logic */
const uint8_t  M1_GP                    = 22;
const uint32_t M1_INPUT_BIT_MASK        = ((uint32_t)1 << M1_GP);

/*
 * Output signal, goes to Pico2 (IO Pico) to tell it that one of the
 * IO ports it's interested in is on the address bus
 */
const uint8_t  IF1_PORT_ACTIVE_OUTPUT_GP = 27;

/* This pin triggers a transistor which shorts the Z80's /RESET to ground */
const uint8_t  PICO_RESET_Z80_GP        = 28;

const uint32_t DBUS_MASK     = ((uint32_t)1 << D0_GP) |
                               ((uint32_t)1 << D1_GP) |
                               ((uint32_t)1 << D2_GP) |
                               ((uint32_t)1 << D3_GP) |
                               ((uint32_t)1 << D4_GP) |
                               ((uint32_t)1 << D5_GP) |
                               ((uint32_t)1 << D6_GP) |
                               ((uint32_t)1 << D7_GP);

/* Start with the 1982 Sinclair Research ROM */
uint8_t *rom_image_ptr = __ROMs_48_original_rom;

/*
 * This is called by an alarm function. It lets the Z80 run by pulling the
 * Pico's controlling GPIO low
 */
int64_t start_z80_alarm_func( alarm_id_t id, void *user_data )
{
  /*
   * At power up the Z80 starts running, and with the Pico not yet booted
   * and able to get the Z80 into reset, the Z80 will cheerfully run what
   * are random instructions found in the noise on the data bus. If that
   * takes it to one of the "page IF1 in" addresses, the IF1 will be paged
   * in. So just to be absolutely sure, when the Pico is ready and the code
   * comes through here to start the Z80, ensure that the 48K ROM is in
   * place.
   */
  rom_image_ptr = __ROMs_48_original_rom;
  gpio_put(LED_PIN, 0);

  /* Don't need the timers anymore, no interrupts now */
  irq_set_mask_enabled( 0xFFFFFFFF, 0 );

  gpio_put( PICO_RESET_Z80_GP, 0 );
  return 0;
}

/* You'll need to crank up the overclock to 270MHz if this is turned on */
#define RECORDING 0
#if RECORDING

typedef struct _recorder
{
  uint32_t gpios;
  uint16_t address;
  uint8_t  response;
}
RECORDER;

#define RECORDER_SIZE 20000
#define RECORDER_RESET ((uint16_t)65535)

int32_t recorder_index=0;

/*
 * Print in debugger with
 *
 * (gdb) set max-value-size unlimited
 * (gdb) print -array on -array-indexes -elements 16384 -- /x address_recorder
 *
 * where 16384 is recorder_index
 */
RECORDER address_recorder[ RECORDER_SIZE ];

#endif


/*
 * Second core code, spins, watching the address bus. If one of the port values
 * which the IF1 is interested in appears on the lower address lines, set the
 * flag GPIO which tells the IO Pico it needs to pay attention.
 *
 * This can probably be moved to PIO if I need the core.
 */
void __time_critical_func(core1_main)( void )
{
  const uint32_t ABUS_MASK     =
    ((uint32_t)1 << A0_GP) |
    ((uint32_t)1 << A1_GP) |
    ((uint32_t)1 << A2_GP) |

    ((uint32_t)1 << A4_GP) |
    ((uint32_t)1 << A5_GP) |
    ((uint32_t)1 << A6_GP) |
    ((uint32_t)1 << A7_GP);

  const uint32_t IF1_PORT     =
    ((uint32_t)1 << A0_GP)   |
    ((uint32_t)1 << A1_GP)   |
    ((uint32_t)1 << A2_GP)   |

    ((uint32_t)0 << A4_GP)   |
    ((uint32_t)1 << A5_GP)   |
    ((uint32_t)1 << A6_GP)   |
    ((uint32_t)1 << A7_GP);

  /*
   * This is a basic loop which sets a GPIO low if the pattern
   * 1110x111 is on the lower address bus. That signals to the
   * IO Pico that the Z80 is addressing something that might
   * be one of the IF1's IO ports. The other Pico worries about
   * that extra bit, and the IORQ line, etc.
   * This is crude, but fast enough at 150MHz. It'd be good if I
   * could replace this with a PIO program. That would free up
   * this core again.
   */
  while(1)
  {
    register uint32_t gpios_state = gpio_get_all();

    /* If we're currently dealing with a ROM read then it's not an IO */
    if( (gpios_state & ROM_READ_BIT_MASK) == 0 )
    {
      gpio_put( IF1_PORT_ACTIVE_OUTPUT_GP, 1 );
      continue;
    }

    if( (gpios_state & ABUS_MASK) == IF1_PORT )
    {
      /* It's one of ours, signal to the other Pico */
      gpio_put( IF1_PORT_ACTIVE_OUTPUT_GP, 0 );
    }
    else
    {
      /* It's not one of ours, turn the signal off */
      gpio_put( IF1_PORT_ACTIVE_OUTPUT_GP, 1 );
    }
  }
}

int main()
{
  bi_decl(bi_program_description("ZX Spectrum Pico IF1 board binary."));

#ifdef OVERCLOCK
  set_sys_clock_khz( OVERCLOCK, 1 );
#endif

  /*
   * Set up Pico's Z80 reset pin, hold this at 0 to let Z80 run.
   * Set and hold 1 here to hold Spectrum in reset at startup until we're good
   * to provide its ROM
   */
  gpio_init( PICO_RESET_Z80_GP );  gpio_set_dir( PICO_RESET_Z80_GP, GPIO_OUT );
  gpio_put( PICO_RESET_Z80_GP, 1 );

  /* All interrupts off except the timers */
  irq_set_mask_enabled( 0xFFFFFFFF, 0 );
  irq_set_mask_enabled( 0x0000000F, 1 );

  /* Pull the buses to zeroes */
  gpio_init( A0_GP  ); gpio_set_dir( A0_GP,  GPIO_IN );  gpio_pull_down( A0_GP  );
  gpio_init( A1_GP  ); gpio_set_dir( A1_GP,  GPIO_IN );  gpio_pull_down( A1_GP  );
  gpio_init( A2_GP  ); gpio_set_dir( A2_GP,  GPIO_IN );  gpio_pull_down( A2_GP  );
  gpio_init( A3_GP  ); gpio_set_dir( A3_GP,  GPIO_IN );  gpio_pull_down( A3_GP  );
  gpio_init( A4_GP  ); gpio_set_dir( A4_GP,  GPIO_IN );  gpio_pull_down( A4_GP  );
  gpio_init( A5_GP  ); gpio_set_dir( A5_GP,  GPIO_IN );  gpio_pull_down( A5_GP  );
  gpio_init( A6_GP  ); gpio_set_dir( A6_GP,  GPIO_IN );  gpio_pull_down( A6_GP  );
  gpio_init( A7_GP  ); gpio_set_dir( A7_GP,  GPIO_IN );  gpio_pull_down( A7_GP  );
  gpio_init( A8_GP  ); gpio_set_dir( A8_GP,  GPIO_IN );  gpio_pull_down( A8_GP  );
  gpio_init( A9_GP  ); gpio_set_dir( A9_GP,  GPIO_IN );  gpio_pull_down( A9_GP  );
  gpio_init( A10_GP ); gpio_set_dir( A10_GP, GPIO_IN );  gpio_pull_down( A10_GP );
  gpio_init( A11_GP ); gpio_set_dir( A11_GP, GPIO_IN );  gpio_pull_down( A11_GP );
  gpio_init( A12_GP ); gpio_set_dir( A12_GP, GPIO_IN );  gpio_pull_down( A12_GP );
  gpio_init( A13_GP ); gpio_set_dir( A13_GP, GPIO_IN );  gpio_pull_down( A13_GP );

  gpio_init( D0_GP  ); gpio_set_dir( D0_GP,  GPIO_IN );
  gpio_init( D1_GP  ); gpio_set_dir( D1_GP,  GPIO_IN );
  gpio_init( D2_GP  ); gpio_set_dir( D2_GP,  GPIO_IN );
  gpio_init( D3_GP  ); gpio_set_dir( D3_GP,  GPIO_IN );
  gpio_init( D4_GP  ); gpio_set_dir( D4_GP,  GPIO_IN );
  gpio_init( D5_GP  ); gpio_set_dir( D5_GP,  GPIO_IN );
  gpio_init( D6_GP  ); gpio_set_dir( D6_GP,  GPIO_IN );
  gpio_init( D7_GP  ); gpio_set_dir( D7_GP,  GPIO_IN );

  /* Input from logic hardware, indicates the ROM is being read by the Z80 */
  gpio_init( ROM_READ_GP ); gpio_set_dir( ROM_READ_GP, GPIO_IN );
  gpio_pull_down( ROM_READ_GP );

  /* M1 signal input */
  gpio_init( M1_GP ); gpio_set_dir( M1_GP, GPIO_IN );
  gpio_pull_up( M1_GP );

  /* Blip LED to show we're running */
  gpio_init(LED_PIN);
  gpio_set_dir(LED_PIN, GPIO_OUT);
  int signal;
  for( signal=0; signal<2; signal++ )
  {
    gpio_put(LED_PIN, 1);
    busy_wait_us_32(250000);
    gpio_put(LED_PIN, 0);
    busy_wait_us_32(250000);
  }
  gpio_put(LED_PIN, 1);

  /*
   * Ready to go, give it a few milliseconds for this Pico code to get into
   * its main loop, then let the Z80 start
   */
  add_alarm_in_ms( 5, start_z80_alarm_func, NULL, 0 );

  /* Signal to the IO Pico that an IF1 port is on A0 to A7 (active low) */
  gpio_init( IF1_PORT_ACTIVE_OUTPUT_GP ); gpio_set_dir( IF1_PORT_ACTIVE_OUTPUT_GP, GPIO_OUT );
  gpio_put( IF1_PORT_ACTIVE_OUTPUT_GP, 1 );

  multicore_launch_core1( core1_main );

  gpio_set_dir_in_masked( DBUS_MASK );
  while(1)
  {
    register uint32_t gpios_state;

    /*
     * Spin while the hardware is saying at least one of A14, A15 and MREQ is 1.
     * ROM_READ is active low - if it's 1 then the ROM is not being read.
     */
    while( (gpios_state=gpio_get_all()) & ROM_READ_BIT_MASK );

    /*
     * Assume the address bus GPIOs are in sequence, so just shift
     * down and mask everything except the lowest 14 bits
     */
    register uint16_t rom_address = (gpios_state>>A0_GP) & 0x3FFF;

    register uint8_t rom_value = *(rom_image_ptr+rom_address);

    /*
     * This Pico is about to put a value on the data bus. The "ROM read" logic
     * hardware signal goes to Pico2 (the IO handling Pico) as well as this one.
     * The other Pico uses that (plus its own IORQ logic) to set the level
     * shifter for the data bus lines to Pico->ZX. This Pico doesn't need to
     * worry about the level shifter direction. So here, the Pico GPIOs are set
     * to outputs and the value asserted for the Z80 to collect
     */
    gpio_set_dir_out_masked( DBUS_MASK );
    gpio_put_masked( DBUS_MASK, rom_value );

    /*
     * Spin until the Z80 releases MREQ indicating the read is complete.
     * ROM_READ is active low - if it's 0 then the ROM is still being read.
     */
    while( (gpio_get_all() & ROM_READ_BIT_MASK) == 0 );

    /*
     * Set the data bus GPIOs back to inputs. The level shifter for the data
     * bus lines is switched back to ZX->Pico by the IO handling Pico
     */
    gpio_set_dir_in_masked( DBUS_MASK );

    /*
     * M1 active means that that was an instruction fetch the Z80 just did.
     * If it's one of the magic addresses, page the IF1 ROM
     */
    if( (gpios_state & M1_INPUT_BIT_MASK) == 0 )
    {
      if( (rom_address == 0x0008) || (rom_address == 0x1708) )
      {
	gpio_put(LED_PIN, 1);
	rom_image_ptr = __ROMs_if1_rom;
      }
      else if( rom_address == 0x0700 )
      {
	rom_image_ptr = __ROMs_48_original_rom;
	gpio_put(LED_PIN, 0);
      }
#if RECORDING
    /* Log to the recorder buffer the ROM address requested */
    if( (rom_image_ptr == __ROMs_if1_rom) && (recorder_index >=0) )
    {
      address_recorder[ recorder_index ].gpios    = gpios_state;
      address_recorder[ recorder_index ].address  = rom_address;
      address_recorder[ recorder_index ].response = unconverted_byte[ (uint8_t)rom_value ];
      if( ++recorder_index == RECORDER_SIZE )
      {
	recorder_index = 0;
      }
    }
#endif

    }


  } /* Infinite loop */

}



#if 0
/* Blip the result pin, shows on scope */
gpio_put( TEST_OUTPUT_GP, 1 ); busy_wait_us_32(5);
gpio_put( TEST_OUTPUT_GP, 0 ); busy_wait_us_32(5);

gpio_put( TEST_OUTPUT_GP, 1 ); busy_wait_us_32(1000);
gpio_put( TEST_OUTPUT_GP, 0 ); busy_wait_us_32(1000);
__asm volatile ("nop");
#endif

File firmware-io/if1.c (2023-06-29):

/*
 * ZX Pico IF1 Firmware, a Raspberry Pi Pico based ZX Interface One emulator
 * Copyright (C) 2023 Derek Fountain
 * Derived from the Fuse code:
 *    Copyright (c) 2004-2016 Gergely Szasz, Philip Kendall
 *    Copyright (c) 2015 Stuart Brady
 * 
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
 * You should have received a copy of the GNU General Public License
 * along with this program; if not, write to the Free Software
 * Foundation, Inc., 51 Franklin Street, Fifth Floor, Boston, MA  02110-1301, USA.
 */

#include <string.h>

#include "hardware/gpio.h"
#include "pico/platform.h"
#include "hardware/spi.h"

#include "cartridge.h"
#include "microdrive.h"
#include "if1.h"
#include "spi.h"

#define NO_ACTIVE_MICRODRIVE  ((microdrive_index_t)(-1))

/* This is used in the preamble */
enum
{
  SYNC_NO = 0,
  SYNC_OK = 0xff
};

/*
 * Microdrive structure, represents the drive ifself.
 */
typedef struct _microdrive_t
{
  bool    motor_on;
  int     head_pos;
  int     transfered;
  int     max_bytes;
  uint8_t pream[512];   /* preamble/sync area written. 256 header blocks and 256 data blocks */
  uint8_t last;
  uint8_t gap;
  uint8_t sync;

  /*
   * Offset in PSRAM to the byte array representing the tape, approx 97KB for a 180 sector
   * tape. About 135KB for a 254 sector tape.
   *
   * The following is obsolete because the external RAM can't be examined
   * directly using the debugger. Might be useful though:
   *
   * Copy and paste out to a text file with:
   *
   * (gdb) set print repeats 0
   * (gdb) set print elements unlimited
   * (gdb) set pagination off
   * (gdb) p/x cartridge_data
   * (gdb) set max-value-size unlimited
   *
   * Convert to MDR image with:
   *
   * > perl -ne 'map { print chr(hex($_)) } split(/, /, $_)' < mm_reformated_in_zx.txt > mm_reformated_in_zx.mdr
   *
   * mm_reformated_in_zx.mdr will then load into FUSE as a normal
   * MDR file.
   *
   */
  uint32_t cartridge_data_psram_offset;
  
  bool     cartridge_inserted;
  bool     cartridge_ejected_pending_save;
  bool     cartridge_data_modified;
  bool     cartridge_write_protect;
  uint8_t  cartridge_len_in_blocks;

} microdrive_t;


/*
 * These are the microdrives, typically 8 of them. This structure
 * keeps track of the data (in external PSRAM), motor, the head
 * position, gaps, preambles, things like that.
 */
static microdrive_t microdrive[NUM_MICRODRIVES];

/* Clock bit in the ULA */
static uint8_t if1_ula_comms_clk;

static void __time_critical_func(microdrives_restart)( void );


/* This can be used to blip a pin on the scope, sometimes gives a clue what's happening */
static void __time_critical_func(blip_test_pin)( void )
{
  extern const uint8_t TEST_OUTPUT_GP;
  gpio_put( TEST_OUTPUT_GP, 1 );
  __asm volatile ("nop");
  __asm volatile ("nop");
  __asm volatile ("nop");
  __asm volatile ("nop");
  gpio_put( TEST_OUTPUT_GP, 0 );
  __asm volatile ("nop");
  __asm volatile ("nop");
  __asm volatile ("nop");
  __asm volatile ("nop");
}


/*
 * Initialise Interface One structure. Create the 8 microdrive images.
 * All start off with no cartridge inserted.
 */
void if1_init( void )
{
  if1_ula_comms_clk = 0;

  for( microdrive_index_t m=0; m<NUM_MICRODRIVES; m++ )
  {
    microdrive[m].cartridge_inserted             = false;
    microdrive[m].cartridge_ejected_pending_save = false;
    microdrive[m].cartridge_data_modified        = false;
    microdrive[m].head_pos                       = 0;
    microdrive[m].motor_on                       = false;
    microdrive[m].gap                            = 15;
    microdrive[m].sync                           = 15;
    microdrive[m].transfered                     = 0;

    microdrive[m].cartridge_data_psram_offset    = 0;
    microdrive[m].cartridge_write_protect        = false;
    microdrive[m].cartridge_len_in_blocks        = 0;
  }

  return;
}


/*
 * "Insert" one of the tape images into the PSRAM buffer. The PSRAM buffer
 * is where the image will be read from and written to. The offset and
 * length given are assumed to point to a valid MDR image which has been
 * loaded into the PSRAM. If it hasn't, and what is there isn't a valid
 * MDR image, puzzling things will happen, much like if you put a cartridge
 * containing nonsense into a real microdrive.
 */
cartridge_error_t if1_mdr_insert( const microdrive_index_t which, const uint32_t psram_offset, const uint32_t length_in_bytes,
				  const write_protect_t write_protected )
{
  /*
   * We can't insert a new image if there's already one there, or the ejected
   * one hasn't yet been written out to SD card. In theory the UI won't request
   * a new insert until those conditions are sorted out.
   */
  if( microdrive[which].cartridge_inserted )
  {
    return CARTRIDGE_ERR_NEED_EJECT_BEFORE_INSERT;
  }

  if( microdrive[which].cartridge_ejected_pending_save )
  {
    return CARTRIDGE_ERR_NEED_SAVE_BEFORE_INSERT;
  }

  microdrive[which].cartridge_data_psram_offset = psram_offset;
  microdrive[which].cartridge_len_in_blocks     = (length_in_bytes / MICRODRIVE_BLOCK_LEN);
  microdrive[which].cartridge_write_protect     = write_protected;
  microdrive[which].cartridge_inserted          = true;

  /*
   * pream is 512 bytes in the microdrive_t structure. It's actually 2 256 byte
   * buffers, one to indicate the 256 header blocks are formatted, the other
   * to indicate the 256 data blocks are formatted.
   *
   * This is filling the 2 areas of the microdrive area's premable with SYNC_OK.
   * (We assume formatted a cartridge.)
   */
  for( size_t i = microdrive[which].cartridge_len_in_blocks; i > 0; i-- )
    microdrive[which].pream[255 + i] = microdrive[which].pream[i-1] = SYNC_OK;

  /*
   * Position ready to read a block. Probably redundant because the motor-on
   * code does it
   */
  microdrives_restart();

  trace(TRC_IMAGE_INIT, which);

  return CARTRIDGE_ERR_OK;
}


void if1_mdr_eject( const microdrive_index_t which )
{
  /* If no cartridge is inserted there's nothing to do */
  if( microdrive[which].cartridge_inserted )
  {
    /* Immediately mark as not inserted, no further writes will take place */
    microdrive[which].cartridge_inserted = false;

    /*
     * If the data has been modified the PSRAM image for this cartridge is currently
     * unique. It needs to be sent back to the UI Pico for saving on the SD card
     */
    if( microdrive[which].cartridge_data_modified )
    {
      microdrive[which].cartridge_ejected_pending_save = true;
    }
  }
}


/* Answers true if the drive has a cartridge inserted */
bool is_cartridge_inserted( microdrive_index_t which )
{
  return microdrive[which].cartridge_inserted;
}


/* Answers true if the drive has a modified cartridge */
bool is_cartridge_modified( microdrive_index_t which )
{
  return microdrive[which].cartridge_data_modified;
}


/* Sets/resets the cartridge modification flag */
void set_cartridge_modified( microdrive_index_t which, bool modified )
{
  microdrive[which].cartridge_data_modified = modified;
}
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

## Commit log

2023-02-06 initial, based on pico rom project
    [srom.kicad_pcb, srom.kicad_sch]
2023-02-09 add IO and UI schematics
    [io_pico.kicad_sch, srom.kicad_sch, ui.kicad_sch]
2023-02-11 schematics complete for IO and UI picos
    [io_pico.kicad_sch, srom.kicad_sch, ui.kicad_sch]
2023-02-12 first draft pcb layout
    [io_pico.kicad_sch, srom.kicad_pcb, srom.kicad_sch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]
2023-02-12 design rules checker happy
    [srom.kicad_pcb]
2023-02-12 ready for fab
    [srom.kicad_pcb, srom.kicad_sch]
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2023-02-22 fix 2222 transistor footprint on PCB
    [srom.kicad_pcb, srom.kicad_sch]
2023-02-28 first draft of board working as a ROM emulator
    [srom-B_Cu.gbl, srom-B_Mask.gbs, srom-B_Paste.gbp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]
2023-02-28 change the level shifter enabling from /CE to DIR as per original design for this board. confirm still works
2023-03-01 update schema and layout to match working ROM emulation board. 2 level shifters removed here
    [io_pico.kicad_sch, srom.kicad_pcb, srom.kicad_sch]
2023-03-01 v1.1, no fabrication of this, hand updated my original board. ROM emulation works
    [srom.kicad_pcb, srom.kicad_sch]
2023-03-01 break out the 3V3 supplies into separate ones
    [io_pico.kicad_sch, srom.kicad_pcb, srom.kicad_sch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]
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2023-03-02 correct result from a PRINT IN 223 sometimes appears from 2nd core
    [zx_pico_if1_io_fw.c]
2023-03-02 tidy up, bring code back to core0, still has first time failure issue
    [zx_pico_if1_io_fw.c]
2023-03-03 fix input byte bit shifting
    [zx_pico_if1_io_fw.c]
2023-03-03 rethink needed, the ROM DIR switch is time critical and one core can't do it all
2023-03-06 tidy up, test for IN/OUT port 231 works, but the initial failure is still there
    [zx_pico_if1_io_fw.c]
2023-03-07 fix found for initial run problem, remove test code
    [zx_pico_if1_io_fw.c]
2023-03-07 some of the FUSE microdrive code ported in, it compiles, this won't run and i haven't tried it
    [if1.c, zx_pico_if1_io_fw.c]
2023-03-08 control port works as far as lighting pico LED as the microdrive0 motor light
2023-03-08 CAT 1 now gives MD not found error, which is an improvement
    [if1.c, zx_pico_if1_io_fw.c]
2023-03-16 remove dual core stuff for now, tracing added to the rom emulator, remove cruft from IO emulator. CAT still broken
    [if1.c, zx_pico_if1_fw.c, zx_pico_if1_io_fw.c]
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2023-03-21 FORMAT and SAVE work, but only after a few attempts. timing issues, i currently assume
    [if1.c, zx_pico_if1_io_fw.c]
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2023-03-22 MREQ PIO tidied up, but MD now broken
    [zx_pico_if1_io_fw.c]
2023-03-22 moved write data code to core1, SAVE and FORMAT still not working
    [zx_pico_if1_io_fw.c]
2023-03-23 back to MM image, loads without copy to ram, format still broken
    [if1.c, zx_pico_if1_io_fw.c]
2023-03-24 use time critical macro to move functions into RAM. mm now loads correctly again
    [if1.c, zx_pico_if1_io_fw.c]
2023-03-26 comments, FORMAT still not working
    [if1.c, zx_pico_if1_io_fw.c]
2023-03-28 revert to 180 sector images for now
    [if1.c]
2023-03-28 first draft of multi-drive code. messy, save is broken. need to rethink this
    [if1.c]
2023-03-29 enable usb. doesn't really work, interrupts are the issue. worth keeping, will turn off again
    [zx_pico_if1_io_fw.c]
2023-03-29 bail out of USB printfs point. can't think of anything else to make it work
2023-03-29 broken multi-drive code, bits of usb, moved main to core1
    [if1.c, zx_pico_if1_io_fw.c]
2023-03-29 keep the stdio work, which might be useful even if it doesn't work ATM. keep the changes to move the main code into the second core
    [zx_pico_if1_io_fw.c]
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2023-03-30 removed the single md image, replaced with array of 8 currently identical ones
    [if1.c]
2023-03-31 basic saving back to flash on motor swap appears to work, testing needed. power cycle persistence not working
    [if1.c]
2023-04-03 add some tracing to the paging. it's far too slow, 600ms with /WAIT active. also fix hard power up issue
    [if1.c]
2023-04-04 use DMA to move cartridge image in from flash, makes little difference
2023-04-04 seems like the erratic startup issue was removing the blinking LED before the second core launch. no idea why. i added a 100ms pause, that seems to fix it too
    [if1.c, zx_pico_if1_io_fw.c]
2023-04-13 update schematic to match my modified prototype hardware
    [io_pico.kicad_sch, srom.kicad_sch]
2023-04-14 start v1.3 of board, level shifter required
    [io_pico.kicad_sch, srom.kicad_sch, ui.kicad_sch]
2023-04-14 move the ZXWAIT signal on pico2 off the SP1 connection. matches latest hardware
    [io_pico.kicad_sch, ui.kicad_sch]
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2023-04-15 update schematic to match current hardware
    [io_pico.kicad_sch, srom.kicad_sch]
2023-04-15 code and schematic match final hardware for board #1, time to have a new one built
    [io_pico.kicad_sch]
2023-04-16 move PIO init up so the ROM emulation works even if the SPI memory doesn't
    [zx_pico_if1_io_fw.c]
2023-04-16 remove address lines from pico2, replace with a signal from pico1, frees GPIOs on pico2
    [zx_pico_if1_fw.c, zx_pico_if1_io_fw.c]
2023-04-17 start updating schematic for next board
    [io_pico.kicad_sch, srom.kicad_sch, ui.kicad_sch]
2023-04-17 first draft of layout of board 2
    [io_pico.kicad_sch, srom.kicad_pcb, srom.kicad_sch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]
2023-04-17 more work on the layout of board 2
    [io_pico.kicad_sch, srom.kicad_pcb, srom.kicad_sch]
2023-04-18 v1.3 of the board off to production
    [io_pico.kicad_sch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]
2023-04-20 errata updates
    [io_pico.kicad_sch, srom.kicad_sch, ui.kicad_sch]
2023-04-20 attempt tracing to PSRAM, doesn't really work. will back out
    [if1.c, zx_pico_if1_fw.c, zx_pico_if1_io_fw.c]
2023-04-20 tracing back in a RAM buffer. hunt for FORMAT issue continues
    [if1.c, zx_pico_if1_fw.c, zx_pico_if1_io_fw.c]
2023-04-23 nailed the FORMAT issue, the last member of the microdrive structure, needs tidy up
    [if1.c, zx_pico_if1_fw.c, zx_pico_if1_io_fw.c]
2023-04-23 FORMAT bug finally nailed
    [if1.c, zx_pico_if1_fw.c, zx_pico_if1_io_fw.c]
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2023-05-05 message on OLED screen, fix needed on board
    [spi.h, zx_pico_if1_ui_fw.c]
2023-05-06 rotarty encoder working, connector is reversed, needs fixing
    [zx_pico_if1_ui_fw.c]
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2023-05-10 remove the page size idea, that won't work with variable MDR sizes. sort write protect out
    [if1.c, zx_pico_if1_io_fw.c, zx_pico_if1_ui_fw.c]
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2023-05-12 add the request status command, showed up a problem with high speed UART, slowed to 115200, can't work out what's going on
    [zx_pico_if1_io_fw.c, zx_pico_if1_ui_fw.c]
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2023-05-16 add SD card detect to hardware
    [io_pico.kicad_sch, srom.kicad_sch, ui.kicad_sch]
2023-05-17 update schematic to match UART comms and SD card detect
    [io_pico.kicad_sch, ui.kicad_sch]
2023-05-17 add some LEDs to schematic
    [io_pico.kicad_sch, srom.kicad_sch, ui.kicad_sch]
2023-05-18 sort out inverted text and boxes
    [oled_display.c]
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2023-05-19 break entry_fn bindings out from map
    [zx_pico_if1_ui_fw.c]
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2023-05-24 add 2 switches as buttons for the UI
    [io_pico.kicad_sch, srom.kicad_sch, ui.kicad_sch]
2023-05-25 gui for the eject function works, function itself doesn't
    [oled_display.c, zx_pico_if1_ui_fw.c]
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2023-06-11 update schematic, remove uart UI/IO link, replace with PIO link
    [io_pico.kicad_sch, ui.kicad_sch]
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2023-06-14 config file mechanism now in place, sample SD card image added
    [zxes_config.txt]
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2023-06-15 update errata, time to sort out the next iteration of the board
2023-06-17 add rear edge schematic, RUN switch, ROMCS2 signal
    [io_pico.kicad_sch, rear_edge.kicad_sch, srom.kicad_sch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]
2023-06-18 8 LEDs on UI Pico's GPIOs, 2 tested and working
    [srom.kicad_sch, ui.kicad_sch]
2023-06-18 design files for the top panel
    [top_panel.kicad_pcb, top_panel.kicad_sch]
2023-06-19 remove test point connectors, no needed on next board (famous last words)
    [io_pico.kicad_sch, srom.kicad_sch, ui.kicad_sch]
2023-06-20 first draft of daughterboard taking shape
    [srom.kicad_sch, ui.kicad_sch, ui_daughterboard.kicad_pcb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]
2023-06-22 board layout work, 4 layers
    [rear_edge.kicad_sch, srom.kicad_pcb, srom.kicad_sch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]
2023-06-22 board layout, across board tracks
    [srom.kicad_pcb]
2023-06-22 more work on the new pcb, i think i have the basic layout now
    [srom.kicad_pcb, ui.kicad_sch]
2023-06-22 layout has no rats nest and no errors
    [srom.kicad_pcb]
2023-06-23 clean ups, test points
    [srom.kicad_pcb]
2023-06-23 increase power track widths, more test points, silkscreen tweaks
    [srom.kicad_pcb]
2023-06-23 final pcb? about to copy layout for daughterboard
    [srom.kicad_pcb, ui.kicad_sch, ui_daughterboard.kicad_sch]
2023-06-25 lots more work to finalise the board pre-fab
    [srom.kicad_pcb, top_panel.kicad_pcb, ui_daughterboard.kicad_pcb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]
2023-06-25 v1.4 final, gerbers off for fabrication
    [srom-B_Cu.gbl, srom-B_Mask.gbs, srom-B_Paste.gbp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]
2023-06-28 add a basic error status system to the IO pico
    [if1.c, oled_display.c]
2023-06-30 more work on error handling
    [oled_display.c, zx_pico_if1_io_fw.c, zx_pico_if1_ui_fw.c]
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2023-07-04 fix the invert text issue, bit of a mess this ssd1306 code
    [oled_display.c]
2023-07-05 try to get consistency if the SD card isn't present. libs are buggy, this might not be perfect
    [oled_display.c, zx_pico_if1_ui_fw.c]
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2023-07-08 3d print lower case first design
    [lower_case.scad, lower_case.stl]
2023-07-13 new board tweaks, lower part of case pretty much done
    [lower_case.3mf, lower_case.scad, lower_case.stl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]
2023-07-14 more 3d print work, spacers
    [lower_case.scad, pcb_spacer.3mf, pcb_spacer.scad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]
2023-07-14 fix LED wiring sequence
    [zx_pico_if1_ui_fw.c]
2023-07-14 spacer for under the rotary encoder
    [rotary_spacer.3mf, rotary_spacer.scad, rotary_spacer.stl]
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2023-07-17 final case work, at least for now
    [lower_case.3mf, lower_case.scad, lower_case.stl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]
2023-07-18 added frame for the little screen
    [frame.scad, frame.stl]
2023-07-18 final 3d print bits
    [frame.scad, spectrum_riser.scad, spectrum_riser.stl]
2026-05-22 Start v1.5, update Kicad version, review errata
    [io_pico.kicad_sch, rear_edge.kicad_sch, srom.kicad_pcb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]

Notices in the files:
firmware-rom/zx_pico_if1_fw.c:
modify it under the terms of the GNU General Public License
